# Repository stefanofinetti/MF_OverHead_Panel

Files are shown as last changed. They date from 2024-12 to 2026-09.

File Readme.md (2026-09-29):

# Overhead Panel

A compact Airbus A319/320/321 overhead panel for MobiFlight: 3D-printed
panels and Korry-style push buttons, the boards that carry every switch,
light and display, and the firmware for its three OLED displays.

The panel covers **ADIRS**, **AIR COND**, **ANTI ICE**, **APU**, **ELEC**,
**EXT LT**, **FUEL**, **GPWS** and **SIGNS**.

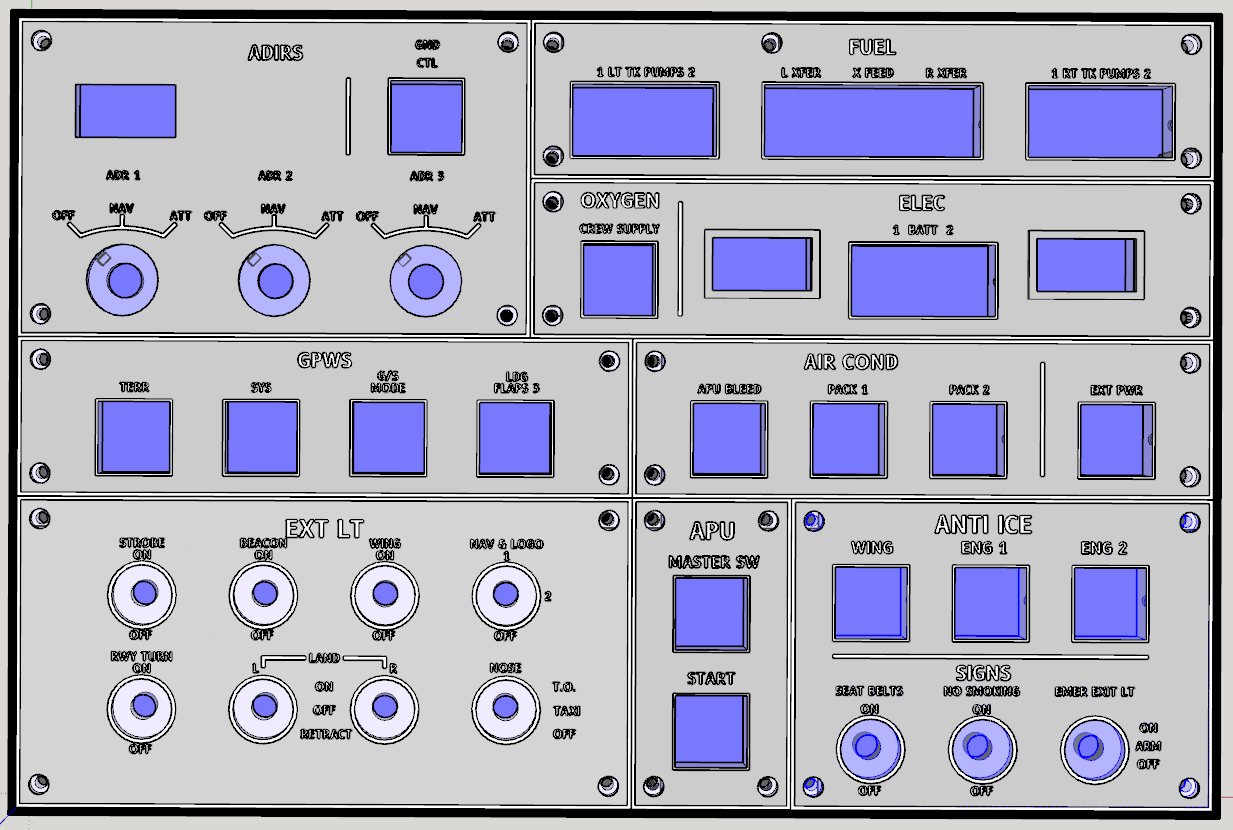
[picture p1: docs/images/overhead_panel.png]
The overhead panel as printed, from the 3D model


## v2 in short

v1 is one four-layer board, 313 × 206 mm, behind the whole panel. It works,
but it costs well over €100 once shipping and customs are added, and a
single mistake means reordering all of it.

v2 follows the printed panels instead: **eight small section boards, one
under each panel, and a 137 × 89 mm mainboard on the floor of the case**,
joined by ribbon cables. All nine are two-layer, 1.6 mm boards.

* **The printed parts do not change.** Panels, frames, Korry buttons and
  cases are the same. Only the floor of the lower-left case part is
  reprinted, with four bosses for the mainboard.
* **The section boards are cut out of the v1 layout.** Every switch, LED
  and hole stays at its v1 position, so each panel screws down exactly as
  before.
* **The pin map does not change.** Every switch is on the same ATmega pin
  and every annunciator on the same bit of the same shift-register chain,
  so the module config and the MobiFlight project stay valid. A few
  additions are listed under [Moving from v1](#moving-from-v1).

**Status (September 2026):** all nine boards are drawn and routed. ERC,
DRC and schematic parity are clean, and every ribbon and backlight pin was
checked against the board at the other end. **Nothing has been ordered or
built yet.** The firmware v2 needs is in `SF_OVHD` 1.2.0. The reprinted
case floor is still to do. v1 is the board that has been built and tested. It is
kept in `Kicad Files/` as the reference the v2 boards were cut from, **not
to be built**: build v2.

## What is in the repository

| Folder | What it holds |
|---|---|
| `Mainboard/` | The v2 mainboard: KiCad project, schematic (a root sheet and six sub-sheets) and routed PCB. See [its readme](Mainboard/README.md) |
| `Section_ADIRS/` … `Section_SIGNS/` | The eight v2 section boards, one KiCad project each, with a readme apiece |
| `Libraries/` | Parts shared by every v2 board: `OVHD.pretty` (Korry, toggle, ADR rotary, annunciator LED), `OVHD.kicad_sym`, and `3dmodels/` |
| `docs/board-split.md` | The v2 design document: decisions, power, annunciator currents, the ribbon pinouts, and why each choice was made |
| `SF_OVHD/` | The MobiFlight firmware and the installable Community package, with the module config for the panel. See [its readme](SF_OVHD/README.md) |
| `STL Files/` | Everything to print: one STL per filament colour for each panel, a ready `.3mf` for multi-colour printers, the Korry buttons and cases, the four case parts, the frames and the support |
| `STL Files/FaceDown_Printing/` | The APU panel redesigned to print face down. The other panels will follow |
| `STL Files/Levers/` | The exterior light levers and the paddle knobs |
| `3D Files/` | The SketchUp sources for the panel, the Korry buttons and the support |
| `Kicad Files/` | **v1**, for reference only: the single big board, as sent to JLCPCB on 3 March 2025. Do not build it |

`OverheadPanel.zip` is an older snapshot of `Kicad Files/` from January
2025, kept for reference.

## The boards

```
                        ┌─ ribbon ──► 8 section boards (switches, annunciators, backlight LEDs)
 9 V jack ─► mainboard ─┤
 USB-B    ─►            └─ 2 wires ─► 8 section boards (backlight, 9 V)
```

The mainboard carries every active part. The section boards carry only
their switches, LEDs and resistors, and the OLED sockets.

| Board | PCB (mm) | Switches | Annunciators | Backlight LEDs | Ribbon → mainboard | Backlight → mainboard |
|---|---|---|---|---|---|---|
| [ADIRS](Section_ADIRS/README.md) | 132.5 × 81.5 | 3 ADR rotaries, GND CTL | 1 | 18 | 20 pins → J701 | J601 |
| [FUEL](Section_FUEL/README.md) | 177.5 × 40 | 7 Korry | 14 | 14 | 26 pins → J702 | J602 |
| [ELEC](Section_ELEC/README.md) | 177.5 × 39.5 | 3 Korry | 5 | 10 | 20 pins → J703 | J603 |
| [GPWS](Section_GPWS/README.md) | 159.5 × 39 | 4 Korry | 6 | 9 | 14 pins → J704 | J604 |
| [AIR COND](Section_AIRCOND/README.md) | 150.5 × 39 | 4 Korry | 8 | 13 | 16 pins → J705 | J605 |
| [EXT LT](Section_EXTLT/README.md) | 159.5 × 79.5 | 8 toggles | — | 31 | 14 pins → J706 | J606 |
| [APU](Section_APU/README.md) | 39 × 79.5 | 2 Korry | 4 | 5 | 10 pins → J707 | J607 |
| [SIGNS](Section_SIGNS/README.md) | 108.5 × 79.5 | 3 Korry, 3 toggles | 6 | 22 | 16 pins → J708 | J608 |
| **Total** | | **49 inputs** | **44** | **122** | | |

The three OLEDs (BATT 1, BATT 2 on ELEC, ADIRS on ADIRS) plug into sockets
on their section boards, as on v1, and reach the mainboard through the
ribbon.

### The mainboard

137 × 89 mm, two layers, GND poured on both. The chips and connectors are on
top, and the small 1206 parts of the dense groups are underneath their chip.

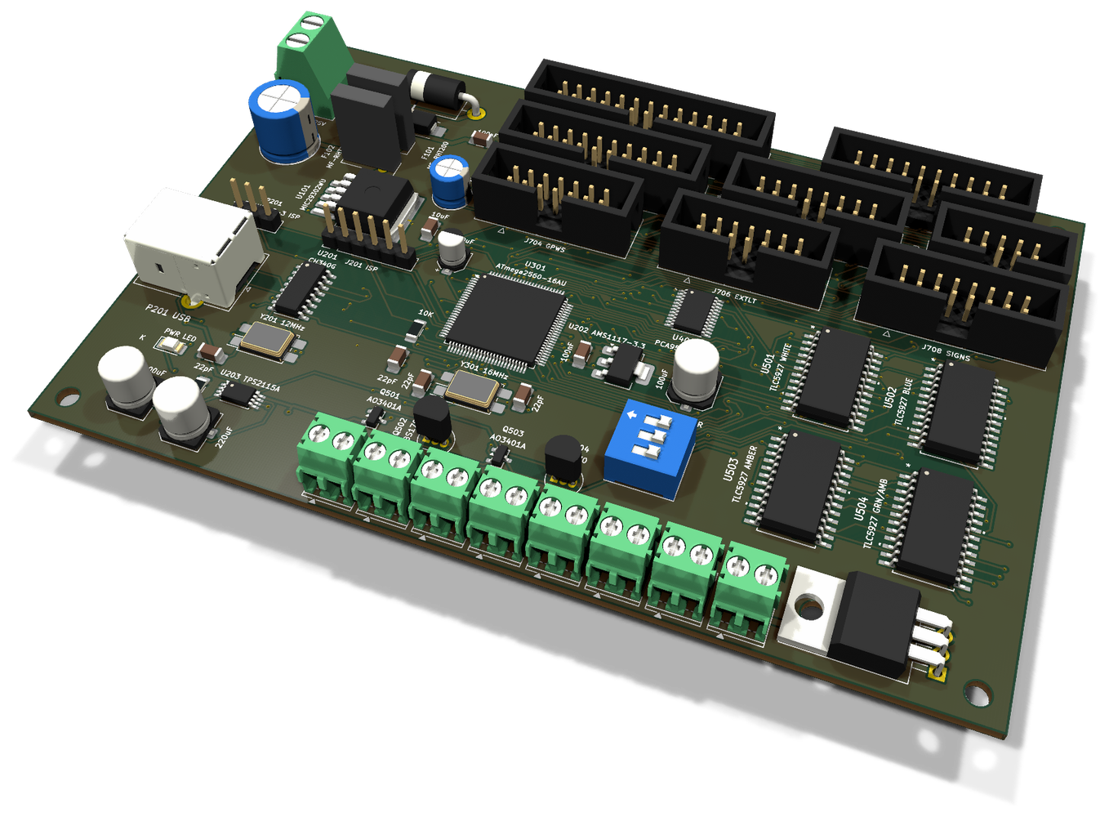
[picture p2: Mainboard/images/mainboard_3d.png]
The v2 mainboard, rendered by KiCad


* **Microcontroller:** ATmega2560 with a CH340G for USB. MobiFlight sees it
  as a Mega.
* **Power:** 9 V in through reverse protection, a TVS and a 470 µF bulk
  capacitor, then two resettable fuses, one for the backlight and one for
  the MIC29302 5 V regulator. A TPS2115A feeds the logic from that 5 V, or
  from USB when the 9 V is off. An AMS1117 makes 3.3 V for the PCA9548A
  and the OLEDs.
* **Annunciators:** four TI TLC5927 constant-current sinks, one per legend
  colour, in the two v1 chains (`ANN_LOWER`, `ANN_UPPER`). Each has a fixed
  1 kΩ on `R-EXT`, about 19 mA per LED. The trimmers of v1 are gone.
* **Three switches driven by the firmware:**
  * **D44:** backlight dimmer, an IRLIZ44N on the common return of the
    eight backlight branches;
  * **D45:** annunciator dimmer, on the LED anode rail;
  * **D46:** power to the four TLC5927, so they start clean however the
    9 V was plugged in.

  D44 and D45 undriven means dark.
* **Displays:** a PCA9548A I2C multiplexer at 0x71, channels 0–2 for
  BATT 1, BATT 2 and ADIRS.

### The section boards

* Every v1 part stays at its v1 coordinates. The new parts go on the
  **back**: the shrouded IDC header, the JST PH backlight connector and the
  few new resistors. Nothing new stands proud of the front.
* No ICs. The annunciator LEDs have no resistors, because the TLC5927 is a
  current sink.
* Backlight strings of two LEDs on 150 Ω, at 17 mA. Where the split leaves
  one LED alone (GPWS, AIR COND, EXT LT, APU), it gets 330 Ω for the same
  current.
* Each board sits in the middle of its A4 sheet. Its grid origin is set to
  where v1's (0, 0) lies, so KiCad shows v1 coordinates. The offset is in
  the title block.

## Building one

1. **Print** the panels, buttons, cases and frames from `STL Files/`.
2. **Reprint the floor of the lower-left case part** with four bosses and M3
   heat-set inserts for the mainboard. The mainboard's M3 holes are 4 mm in
   from its corners. The floor is free over 141 × 93.5 mm between the
   pillars. The reprinted floor is not drawn yet.
3. **Order the boards.** Run the Fabrication Toolkit plugin in each of the
   nine projects to make the Gerbers, BOM and positions. No v2 production
   files have been generated yet.
4. **Assemble.** Everything is sized for hand soldering: 1206 passives,
   7 × 5 mm crystals, generous spacing. Values, polarity, pin 1 and `K`
   marks are on the silkscreen of the side each part is on, so no
   schematic is needed at the bench. The per-board readmes list what to
   watch for.
5. **Cable it:**
   * one straight IDC ribbon per board, pin 1 to pin 1, from J1 on the
     section board to its J70x;
   * one pair of 22–24 AWG wires per board, from J2 (JST PH, `+` and `−` on
     the silkscreen) to its J60x screw terminal, pin 1 `+`;
   * the 9 V from a panel-mount 5.5 × 2.1 jack to J101 (pin 1 `+`);
   * USB through a panel-mount USB-B extension to P201.
6. **Burn the bootloader.** A new ATmega2560 is blank. J201 is an in-line
   ISP header: 1 VCC, 2 RESET, 3 MISO, 4 MOSI, 5 SCK, 6 GND. With JP201 on
   2–3, the programmer powers the MCU alone. Burn the Arduino Mega
   bootloader once, then put JP201 back on 1–2. From then on, the board is
   flashed over USB like a Mega.
7. **Install the firmware and the module config**, as described in
   [the firmware readme](SF_OVHD/README.md), then bind the switches and
   lights in your MobiFlight project.

A 9 V / 3 A adapter is enough. The backlight takes about 1.1 A, and a light
test with all 44 annunciators lit adds about 1 A.

## Moving from v1

The pin map is the same, so the v1 module config and project keep working,
with these changes:

* **Flash `SF_OVHD` 1.2.0 or later.** Its custom device powers the TLC5927
  up through D46 once the board has started. With older or stock MobiFlight
  firmware the annunciators stay dark on v2.
* **Load the module config from the 1.2.0 package.** It adds two PWM outputs,
  `BL_PWM` on D44 (backlight) and `ANN_PWM` on D45 (annunciators). D46 is not
  in it, because the custom device owns it.
* **Two new rows in the MobiFlight project** to drive them, typically INTEG
  LT for D44 and ANN LT BRT/DIM for D45. At 0, or with the Connector
  closed, the backlight and the annunciators are dark.
* **NO SMOKING:** v1 read it on the toggle's other contact, and the
  MobiFlight row was inverted to make up for it. v2 reads it like every
  other toggle, so **remove the inversion** on that row.

## Known issues

* **The ADIRS panel labels its rotaries in the wrong order.** The printed
  panel reads ADR 1, ADR 2, ADR 3 from left to right. On the A320 the order
  is IR 1, IR 3, IR 2, and that is how the board is wired, on v1 and v2
  alike: the middle rotary is IR 3 and the right one is IR 2. The `.mfmc`
  follows the board. Only the printed labels are wrong, so read the middle
  knob as 3 and the right one as 2 until the panel is reprinted.

## Software

* [KiCad](https://www.kicad.org/) 10, for the v2 boards. The files are
  saved by KiCad 10 and do not open in older versions
* [Freerouting](https://github.com/freerouting/freerouting), only to
  reroute a board
* [SketchUp](https://www.sketchup.com), to change the printed parts
* [VS Code](https://code.visualstudio.com/) with
  [PlatformIO](https://platformio.org/), to build the firmware
* [MobiFlight](https://www.mobiflight.com/)

```bash
git clone https://github.com/stefanofinetti/MF_OverHead_Panel.git
```

## License

This code and all the items are released under the GPLv3.0 license. Feel free
to use them as you wish, as long as you redistribute the source code.
A mention would be nice, though, if you use this work: I invested a good
many hours in it, just for the amazing MobiFlight community.

## Acknowledgements

This project couldn't have seen the light without the excellent work, and
kind support, of [GaGagu](https://github.com/gagagu) and
[ElRal](https://github.com/elral). Their work is amazing, so please have a
look at their repositories.

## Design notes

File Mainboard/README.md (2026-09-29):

# OVHD Mainboard (v2)

The v2 mainboard: the microcontroller, power, annunciator drivers and
display multiplexer for the whole overhead. It sits on the floor of the
lower-left case part and reaches the eight section boards through ribbons
and backlight wires. The reasoning behind every choice is in
[`docs/board-split.md`](../docs/board-split.md).

* **PCB:** 137 × 89 mm, 2 layers, 1.6 mm, GND poured on both sides.
* **Fixing:** four M3 holes, 4 mm in from the corners, for bosses with
  heat-set inserts in the reprinted case floor.
* **Parts:** 123. 65 of them are on the bottom.
* **Status:** routed with Freerouting. ERC, DRC (every warning on) and
  schematic parity are clean. Not yet ordered.

Mainboard, 3D view

**Top**, with the chips and connectors:

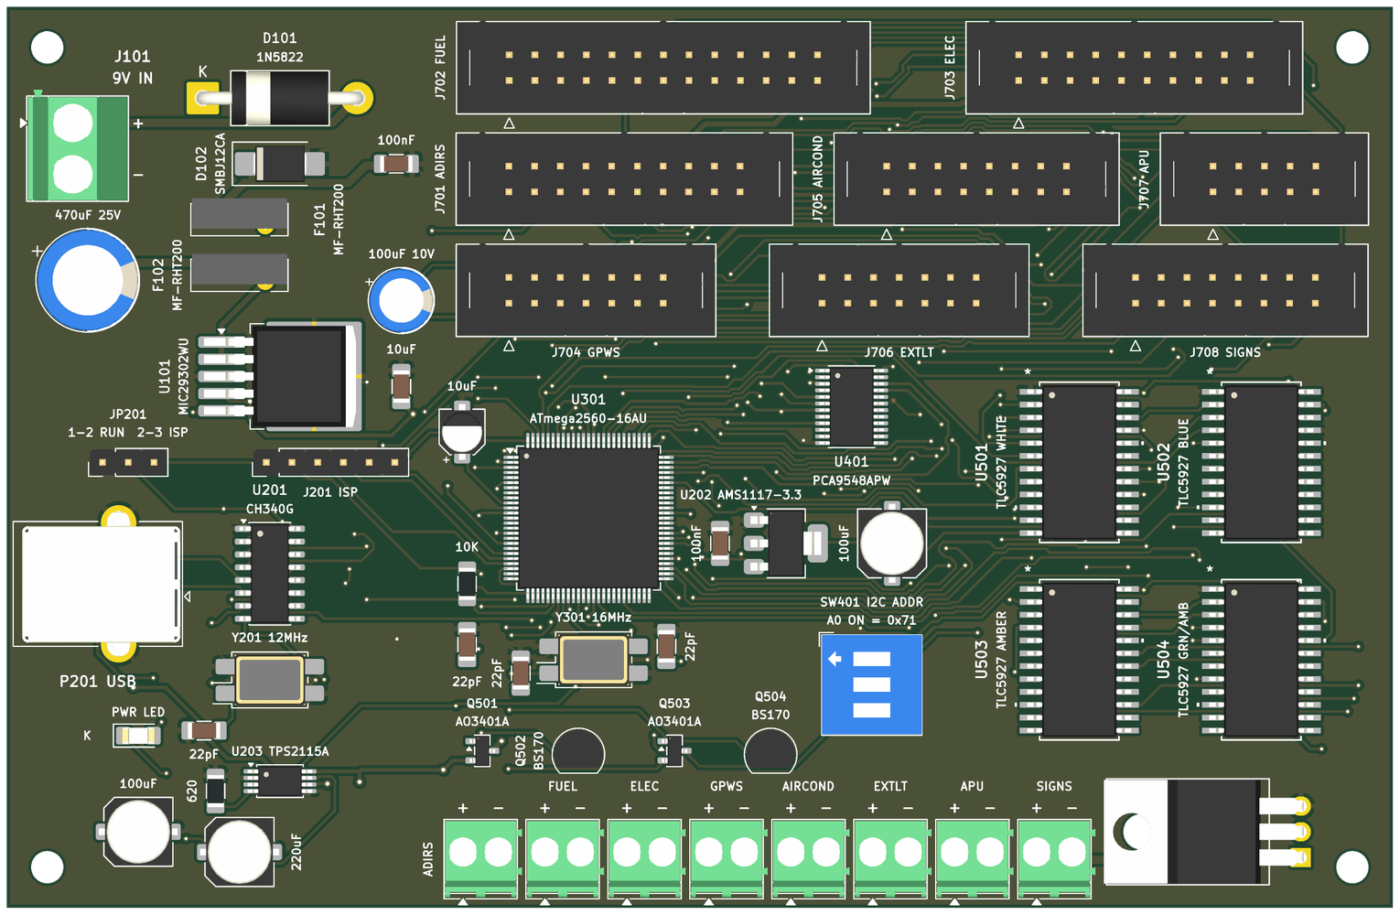
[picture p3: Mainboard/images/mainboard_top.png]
Mainboard, top


**Bottom**, with the small 1206 parts under their chips:

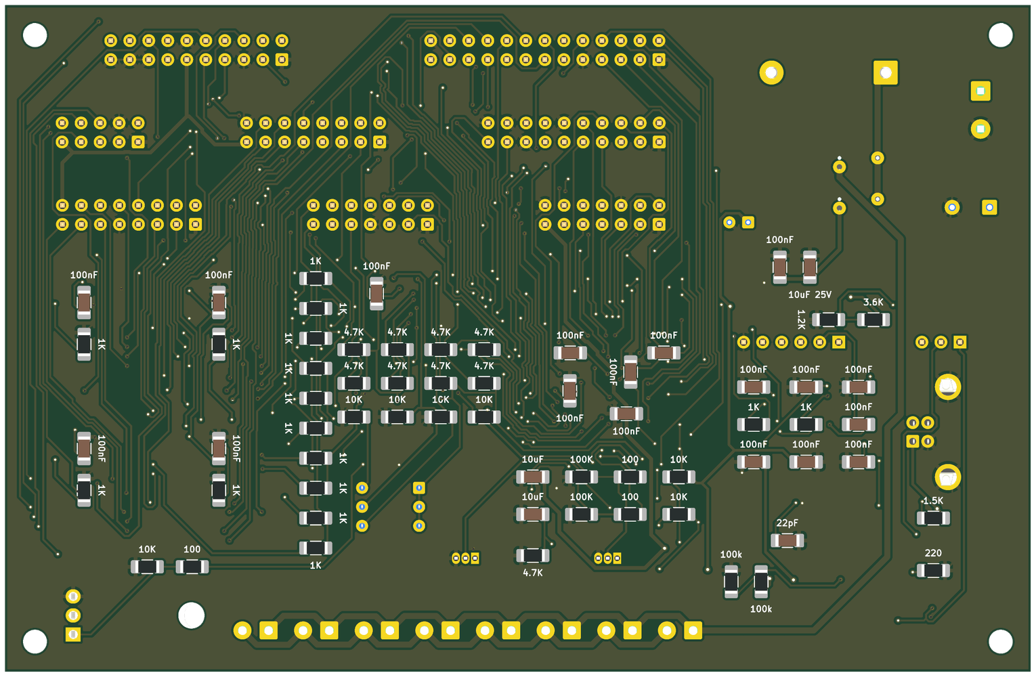
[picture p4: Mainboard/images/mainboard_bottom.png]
Mainboard, bottom


Rendered by KiCad from the board file. The bottom is seen from below, so it
is mirrored against the top.

## Schematic

| Sheet | What is on it |
|---|---|
| `power.kicad_sch` | 9 V in, reverse diode, TVS, bulk capacitor, the two fuses, MIC29302 (5 V) |
| `usb_supply.kicad_sch` | USB-B, CH340G, TPS2115A supply selector, AMS1117 (3.3 V), ISP header, JP201 |
| `mcu.kicad_sch` | ATmega2560, 16 MHz crystal, reset, decoupling |
| `i2c.kicad_sch` | PCA9548A, address switch, pull-ups |
| `annunciators.kicad_sch` | The four TLC5927, the anode dimmer (D45) and the TLC5927 supply switch (D46) |
| `connectors.kicad_sch` | The eight ribbon headers, the eight backlight terminals, the backlight dimmer (D44) |

Local libraries: `TLC5927.kicad_sym` / `TLC5927.pretty` and
`TPS2115A.kicad_sym`. Every part has a description field that says why it
is there and, where it replaces a v1 part, which one.

## Connectors and settings

| Ref | What | Notes |
|---|---|---|
| J101 | 9 V in, 5.08 mm screw terminal | From the panel-mount 5.5 × 2.1 jack. Pin 1 `+` |
| P201 | USB-B | To the panel-mount USB-B extension |
| J201 | ISP header, 1 × 6 | 1 VCC, 2 RESET, 3 MISO, 4 MOSI, 5 SCK, 6 GND |
| JP201 | Power selector | 1–2: MCU from the board's 5 V (normal use). 2–3: MCU from J201's VCC only, to burn the bootloader |
| SW401 | PCA9548A address | All off = 0x70. **Set A0 on: the board runs at 0x71**, which `SF_OVHD` expects |
| J701–J708 | Ribbons to ADIRS, FUEL, ELEC, GPWS, AIR COND, EXT LT, APU, SIGNS | Shrouded, keyed. Straight ribbon, pin 1 to pin 1. Each is labelled on the silkscreen with its board |
| J601–J608 | Backlight to the same eight boards, in the same order | 3.5 mm screw terminals. Pin 1 `+9V_BL`, pin 2 the switched return |

The pinout of every ribbon is in the design document, under *Ribbon
pinouts*.

## Annunciator drivers

| Ref | Colour | Chain and bits | v1 ref |
|---|---|---|---|
| U501 | white | `ANN_LOWER` 0–15 | U6 |
| U502 | blue | `ANN_LOWER` 16–31 | U7 |
| U503 | amber | `ANN_UPPER` 0–15 | U8 |
| U504 | green and amber | `ANN_UPPER` 16–31 | U5 |

`ANN_LOWER` has its latch on D23, clock on D24 and data on D22. `ANN_UPPER`
has its latch on D27, clock on D26 and data on D25, as on v1.

* **`R-EXT` is a fixed 1 kΩ (R501–R504):** I = 1.25 V / R × 15 ≈ 19 mA
  per LED. If you ever change it, stay between ~160 Ω and ~1.9 kΩ, the
  chip's range at power-up.
* **Nothing else on `R-EXT`,** above all no capacitor. On the v1 board a
  100 nF there made the chips drop their outputs as soon as two or three
  were on together. See the design document.
* **`OE` is tied hard to GND.** On the TLC5927 it is also the mode pin, so
  it must never get PWM.
* **1 kΩ in series on CLK, LE and SDI (R511–R520),** at the chips' end.

## Pins the firmware drives

| Pin | Drives | Undriven or low |
|---|---|---|
| D44 | Q601 (IRLIZ44N), the common return of the backlight | backlight off |
| D45 | Q501/Q502, the annunciator anode rail `+5V_LED` | annunciators dark |
| D46 | Q503/Q504, the TLC5927 supply | TLC5927 unpowered |

D44 and D45 are plain MobiFlight PWM outputs, `BL_PWM` and `ANN_PWM` in the
`.mfmc`. D46 belongs to the `SF_OVHD` custom device, from firmware 1.2.0. It
powers the chips up after the board has started, and again on message 5. See
[the firmware readme](../SF_OVHD/README.md#annunciator-power-up-d46).

## Assembly notes

* **Bottom side:** the 1206 parts of the dense groups, each under its chip:
  * the MCU and CH340G decoupling and crystal parts;
  * the I2C pull-ups;
  * the TLC5927 `R-EXT` resistors, VDD capacitors and series resistors;
  * the resistors of the three MOSFET switches;
  * the MIC29302 feedback divider and capacitors.

  Solder the bottom side first, then the top.
* **Q601** lies flat on its isolated tab. At ~1.1 A it needs no heatsink.
* **The polarity marks are on the silkscreen:** the electrolytics, the `K` at D101
  and at the power LED D201, and `+` and `−` at J101 and at every
  backlight terminal. D102 (SMBJ12CA) is bidirectional: it fits either way round.
* **Before flashing any firmware,** burn the bootloader through
  J201 with JP201 on 2–3, then move JP201 back to 1–2.

## Design rules

| Net class | Track | Clearance | Nets |
|---|---|---|---|
| HiCurrent | 0.8 mm | 0.3 mm | `VIN_RAW`, `+9V`, `+9V_BL`, `BL_RET` |
| Power | 0.5 mm | 0.25 mm | `+9V_REG`, `+5V_LED` |
| PowerNarrow | 0.35 mm | 0.2 mm | `5V_EXT`, `VBUS`, the widest that enters the TPS2115A's 0.65 mm pins |
| Default | 0.25 mm | 0.2 mm | everything else |

The minimum track is 0.15 mm, for a few escapes between TQFP and SOIC pins,
within JLCPCB's 0.127 mm.

## Mechanical

* The board is drawn in v1 coordinates, at x 32–169, y 134.5–223.5, under
  EXT LT and the lower edge of GPWS. That way it can be checked against the
  section boards above it.
* EXT LT's J1 and J2 hang over the TLC5927 block, where nothing is taller
  than a SOIC. No ribbon header sits under another board's connector.
* With today's case there are 27 mm from the floor to the underside of the
  section boards. The reprinted floor is meant to raise that to 30–35 mm.

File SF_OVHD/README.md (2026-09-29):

# SF OVHD — firmware

MobiFlight firmware for the overhead panel mainboard. It is standard
MobiFlight for the ATmega2560, plus one custom device, `SF_OVHD`. The custom
device does two things:

* it drives the three OLED displays: the BATT 1 and BATT 2 voltmeters and
  the ADIRS display;
* on the v2 mainboard, it powers up the four TLC5927 annunciator drivers,
  through D46, once the board has started. See
  [Annunciator power-up](#annunciator-power-up-d46).

The 49 switches and the annunciator lights do not go through the custom
device. They are plain MobiFlight buttons and output shifters, configured in
the Connector like on any other board. The two dimmers are plain MobiFlight
PWM outputs.

## Installing

1. Build the Community package `SF_OVHD_<version>.zip` as described
   below.
2. Extract it into the `Community` folder of your MobiFlight installation,
   so you end up with `Community\SF_OVHD\`. Restart the Connector.
3. Flash the board from the Connector. It shows up as **SF OVHD Mega**.
4. Load the module config `SF OVHD Mainboard.mfmc`, which comes with the
   package. It has every switch, both annunciator chains (`ANN_UPPER` and
   `ANN_LOWER`), the two dimmer outputs and the custom device at 0x71, on
   the pins the board uses.
5. In your MobiFlight project, bind the switches and annunciators to your
   aircraft, drive the two dimmers, and send the display values with the
   messages below.

## Dimmers

Two PWM outputs in the `.mfmc`, driven like any MobiFlight output with PWM
on, 0–255:

| Output | Pin | Dims | At 0, undriven or in power saving |
|---|---|---|---|
| `BL_PWM` | D44 | the backlight of the eight section boards (IRLIZ44N on their common return) | backlight off |
| `ANN_PWM` | D45 | the annunciators (AO3401A on their anode rail, `+5V_LED`) | annunciators dark |

Typically `BL_PWM` follows INTEG LT and `ANN_PWM` the ANN LT BRT/DIM
switch. **With neither bound, the backlight and the annunciators stay dark.**
They are on the v2 mainboard only; on v1, D44 and D45 are not connected.

## Messages

In the Connector, an output of type *Custom Device* on `SF OVHD` can send:

| ID | Label | Value |
|---|---|---|
| 0 | Battery 1 Voltage | shown as sent, e.g. `28.63` |
| 1 | Battery 2 Voltage | shown as sent |
| 2 | Adirs message | shown as text, e.g. `On Batt` |
| 3 | Light test | `1` shows the test picture on all three displays, `0` goes back to the values |
| 4 | Brightness | `0`–`100`, the contrast of all three displays |
| 5 | Reset annunciators | any value: the four TLC5927 lose their supply for 0.3 s, then both chains are written again. See [Annunciator power-up](#annunciator-power-up-d46) |

The Connector also sends two messages of its own. Both switch all three
displays off, since a picture left standing for hours burns into an OLED:

| ID | When |
|---|---|
| −1 | the Connector closes |
| −2 | the Connector enters power saving, after the 600 s set in the `.mfmc` |

The next value that arrives lights its display again.

A few details worth knowing:

* **An empty value blanks its display.** Use that for a display that
  should be dark, for instance while its bus is unpowered.
* **The voltages are right-aligned on the digit cells.** DSEG14 gives every
  digit a 32-pixel cell and the point none, so `28.80` fills the 128 pixels
  and `9.80` starts one cell in, with each digit in its usual column. Send
  them already formatted: the firmware prints what it gets.
* **Brightness** is meant for the ANN LT BRT/DIM switch, which dims these
  displays in the aircraft, or for a dimmer knob. Until the first value
  arrives, the displays keep their driver's default. An empty value is
  ignored. It sets the OLED contrast register: even at 0 the displays are
  dimmer but still plainly lit. After a new module config is uploaded, the
  displays start again at the default until the Connector sends the value
  once more.

## Annunciator power-up (D46)

The TLC5927 has no reset pin. On a hot-plugged 9 V supply it can start in a
bad state and keep it until its supply goes away. On the v2 mainboard the
chips' supply, `+5V_TLC`, goes through a switch on **D46** (`TLC_PWR_EN`):
high = powered. Undriven, the switch stays off, so the chips get no supply
until the firmware gives it.

When the custom device starts, which happens every time the board boots or a
module config is uploaded, it:

1. pulls CLK, LE and SDI of both chains (D22–D27) low. A CMOS input held
   high feeds an unpowered chip through its protection diode, and the core's
   output shifter leaves LE high after every update;
2. drives D46 low, so the chips are unpowered;
3. after 300 ms drives D46 high;
4. after another 20 ms writes both chains again, with what the Connector
   last set, or all dark in power saving.

Message 5 runs the same sequence on demand. It does not block the loop: the
steps run from the custom device's `update()`, every 10 ms
(`MF_CUSTOMDEVICE_HAS_UPDATE`, `MF_CUSTOMDEVICE_POLL_MS=10`). Annunciator
commands that arrive meanwhile are kept, and written once the chips are back.
The pins are fixed in `SF_OVHD/TLCSupply.cpp` and must match the `.mfmc`.

* **300 ms take the chips all the way to 0 V.** R527, 4.7 kΩ, bleeds the
  10.4 µF on `+5V_TLC`: a time constant of 49 ms, so after 300 ms about
  10 mV are left. The TLC5927 datasheet gives no reset threshold, so
  nothing shorter is relied on.
* **D46 is not in the `.mfmc`, and the package's `board.json` does not
  offer it,** so the Connector cannot give it to another device.
* **The Connector cannot bring the annunciators up with stock MobiFlight
  firmware** on v2. Nothing would drive D46.
* **On v1 the sequence is harmless:** D46 is not connected there, and the
  chains only see their lines held low for 0.3 s at startup.

## Displays and address

The three displays hang off a PCA9548A, one per channel:

| Channel | Display |
|---|---|
| 0 | BATT 1 |
| 1 | BATT 2 |
| 2 | ADIRS |

The channel numbers live in `SF_OVHD/SF_OVHD.h`.

The custom device's only setting is the address of the PCA9548A, set by the
DIP switch on the board: all off is 0x70. The address also picks the display
driver, which is easy to miss:

* **even** address (0x70, 0x72 …) → **SH1106**
* **odd** address (0x71, 0x73 …) → **SSD1306**

The board is configured at 0x71, i.e. SSD1306, and the shipped `.mfmc` is set
to match. With SH1106 displays, move the DIP switch to an even address and
change the custom device to match.

## Building

The project is PlatformIO, usually run from VS Code. The extension does not
put `pio` on the PATH. Either open a terminal from the PlatformIO toolbar, or
call it by its full path, `%USERPROFILE%\.platformio\penv\Scripts\pio.exe`.

```
pio run -e SF_OVHD_mega
```

That produces version `0.0.1`. For a real one, set `VERSION`. The build
stamps it into both the firmware filename and `board.json`, and the two have
to agree or MobiFlight will not find the firmware. It has to be an
environment variable, so the syntax differs per shell:

```
rem cmd.exe
rmdir /s /q _build _dist
set "VERSION=1.2.0" && pio run -e SF_OVHD_mega
```

```
# PowerShell
Remove-Item -Recurse -Force _build, _dist -ErrorAction SilentlyContinue
$env:VERSION = "1.2.0"; pio run -e SF_OVHD_mega
```

```
# bash
rm -rf _build _dist
VERSION=1.2.0 pio run -e SF_OVHD_mega
```

The result is the installable ZIP in `_dist/`.

Two traps:

* **Delete `_build` and `_dist` first.** `copy_fw_files.py` only stamps the
  version into `board.json` when `_build/` does not exist yet, so a leftover
  folder ships the previous version's json.
* **The ZIP is only rebuilt when the firmware recompiles.** After changing
  nothing but a file under `Community/`, run
  `pio run -e SF_OVHD_mega -t clean` first.

On the first build, `get_CoreFiles.py` clones the MobiFlight core into
`src/`, which is not in the repository.

## How it is put together

### What it follows

The reference is **MobiFlight's own scaffolding**: the project layout,
`platformio.ini`, the build scripts and `MFCustomDevice.*` follow
[MobiFlight/CommunityTemplate](https://github.com/MobiFlight/CommunityTemplate),
and `custom_core_firmware_version` is kept at the core release the template
points to, currently **3.1.4**. Where this project departs from the template:

| | |
|---|---|
| Device type | `SF_OVHD`. `SF_OVHD_MAINBOARD`, the January 2025 name, is accepted too, so a board configured back then keeps its displays |
| `SERIAL_RX_BUFFER_SIZE` | 256, not the template's 96, see below |
| Device families | buttons, output shifters and the custom device only |
| Targets | Mega only, the board has a soldered ATmega2560 |

### Serial receive buffer

Redrawing a display pushes a 1 KB frame over I2C at 400 kHz, about 25 ms
during which the loop reads nothing. At 115200 baud close to 300 bytes can
arrive in that window, so the template's 96-byte buffer would drop
characters. Do not lower it.

### Memory

The ATmega2560 has 8 KB of RAM, and MobiFlight reserves most of it up
front: 1600 bytes for the device arena (`MF_MAX_DEVICEMEM`) and 1000 for
the input names (`MEMLEN_NAMES_BUFFER`). Those two are sized for the
Connector config, not for this code, and are the wrong place to economise.

What this project does instead:

* **`build_unflags` turns off the device families the panel does not
  have**: segment displays, character LCD, steppers, servos, analog inputs,
  input shifters and both multiplexers. Output shifters stay on, because the
  annunciators are TLC5927 chains. Buttons, encoders and outputs are core
  and always present. To get a family back, delete its line in
  `SF_OVHD/sf_ovhd_platformio.ini`.
* **No `String` anywhere.** The values from the Connector live in fixed
  buffers, so a redraw allocates nothing and the heap cannot fragment. The
  only allocation in the whole firmware is Adafruit's 1 KB frame buffer,
  taken once at startup.

The result uses about 50% of the RAM and 16% of the flash.

### Files

| File | |
|---|---|
| `SF_OVHD/SF_OVHD.cpp`, `.h` | the three displays: drawing, messages, channels |
| `SF_OVHD/TLCSupply.cpp`, `.h` | the TLC5927 power-up on D46 |
| `SF_OVHD/OLEDInterface.h` | one interface over the SSD1306 and SH1106 drivers |
| `SF_OVHD/MFCustomDevice.cpp`, `.h` | the glue to the MobiFlight core, as in the template |
| `SF_OVHD/Fonts/` | GFX fonts. Two are used, DSEG14 Modern 20 pt and, from Adafruit GFX, FreeSans 18 pt |
| `SF_OVHD/Community/` | what goes into the package: board, device, module config, reset image |

## Credits

`OLEDInterface.h` and the fonts come from Gagagu's
[A320 EFIS/FCU display](https://github.com/gagagu/Mobiflight-A320-Efis-Fcu-Display-with-ESP32)
by way of [elral/MF_FCU_EFIS_OLEDs](https://github.com/elral/MF_FCU_EFIS_OLEDs),
the same base as the SF FCU firmware. The DSEG fonts are
[keshikan/DSEG](https://github.com/keshikan/DSEG). It could not have been
done without them.

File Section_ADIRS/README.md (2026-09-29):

# ADIRS section board (v2)

The v2 board under the ADIRS panel. It carries the panel's switches, annunciator LEDs and backlight, at their v1 positions, and reaches the mainboard through one ribbon and one pair of backlight wires. There are no ICs on it. The design rules shared by the eight section boards are in [`docs/board-split.md`](../docs/board-split.md).

* **PCB:** 132.5 × 81.5 mm, 2 layers, 1.6 mm. Every v1 hole is kept.
* **Status:** routed with Freerouting. ERC, DRC and schematic parity are clean. Not yet ordered.

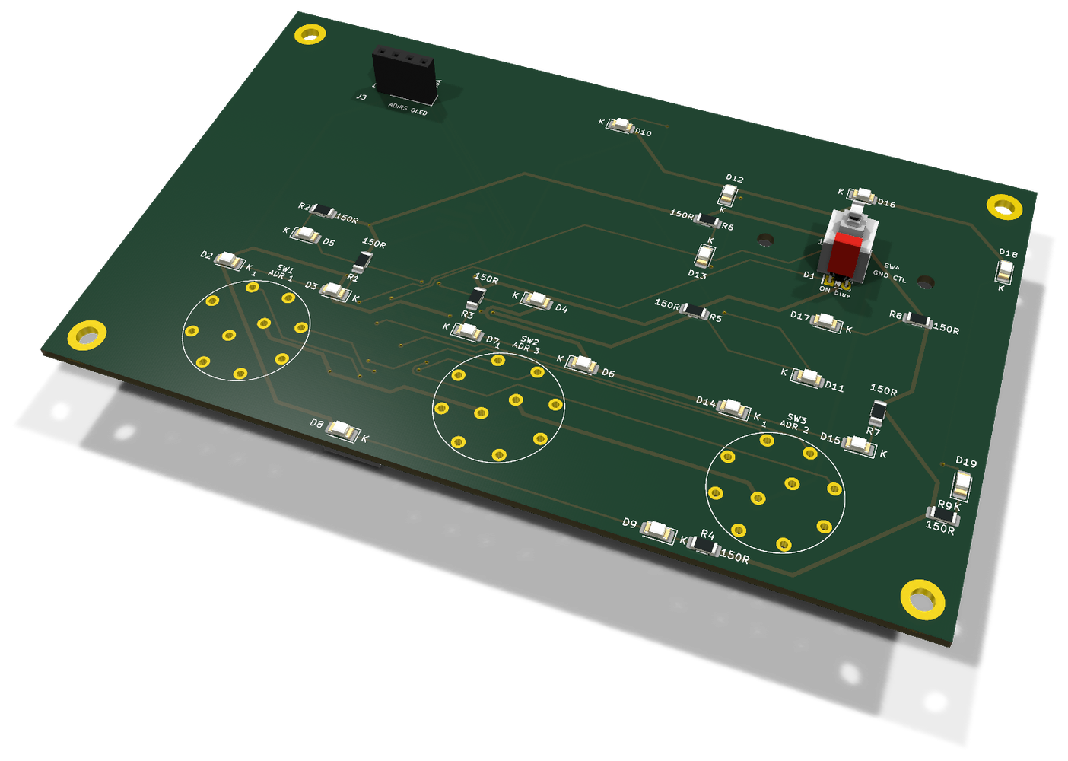
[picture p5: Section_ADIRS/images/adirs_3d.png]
ADIRS board, 3D view


**Top**, the panel side:

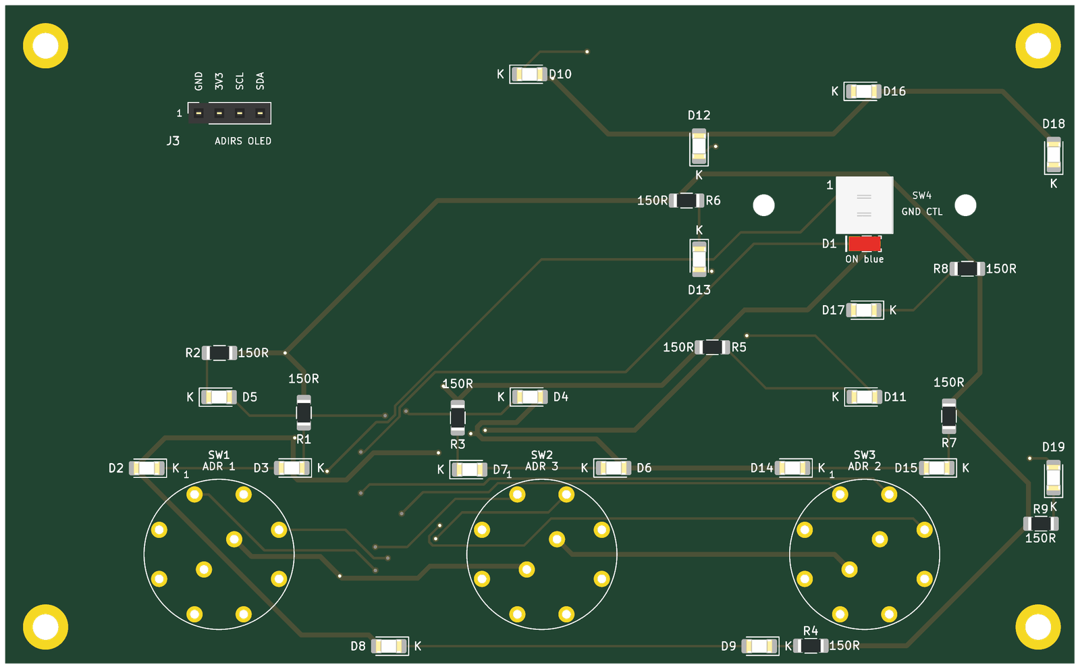
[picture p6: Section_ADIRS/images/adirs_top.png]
ADIRS, top


**Bottom**, with the connectors:

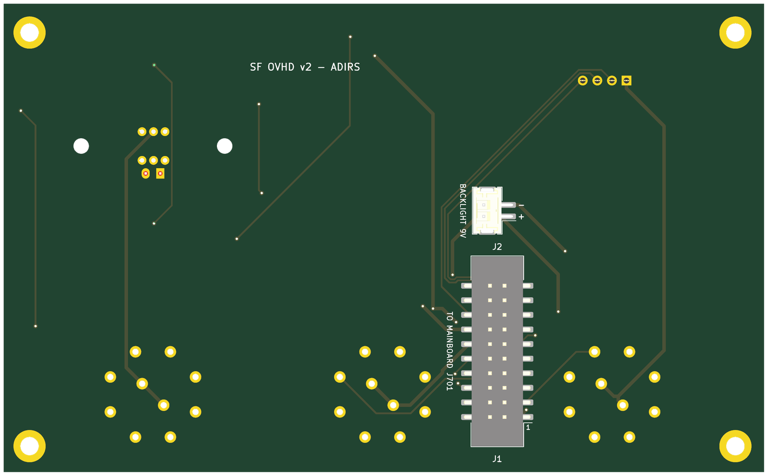
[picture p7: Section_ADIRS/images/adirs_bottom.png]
ADIRS, bottom


Rendered by KiCad from the board file. The bottom is seen from below, so it is mirrored against the top. The ADR rotaries have no 3D model yet and show as pads only.

## Connectors

Both are new on v2 and sit on the **back**, so nothing new stands proud of the front.

| Ref | What | Goes to |
|---|---|---|
| J1 | Shrouded IDC header, 20 pins, SMD | J701 on the mainboard, straight ribbon, pin 1 to pin 1 |
| J2 | JST PH, 2 pins, SMD. Pin 1 `+9V_BL` (`+`), pin 2 the switched return (`−`) | screw terminal J601 on the mainboard |

J1 and J2 are on the back between ADR 1 and ADR 3.

The signal on every ribbon pin is in the design document: [ADIRS — 20 pins](../docs/board-split.md#adirs--20-pins).

## Switches

| Ref | Switch | Type | v1 ref |
|---|---|---|---|
| SW1 | ADIRS ADR 1 | ADR rotary | SW25 |
| SW2 | ADIRS ADR 3 | ADR rotary | SW26 |
| SW3 | ADIRS ADR 2 | ADR rotary | SW27 |
| SW4 | ADIRS GND CTL | Korry | SW24 |

## Annunciators

Anodes on `+5V_LED` from the ribbon, cathodes back down the ribbon to their TLC5927 output. No resistors: the TLC5927 sets the current.

| Ref | Colour | Legend | Chain bit | Driver | v1 ref |
|---|---|---|---|---|---|
| D1 | blue | `GND_CTL_ON` | `ANN_LOWER` 16 | U502 (v1 U7) | D109 |

## Backlight

18 LEDs, 1206 (D2–D19), on 9 V, in 9 strings of two with 150 Ω (R1–R9). Each string runs at about 17 mA. `K` marks every cathode on the silkscreen.

## Assembly notes

* **SW2, in the middle, is IR 3, and SW3, on the right, is IR 2**, as on the A320 (IR 1, IR 3, IR 2 from left to right) and in the `.mfmc`. The v1 footprints were labelled the other way round; the copper decides.
* Rotary positions: 1 OFF, 2 NAV, 3 ATT; common on pin 9, to GND.
* J3 is the ADIRS OLED socket, where it was on v1: 1 GND, 2 +3V3, 3 SCL, 4 SDA, on PCA9548A channel 2.
* GND CTL is on this board because that is where it sits under the printed panel.
* There is no 3D model of the ADR rotary yet, so the render shows only its pads.
* Every part has its value, polarity or pin 1 on the silkscreen of its own side. Each part's description in the schematic names its v1 reference.

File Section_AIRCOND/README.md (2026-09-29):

# AIR COND section board (v2)

The v2 board under the AIR COND panel. It carries the panel's switches, annunciator LEDs and backlight, at their v1 positions, and reaches the mainboard through one ribbon and one pair of backlight wires. There are no ICs on it. The design rules shared by the eight section boards are in [`docs/board-split.md`](../docs/board-split.md).

* **PCB:** 150.5 × 39 mm, 2 layers, 1.6 mm. Every v1 hole is kept.
* **Status:** routed with Freerouting. ERC, DRC and schematic parity are clean. Not yet ordered.

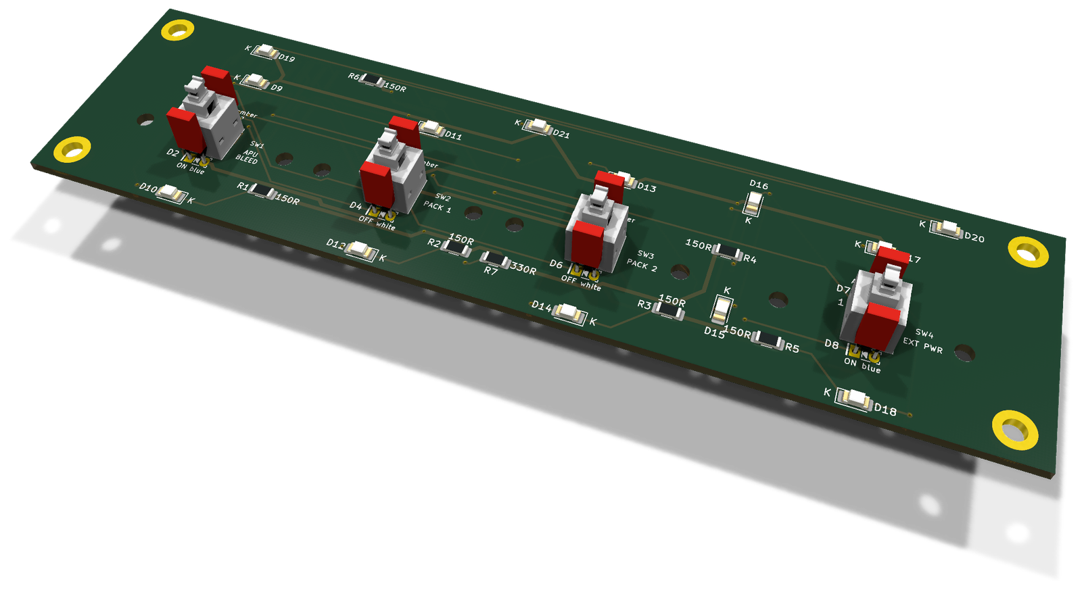
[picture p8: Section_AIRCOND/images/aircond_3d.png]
AIR COND board, 3D view


**Top**, the panel side:

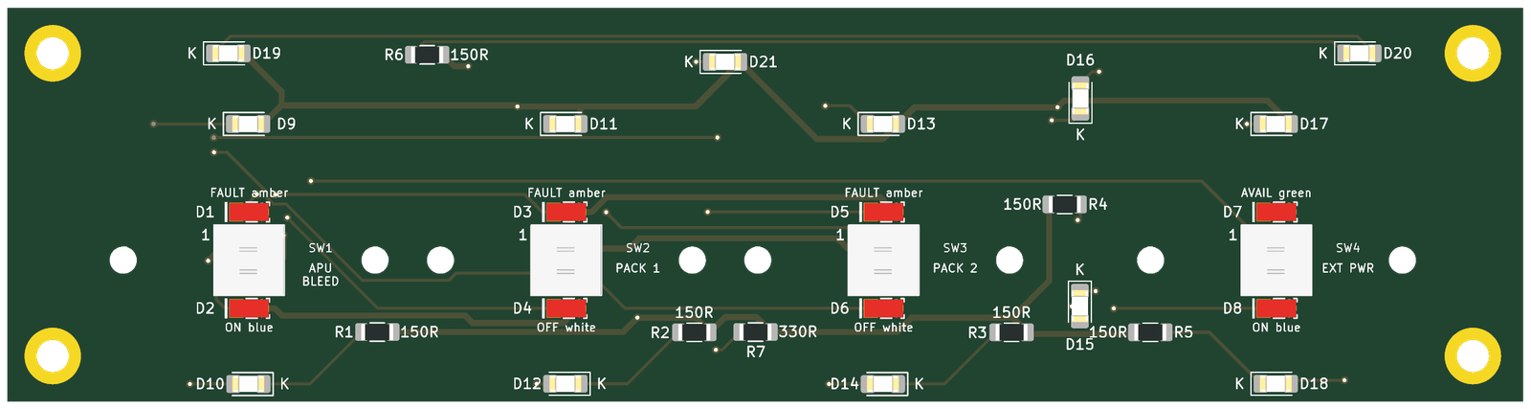
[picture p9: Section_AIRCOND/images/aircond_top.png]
AIR COND, top


**Bottom**, with the connectors:

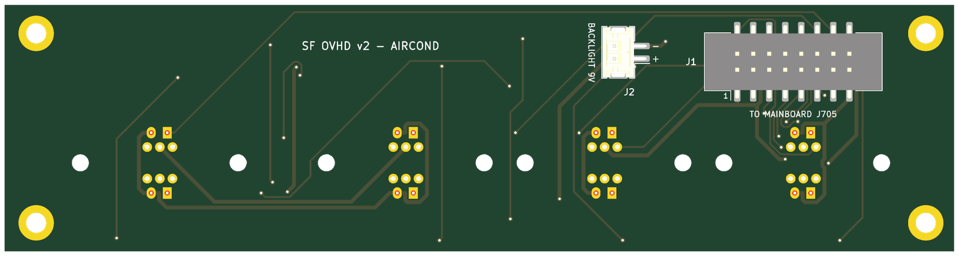
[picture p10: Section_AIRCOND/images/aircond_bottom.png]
AIR COND, bottom


Rendered by KiCad from the board file. The bottom is seen from below, so it is mirrored against the top.

## Connectors

Both are new on v2 and sit on the **back**, so nothing new stands proud of the front.

| Ref | What | Goes to |
|---|---|---|
| J1 | Shrouded IDC header, 16 pins, SMD | J705 on the mainboard, straight ribbon, pin 1 to pin 1 |
| J2 | JST PH, 2 pins, SMD. Pin 1 `+9V_BL` (`+`), pin 2 the switched return (`−`) | screw terminal J605 on the mainboard |

J1 and J2 are along the top edge on the left, the side nearest the mainboard.

The signal on every ribbon pin is in the design document: [AIR COND — 16 pins](../docs/board-split.md#air-cond--16-pins).

## Switches

| Ref | Switch | Type | v1 ref |
|---|---|---|---|
| SW1 | AIRCOND APU BLEED | Korry | SW10 |
| SW2 | AIRCOND PACK 1 | Korry | SW11 |
| SW3 | AIRCOND PACK 2 | Korry | SW12 |
| SW4 | AIRCOND EXT PWR | Korry | SW13 |

## Annunciators

Anodes on `+5V_LED` from the ribbon, cathodes back down the ribbon to their TLC5927 output. No resistors: the TLC5927 sets the current.

| Ref | Colour | Legend | Chain bit | Driver | v1 ref |
|---|---|---|---|---|---|
| D1 | amber | `APU_BLEED_FAULT` | `ANN_UPPER` 29 | U504 (v1 U5) | D87 |
| D2 | blue | `APU_BLEED_ON` | `ANN_LOWER` 25 | U502 (v1 U7) | D129 |
| D3 | amber | `PACK1_FAULT` | `ANN_UPPER` 30 | U504 (v1 U5) | D89 |
| D4 | white | `PACK1_OFF` | `ANN_LOWER` 8 | U501 (v1 U6) | D90 |
| D5 | amber | `PACK2_FAULT` | `ANN_UPPER` 31 | U504 (v1 U5) | D91 |
| D6 | white | `PACK2_OFF` | `ANN_LOWER` 12 | U501 (v1 U6) | D92 |
| D7 | green | `EXT_PWR_AVAIL` | `ANN_UPPER` 19 | U504 (v1 U5) | D99 |
| D8 | blue | `EXT_PWR_ON` | `ANN_LOWER` 21 | U502 (v1 U7) | D126 |

## Backlight

13 LEDs, 1206 (D9–D21), on 9 V: 6 strings of two with 150 Ω, and one single LED with R7, 330 Ω. Each string runs at about 17 mA. `K` marks every cathode on the silkscreen.

## Assembly notes

* D21 is a single-LED string: on v1 it was paired with D141, now on SIGNS. Its resistor R7 (v1 R76) stays where it was, but is **330 Ω, not 150 Ω**.
* EXT PWR is on this board because that is where it sits under the printed panel.
* v1 R57, which sat on this side of the seam, belongs to an ELEC string and has moved there.
* Every part has its value, polarity or pin 1 on the silkscreen of its own side. Each part's description in the schematic names its v1 reference.

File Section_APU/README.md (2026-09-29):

# APU section board (v2)

The v2 board under the APU panel. It carries the panel's switches, annunciator LEDs and backlight, at their v1 positions, and reaches the mainboard through one ribbon and one pair of backlight wires. There are no ICs on it. The design rules shared by the eight section boards are in [`docs/board-split.md`](../docs/board-split.md).

* **PCB:** 39 × 79.5 mm, 2 layers, 1.6 mm. Every v1 hole is kept.
* **Status:** routed with Freerouting. ERC, DRC and schematic parity are clean. Not yet ordered.

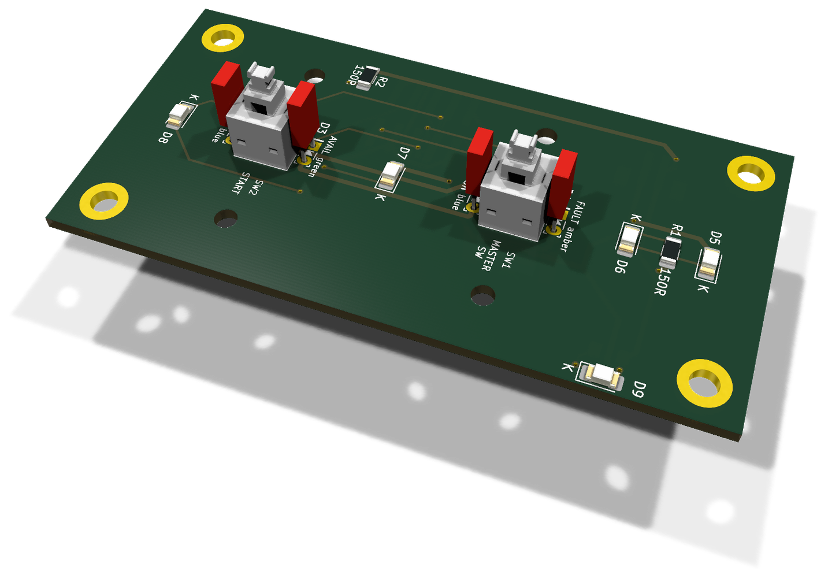
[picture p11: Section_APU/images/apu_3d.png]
APU board, 3D view


| Top: the panel side | Bottom: the connectors |
|---|---|
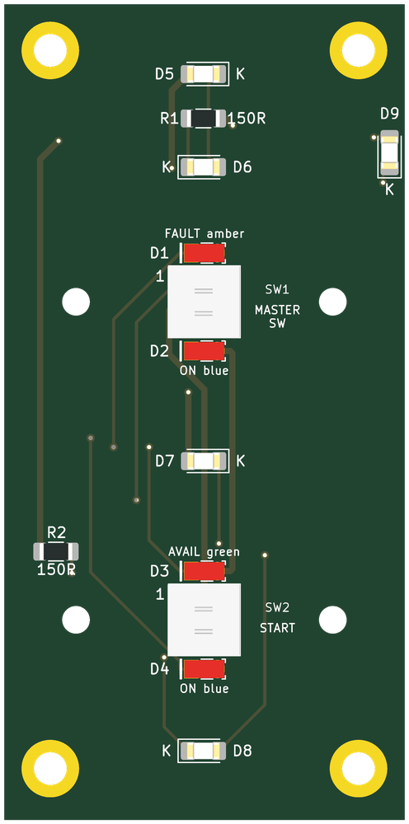
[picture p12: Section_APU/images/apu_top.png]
APU, top
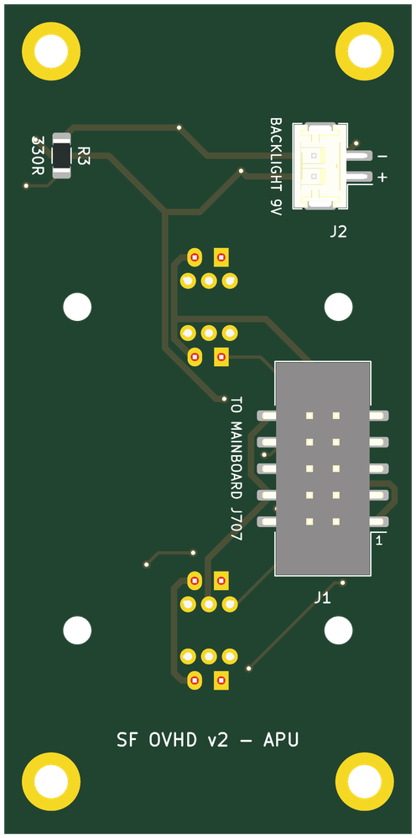
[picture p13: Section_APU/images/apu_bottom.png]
APU, bottom
|  |  |

Rendered by KiCad from the board file. The bottom is seen from below, so it is mirrored against the top.

## Connectors

Both are new on v2 and sit on the **back**, so nothing new stands proud of the front.

| Ref | What | Goes to |
|---|---|---|
| J1 | Shrouded IDC header, 10 pins, SMD | J707 on the mainboard, straight ribbon, pin 1 to pin 1 |
| J2 | JST PH, 2 pins, SMD. Pin 1 `+9V_BL` (`+`), pin 2 the switched return (`−`) | screw terminal J607 on the mainboard |

J1 and J2 are on the left edge, towards the mainboard.

The signal on every ribbon pin is in the design document: [APU — 10 pins](../docs/board-split.md#apu--10-pins).

## Switches

| Ref | Switch | Type | v1 ref |
|---|---|---|---|
| SW1 | APU MASTER SW | Korry | SW1 |
| SW2 | APU START | Korry | SW2 |

## Annunciators

Anodes on `+5V_LED` from the ribbon, cathodes back down the ribbon to their TLC5927 output. No resistors: the TLC5927 sets the current.

| Ref | Colour | Legend | Chain bit | Driver | v1 ref |
|---|---|---|---|---|---|
| D1 | amber | `APU_MASTER_FAULT` | `ANN_UPPER` 23 | U504 (v1 U5) | D178 |
| D2 | blue | `APU_MASTER_ON` | `ANN_LOWER` 17 | U502 (v1 U7) | D130 |
| D3 | green | `APU_AVAIL` | `ANN_UPPER` 24 | U504 (v1 U5) | D128 |
| D4 | blue | `APU_START_ON` | `ANN_LOWER` 24 | U502 (v1 U7) | D4 |

## Backlight

5 LEDs, 1206 (D5–D9), on 9 V: 2 strings of two with 150 Ω, and one single LED with R3, 330 Ω. Each string runs at about 17 mA. `K` marks every cathode on the silkscreen.

## Assembly notes

* D9 is a single-LED string: on v1 it was paired with D149, now on SIGNS. R3, 330 Ω on the back, gives it the same 17 mA as a pair on 150 Ω.
* Every part has its value, polarity or pin 1 on the silkscreen of its own side. Each part's description in the schematic names its v1 reference.

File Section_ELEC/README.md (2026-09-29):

# ELEC section board (v2)

The v2 board under the ELEC panel. It carries the panel's switches, annunciator LEDs and backlight, at their v1 positions, and reaches the mainboard through one ribbon and one pair of backlight wires. There are no ICs on it. The design rules shared by the eight section boards are in [`docs/board-split.md`](../docs/board-split.md).

* **PCB:** 177.5 × 39.5 mm, 2 layers, 1.6 mm. Every v1 hole is kept.
* **Status:** routed with Freerouting. ERC, DRC and schematic parity are clean. Not yet ordered.

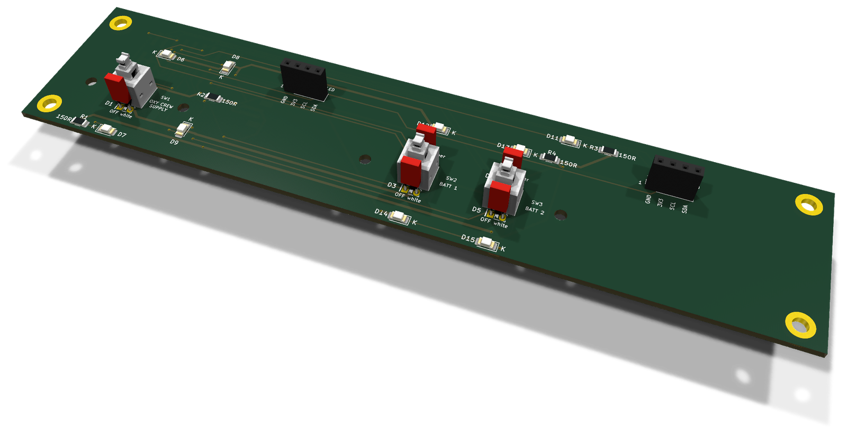
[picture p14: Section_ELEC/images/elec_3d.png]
ELEC board, 3D view


**Top**, the panel side:

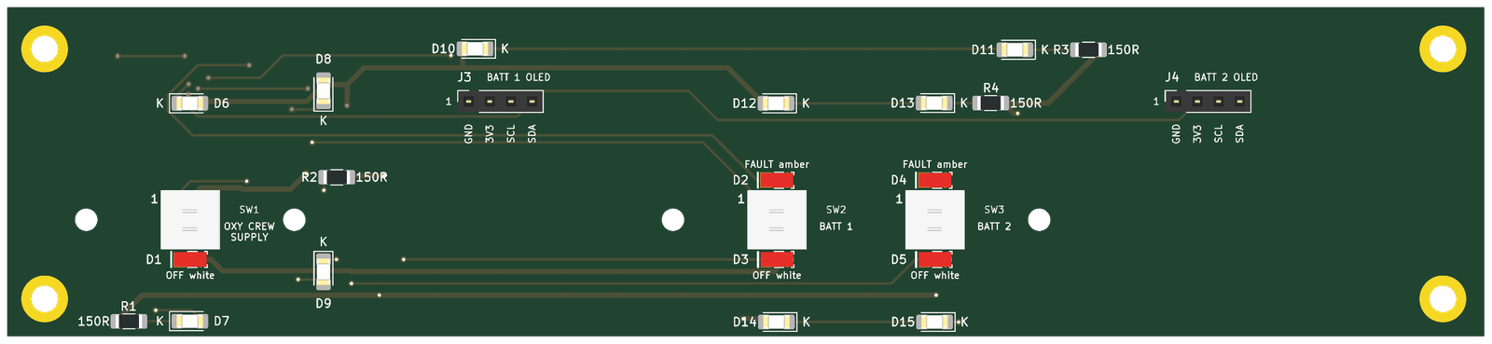
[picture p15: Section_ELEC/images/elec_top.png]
ELEC, top


**Bottom**, with the connectors:

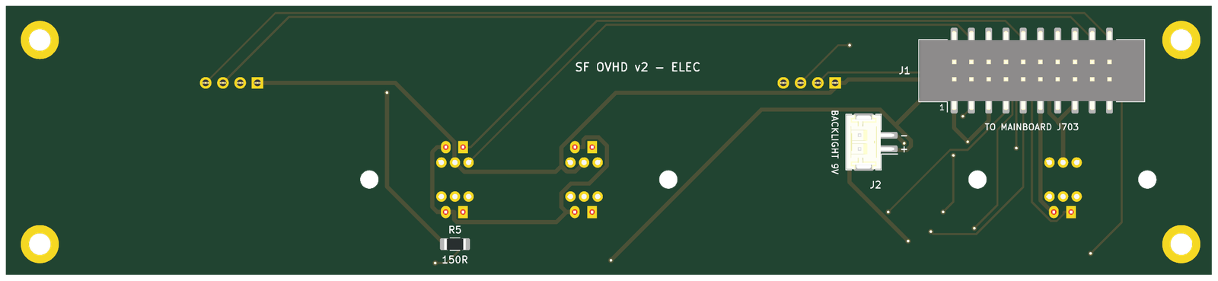
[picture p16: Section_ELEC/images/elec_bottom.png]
ELEC, bottom


Rendered by KiCad from the board file. The bottom is seen from below, so it is mirrored against the top.

## Connectors

Both are new on v2 and sit on the **back**, so nothing new stands proud of the front.

| Ref | What | Goes to |
|---|---|---|
| J1 | Shrouded IDC header, 20 pins, SMD | J703 on the mainboard, straight ribbon, pin 1 to pin 1 |
| J2 | JST PH, 2 pins, SMD. Pin 1 `+9V_BL` (`+`), pin 2 the switched return (`−`) | screw terminal J603 on the mainboard |

J1 and J2 are on the back, top edge, left end.

The signal on every ribbon pin is in the design document: [ELEC — 20 pins](../docs/board-split.md#elec--20-pins).

## Switches

| Ref | Switch | Type | v1 ref |
|---|---|---|---|
| SW1 | ELEC OXY CREW SUPPLY | Korry | SW14 |
| SW2 | ELEC BATT 1 | Korry | SW15 |
| SW3 | ELEC BATT 2 | Korry | SW16 |

## Annunciators

Anodes on `+5V_LED` from the ribbon, cathodes back down the ribbon to their TLC5927 output. No resistors: the TLC5927 sets the current.

| Ref | Colour | Legend | Chain bit | Driver | v1 ref |
|---|---|---|---|---|---|
| D1 | white | `OXY_CREW_SUPPLY_OFF` | `ANN_LOWER` 4 | U501 (v1 U6) | D103 |
| D2 | amber | `ELEC_BATT_1_FAULT` | `ANN_UPPER` 14 | U503 (v1 U8) | D1 |
| D3 | white | `ELEC_BATT_1_OFF` | `ANN_LOWER` 15 | U501 (v1 U6) | D106 |
| D4 | amber | `ELEC_BATT_2_FAULT` | `ANN_UPPER` 13 | U503 (v1 U8) | D3 |
| D5 | white | `ELEC_BATT_2_OFF` | `ANN_LOWER` 14 | U501 (v1 U6) | D107 |

## Backlight

10 LEDs, 1206 (D6–D15), on 9 V, in 5 strings of two with 150 Ω (R1–R5). Each string runs at about 17 mA. `K` marks every cathode on the silkscreen.

## Assembly notes

* J3 is the BATT 1 OLED socket (PCA9548A channel 0) and J4 the BATT 2 one (channel 1), where they were on v1: 1 GND, 2 +3V3, 3 SCL, 4 SDA.
* R5 is new, 150 Ω on the back. It replaces v1 R57, which sat across the seam on the AIR COND side.
* Every part has its value, polarity or pin 1 on the silkscreen of its own side. Each part's description in the schematic names its v1 reference.

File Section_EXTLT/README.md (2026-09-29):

# EXT LT section board (v2)

The v2 board under the EXT LT panel. It carries the panel's switches, annunciator LEDs and backlight, at their v1 positions, and reaches the mainboard through one ribbon and one pair of backlight wires. There are no ICs on it. The design rules shared by the eight section boards are in [`docs/board-split.md`](../docs/board-split.md).

* **PCB:** 159.5 × 79.5 mm, 2 layers, 1.6 mm. Every v1 hole is kept.
* **Status:** routed with Freerouting. ERC, DRC and schematic parity are clean. Not yet ordered.

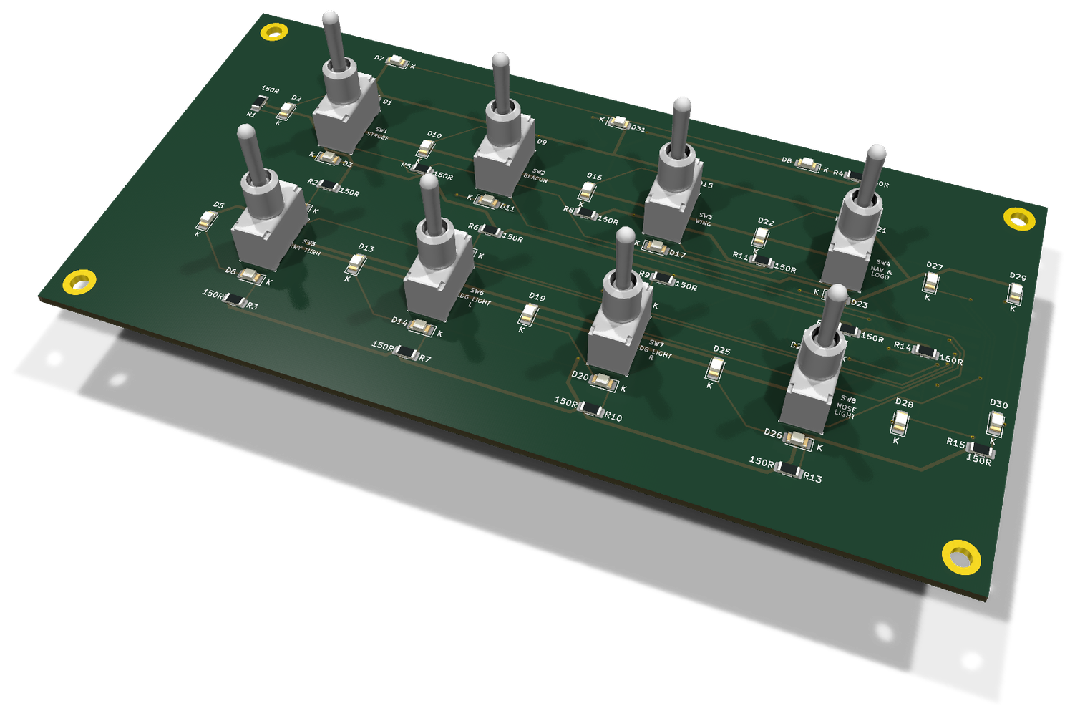
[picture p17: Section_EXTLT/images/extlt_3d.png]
EXT LT board, 3D view


**Top**, the panel side:

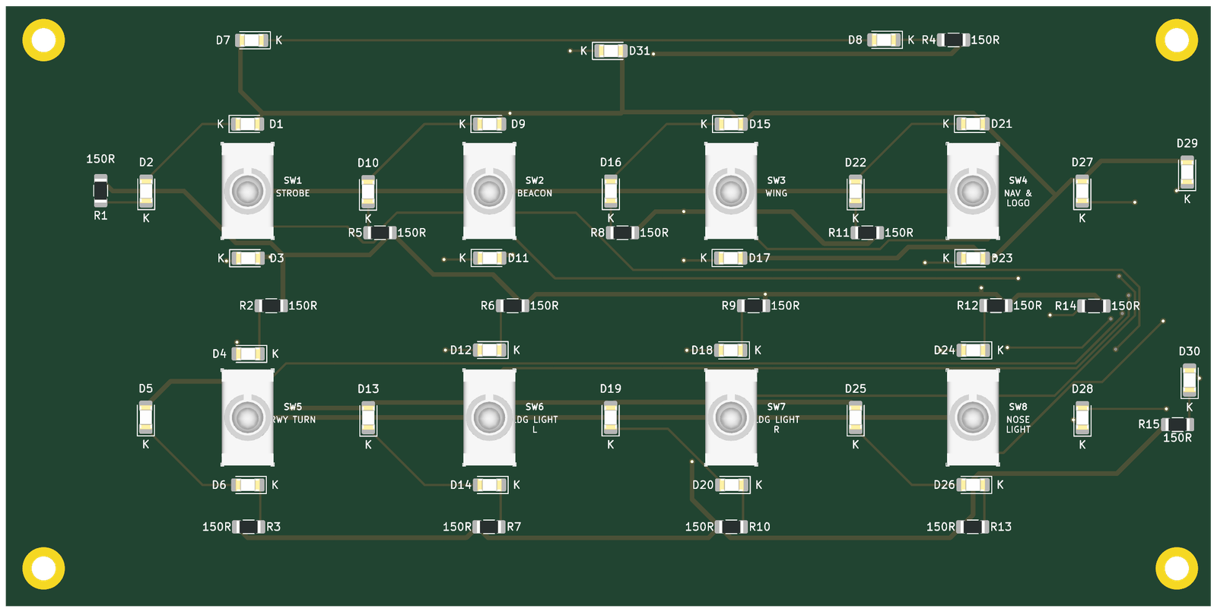
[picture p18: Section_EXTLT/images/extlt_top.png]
EXT LT, top


**Bottom**, with the connectors:

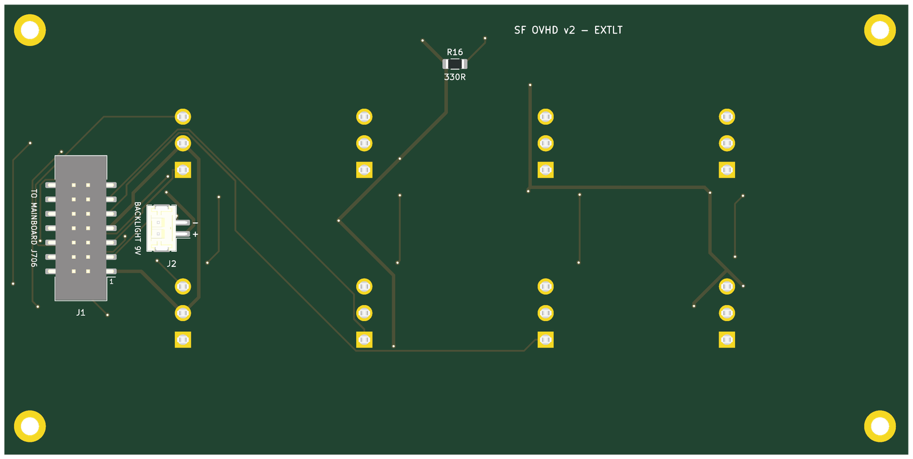
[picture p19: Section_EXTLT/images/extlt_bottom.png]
EXT LT, bottom


Rendered by KiCad from the board file. The bottom is seen from below, so it is mirrored against the top.

## Connectors

Both are new on v2 and sit on the **back**, so nothing new stands proud of the front.

| Ref | What | Goes to |
|---|---|---|
| J1 | Shrouded IDC header, 14 pins, SMD | J706 on the mainboard, straight ribbon, pin 1 to pin 1 |
| J2 | JST PH, 2 pins, SMD. Pin 1 `+9V_BL` (`+`), pin 2 the switched return (`−`) | screw terminal J606 on the mainboard |

J1 and J2 are at the right, over the mainboard, above its TLC5927 block.

The signal on every ribbon pin is in the design document: [EXT LT — 14 pins](../docs/board-split.md#ext-lt--14-pins).

## Switches

| Ref | Switch | Type | v1 ref |
|---|---|---|---|
| SW1 | EXTLT STROBE | toggle | S7 |
| SW2 | EXTLT BEACON | toggle | S6 |
| SW3 | EXTLT WING | toggle | S5 |
| SW4 | EXTLT NAV & LOGO | toggle | S4 |
| SW5 | EXTLT RWY TURN | toggle | S8 |
| SW6 | EXTLT LDG LIGHT L | toggle | S1 |
| SW7 | EXTLT LDG LIGHT R | toggle | S2 |
| SW8 | EXTLT NOSE LIGHT | toggle | S3 |

## Backlight

31 LEDs, 1206 (D1–D31), on 9 V: 15 strings of two with 150 Ω, and one single LED with R16, 330 Ω. Each string runs at about 17 mA. `K` marks every cathode on the silkscreen.

## Assembly notes

* No annunciators, so the ribbon carries no `+5V_LED`.
* Toggles: ON-OFF-ON for LDG LIGHT L, LDG LIGHT R, NOSE LIGHT and NAV & LOGO, read on both contacts (1 and 3); ON-OFF for STROBE, BEACON, WING and RWY TURN, read on contact 1. Lever up closes contact 1, the lower pin. They are generic three-terminal PCB-pin lever toggles from AliExpress, fitted by hand. The footprint is the v1 one, whose name still carries the E-Switch number 100SP1T1B4M2QE: that is not the part fitted, and the schematic gives the toggles no part number.
* D31 is a single-LED string: on v1 it was paired with D139, now on GPWS. R16, 330 Ω on the back, gives it the same 17 mA as a pair on 150 Ω.
* Every part has its value, polarity or pin 1 on the silkscreen of its own side. Each part's description in the schematic names its v1 reference.

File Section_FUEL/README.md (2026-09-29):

# FUEL section board (v2)

The v2 board under the FUEL panel. It carries the panel's switches, annunciator LEDs and backlight, at their v1 positions, and reaches the mainboard through one ribbon and one pair of backlight wires. There are no ICs on it. The design rules shared by the eight section boards are in [`docs/board-split.md`](../docs/board-split.md).

* **PCB:** 177.5 × 40 mm, 2 layers, 1.6 mm. Every v1 hole is kept.
* **Status:** routed with Freerouting. ERC, DRC and schematic parity are clean. Not yet ordered.

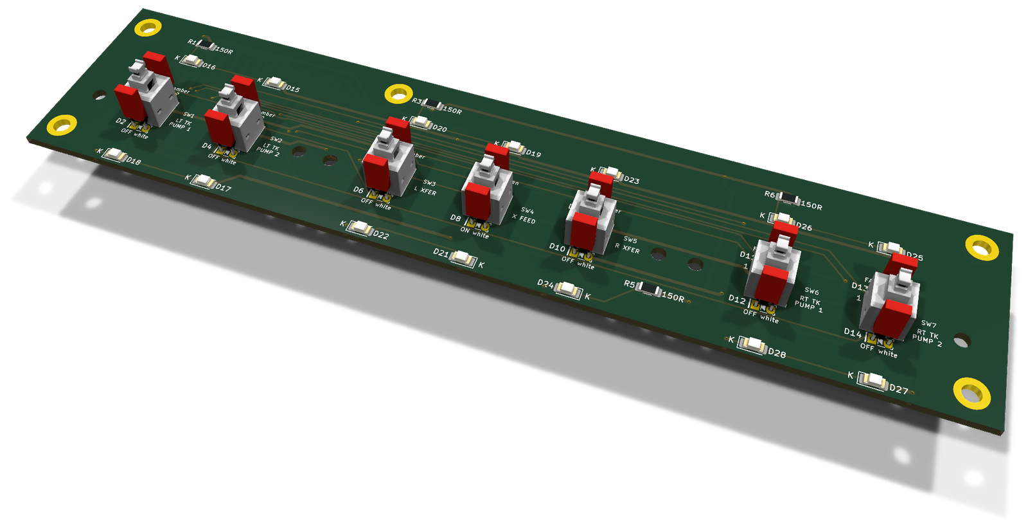
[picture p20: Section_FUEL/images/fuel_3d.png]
FUEL board, 3D view


**Top**, the panel side:

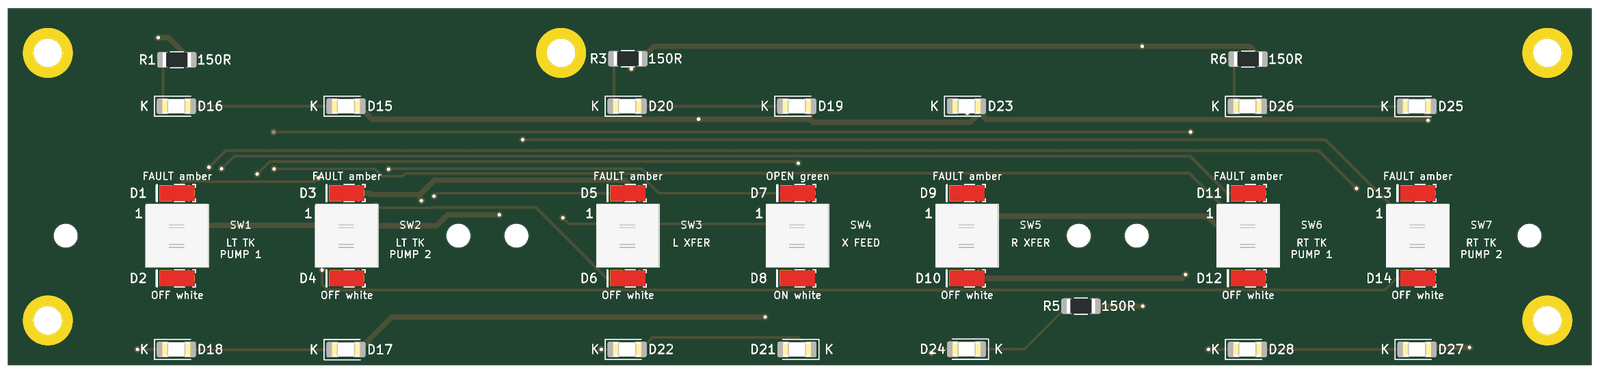
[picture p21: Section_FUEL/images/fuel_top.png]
FUEL, top


**Bottom**, with the connectors:

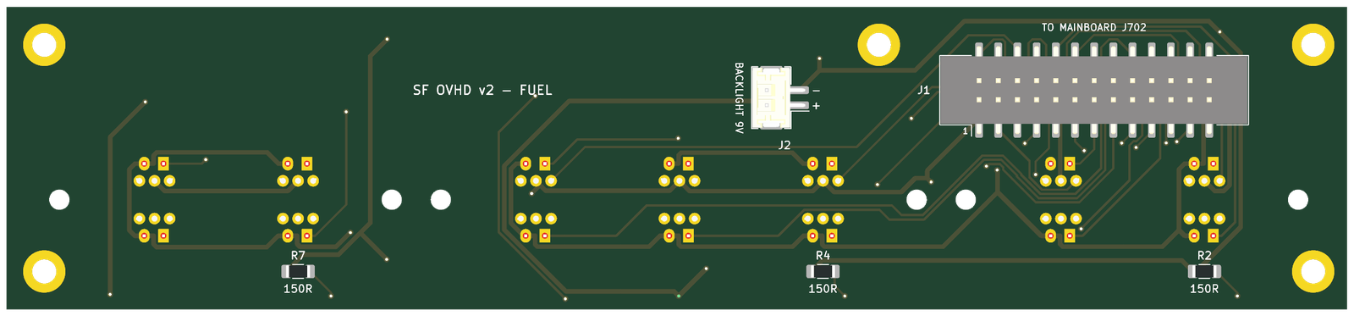
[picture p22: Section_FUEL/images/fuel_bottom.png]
FUEL, bottom


Rendered by KiCad from the board file. The bottom is seen from below, so it is mirrored against the top.

## Connectors

Both are new on v2 and sit on the **back**, so nothing new stands proud of the front.

| Ref | What | Goes to |
|---|---|---|
| J1 | Shrouded IDC header, 26 pins, SMD | J702 on the mainboard, straight ribbon, pin 1 to pin 1 |
| J2 | JST PH, 2 pins, SMD. Pin 1 `+9V_BL` (`+`), pin 2 the switched return (`−`) | screw terminal J602 on the mainboard |

J1 and J2 are on the back along the top edge, left of the middle M3 hole.

The signal on every ribbon pin is in the design document: [FUEL — 26 pins](../docs/board-split.md#fuel--26-pins).

## Switches

| Ref | Switch | Type | v1 ref |
|---|---|---|---|
| SW1 | FUEL LT TK PUMP 1 | Korry | SW17 |
| SW2 | FUEL LT TK PUMP 2 | Korry | SW18 |
| SW3 | FUEL L XFER | Korry | SW19 |
| SW4 | FUEL X FEED | Korry | SW20 |
| SW5 | FUEL R XFER | Korry | SW21 |
| SW6 | FUEL RT TK PUMP 1 | Korry | SW22 |
| SW7 | FUEL RT TK PUMP 2 | Korry | SW23 |

## Annunciators

Anodes on `+5V_LED` from the ribbon, cathodes back down the ribbon to their TLC5927 output. No resistors: the TLC5927 sets the current.

| Ref | Colour | Legend | Chain bit | Driver | v1 ref |
|---|---|---|---|---|---|
| D1 | amber | `LT_TK_PUMP_1_FAULT` | `ANN_UPPER` 12 | U503 (v1 U8) | D50 |
| D2 | white | `LT_TK_PUMP_1_OFF` | `ANN_LOWER` 5 | U501 (v1 U6) | D120 |
| D3 | amber | `LT_TK_PUMP_2_FAULT` | `ANN_UPPER` 11 | U503 (v1 U8) | D51 |
| D4 | white | `LT_TK_PUMP_2_OFF` | `ANN_LOWER` 6 | U501 (v1 U6) | D121 |
| D5 | amber | `L_XFER_FAULT` | `ANN_UPPER` 10 | U503 (v1 U8) | D52 |
| D6 | white | `L_XFER_OFF` | `ANN_LOWER` 7 | U501 (v1 U6) | D122 |
| D7 | green | `XFEED_OPEN` | `ANN_UPPER` 18 | U504 (v1 U5) | D2 |
| D8 | white | `XFEED_ON` | `ANN_LOWER` 13 | U501 (v1 U6) | D123 |
| D9 | amber | `R_XFER_FAULT` | `ANN_UPPER` 9 | U503 (v1 U8) | D75 |
| D10 | white | `R_XFER_OFF` | `ANN_LOWER` 11 | U501 (v1 U6) | D124 |
| D11 | amber | `RT_TK_PUMP_1_FAULT` | `ANN_UPPER` 8 | U503 (v1 U8) | D77 |
| D12 | white | `RT_TK_PUMP_1_OFF` | `ANN_LOWER` 10 | U501 (v1 U6) | D125 |
| D13 | amber | `RT_TK_PUMP_2_FAULT` | `ANN_UPPER` 16 | U504 (v1 U5) | D108 |
| D14 | white | `RT_TK_PUMP_2_OFF` | `ANN_LOWER` 9 | U501 (v1 U6) | D127 |

## Backlight

14 LEDs, 1206 (D15–D28), on 9 V, in 7 strings of two with 150 Ω (R1–R7). Each string runs at about 17 mA. `K` marks every cathode on the silkscreen.

## Assembly notes

* R2, R4 and R7 are new, 150 Ω on the back, beside their LEDs. On v1 the resistors of those three strings (R66, R64, R61) sat across the seam, on the ELEC side.
* The ribbon has two `+5V_LED` pins: 14 annunciators at ~19 mA are about 270 mA in a light test.
* SW3 and SW5 are labelled `L XFER` and `R XFER` on the board. They are CTR TK PUMP 1 and 2 in the `.mfmc` and in the MobiFlight project.
* The seam with ELEC is inset 1 mm instead of 1.5, because D102 and D104 of v1 sit 2 mm from it.
* Every part has its value, polarity or pin 1 on the silkscreen of its own side. Each part's description in the schematic names its v1 reference.

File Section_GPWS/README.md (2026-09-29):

# GPWS section board (v2)

The v2 board under the GPWS panel. It carries the panel's switches, annunciator LEDs and backlight, at their v1 positions, and reaches the mainboard through one ribbon and one pair of backlight wires. There are no ICs on it. The design rules shared by the eight section boards are in [`docs/board-split.md`](../docs/board-split.md).

* **PCB:** 159.5 × 39 mm, 2 layers, 1.6 mm. Every v1 hole is kept.
* **Status:** routed with Freerouting. ERC, DRC and schematic parity are clean. Not yet ordered.

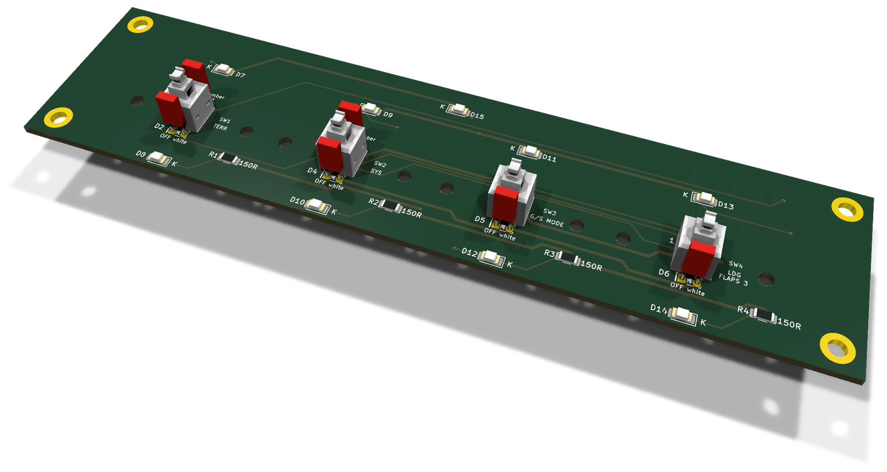
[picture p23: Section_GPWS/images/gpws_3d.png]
GPWS board, 3D view


**Top**, the panel side:

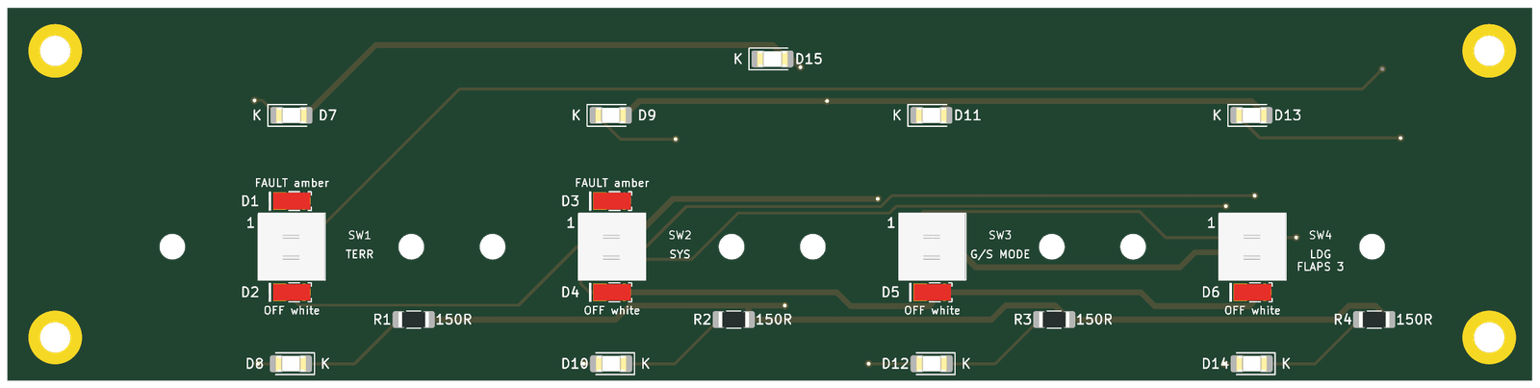
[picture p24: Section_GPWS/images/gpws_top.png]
GPWS, top


**Bottom**, with the connectors:

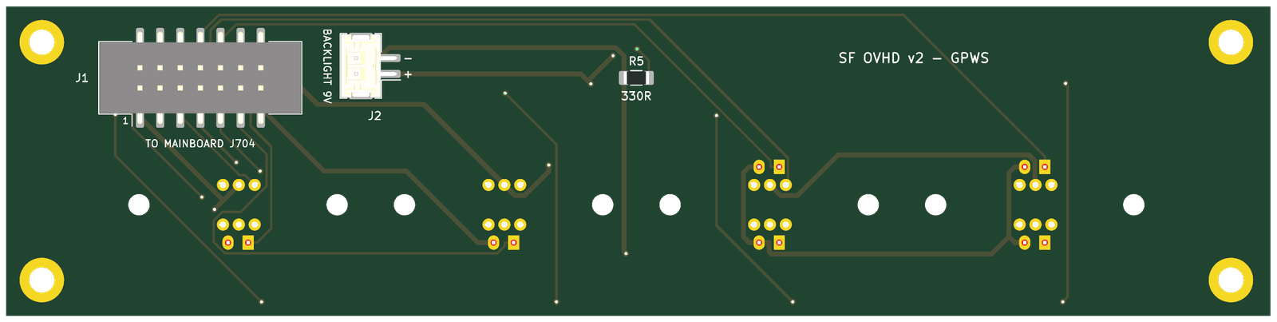
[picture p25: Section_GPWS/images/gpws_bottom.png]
GPWS, bottom


Rendered by KiCad from the board file. The bottom is seen from below, so it is mirrored against the top.

## Connectors

Both are new on v2 and sit on the **back**, so nothing new stands proud of the front.

| Ref | What | Goes to |
|---|---|---|
| J1 | Shrouded IDC header, 14 pins, SMD | J704 on the mainboard, straight ribbon, pin 1 to pin 1 |
| J2 | JST PH, 2 pins, SMD. Pin 1 `+9V_BL` (`+`), pin 2 the switched return (`−`) | screw terminal J604 on the mainboard |

J1 and J2 are along the top edge on the right. The bottom band, nearer the mainboard, is taken by the Korry pins, the annunciator LEDs and the frame holes, and a 2x7 shroud does not fit there.

The signal on every ribbon pin is in the design document: [GPWS — 14 pins](../docs/board-split.md#gpws--14-pins).

## Switches

| Ref | Switch | Type | v1 ref |
|---|---|---|---|
| SW1 | GPWS TERR | Korry | SW6 |
| SW2 | GPWS SYS | Korry | SW7 |
| SW3 | GPWS G/S MODE | Korry | SW8 |
| SW4 | GPWS LDG FLAPS 3 | Korry | SW9 |

## Annunciators

Anodes on `+5V_LED` from the ribbon, cathodes back down the ribbon to their TLC5927 output. No resistors: the TLC5927 sets the current.

| Ref | Colour | Legend | Chain bit | Driver | v1 ref |
|---|---|---|---|---|---|
| D1 | amber | `GPWS_TERR_FAULT` | `ANN_UPPER` 4 | U503 (v1 U8) | D188 |
| D2 | white | `GPWS_TERR_OFF` | `ANN_LOWER` 0 | U501 (v1 U6) | D76 |
| D3 | amber | `GPWS_SYS_FAULT` | `ANN_UPPER` 5 | U503 (v1 U8) | D190 |
| D4 | white | `GPWS_SYS_OFF` | `ANN_LOWER` 1 | U501 (v1 U6) | D78 |
| D5 | white | `GS_OFF` | `ANN_LOWER` 2 | U501 (v1 U6) | D79 |
| D6 | white | `FLAPS3_OFF` | `ANN_LOWER` 3 | U501 (v1 U6) | D80 |

## Backlight

9 LEDs, 1206 (D7–D15), on 9 V: 4 strings of two with 150 Ω, and one single LED with R5, 330 Ω. Each string runs at about 17 mA. `K` marks every cathode on the silkscreen.

## Assembly notes

* D15 is a single-LED string: on v1 it was paired with D140, now on EXT LT. R5, 330 Ω on the back, gives it the same 17 mA as a pair on 150 Ω.
* Every part has its value, polarity or pin 1 on the silkscreen of its own side. Each part's description in the schematic names its v1 reference.

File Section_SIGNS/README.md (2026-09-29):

# SIGNS section board (v2)

The v2 board under the SIGNS and ANTI ICE (`OVHD_PANEL_SIGNS`) panel. It carries the panel's switches, annunciator LEDs and backlight, at their v1 positions, and reaches the mainboard through one ribbon and one pair of backlight wires. There are no ICs on it. The design rules shared by the eight section boards are in [`docs/board-split.md`](../docs/board-split.md).

* **PCB:** 108.5 × 79.5 mm, 2 layers, 1.6 mm. Every v1 hole is kept.
* **Status:** routed with Freerouting. ERC, DRC and schematic parity are clean. Not yet ordered.

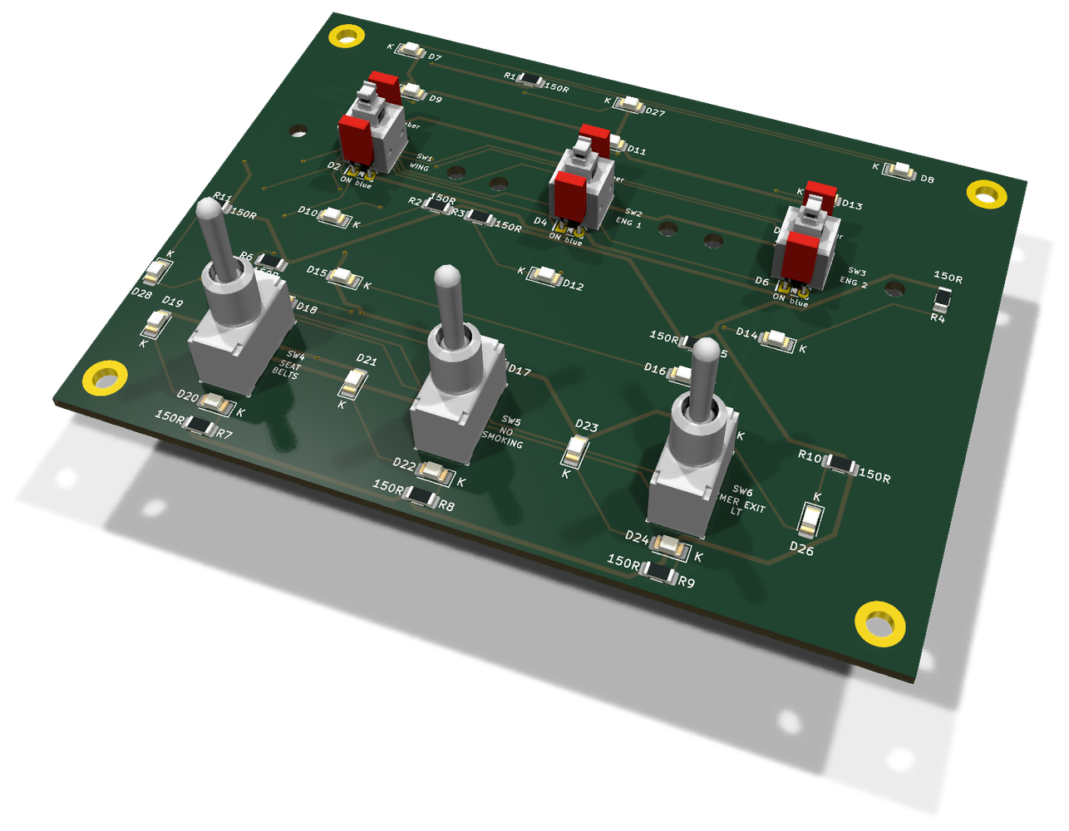
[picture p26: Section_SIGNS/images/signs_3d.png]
SIGNS board, 3D view


**Top**, the panel side:

SIGNS, top

**Bottom**, with the connectors:

SIGNS, bottom

Rendered by KiCad from the board file. The bottom is seen from below, so it is mirrored against the top.

## Connectors

Both are new on v2 and sit on the **back**, so nothing new stands proud of the front.

| Ref | What | Goes to |
|---|---|---|
| J1 | Shrouded IDC header, 16 pins, SMD | J708 on the mainboard, straight ribbon, pin 1 to pin 1 |
| J2 | JST PH, 2 pins, SMD. Pin 1 `+9V_BL` (`+`), pin 2 the switched return (`−`) | screw terminal J608 on the mainboard |

J1 and J2 are on the back along the left edge, towards the mainboard.

The signal on every ribbon pin is in the design document: [SIGNS — 16 pins](../docs/board-split.md#signs--16-pins).

## Switches

| Ref | Switch | Type | v1 ref |
|---|---|---|---|
| SW1 | SIGNS WING | Korry | SW3 |
| SW2 | SIGNS ENG 1 | Korry | SW4 |
| SW3 | SIGNS ENG 2 | Korry | SW5 |
| SW4 | SIGNS SEAT BELTS | toggle | S9 |
| SW5 | SIGNS NO SMOKING | toggle | S10 |
| SW6 | SIGNS EMER EXIT LT | toggle | S11 |

## Annunciators

Anodes on `+5V_LED` from the ribbon, cathodes back down the ribbon to their TLC5927 output. No resistors: the TLC5927 sets the current.

| Ref | Colour | Legend | Chain bit | Driver | v1 ref |
|---|---|---|---|---|---|
| D1 | amber | `ANTI_ICE_WING_FAULT` | `ANN_UPPER` 21 | U504 (v1 U5) | D184 |
| D2 | blue | `ANTI_ICE_WING_ON` | `ANN_LOWER` 18 | U502 (v1 U7) | D131 |
| D3 | amber | `ANTI_ICE_ENG1_FAULT` | `ANN_UPPER` 20 | U504 (v1 U5) | D183 |
| D4 | blue | `ANTI_ICE_ENG1_ON` | `ANN_LOWER` 19 | U502 (v1 U7) | D132 |
| D5 | amber | `ANTI_ICE_ENG2_FAULT` | `ANN_UPPER` 22 | U504 (v1 U5) | D185 |
| D6 | blue | `ANTI_ICE_ENG2_ON` | `ANN_LOWER` 20 | U502 (v1 U7) | D133 |

## Backlight

22 LEDs, 1206 (D7–D28), on 9 V, in 11 strings of two with 150 Ω (R1–R11). Each string runs at about 17 mA. `K` marks every cathode on the silkscreen.

## Assembly notes

* **NO SMOKING (SW5) is read on contact 1 on v2.** On v1 it was read on contact 3 and the MobiFlight row was inverted to make up for it: **remove that inversion** when moving to v2.
* Toggles: ON-OFF for SEAT BELTS and NO SMOKING, read on contact 1; ON-OFF-ON for EMER EXIT LT, read on both contacts. Lever up closes contact 1, the lower pin. They are generic three-terminal PCB-pin lever toggles from AliExpress, fitted by hand. The footprint is the v1 one, whose name still carries the E-Switch number 100SP1T1B4M2QE: that is not the part fitted, and the schematic gives the toggles no part number.
* String 11 is a new pair: D27 and D28 (v1 D141 and D149) on R11 (v1 R79). On v1 each was paired with an LED on another board.
* Every part has its value, polarity or pin 1 on the silkscreen of its own side. Each part's description in the schematic names its v1 reference.

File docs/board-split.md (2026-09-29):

# Splitting the mainboard — architecture

Status: **drawn and routed** (September 2026). The mainboard and the eight
section boards are in their own KiCad projects, each with ERC, DRC and
schematic parity clean. Nothing has been ordered yet. The firmware side is
in `SF_OVHD` 1.2.0. `Kicad Files/` is v1, unchanged.

## Why

The overhead runs on one four-layer board, 313 × 206 mm. It works, but it
costs well over €100 at JLCPCB once shipping and customs are added, and any
mistake means reordering the whole thing.

The panel is already divided into eight printed sections, each screwed down
on its own. The board does not need to be one piece: it can follow the
panels.

## The decisions

| Topic | Decision |
|---|---|
| Split | One mainboard plus **eight section boards, one per printed panel** |
| Printed parts | **Unchanged.** Panels, frames and Korry cases are not reprinted; only the case changes, to take the mainboard |
| Section boards | Cut out of the current layout: outline, **every hole**, every switch and LED at the same coordinates |
| Thickness | 1.6 mm, JLCPCB's standard, as today. The board is the spacer between panel and case |
| Layers | 2 on every board |
| Data | One shrouded, keyed IDC header per section board, ribbon straight through, pin 1 to pin 1. SMD header on the section boards |
| Backlight | A 2-pin JST PH (SMD) per section board, AWG wire to a 2-pole screw terminal on the mainboard, dimmed there |
| Connectors | On the **back** of the section boards only. Nothing new may stand proud of the front |
| Mainboard | On the floor of the lower-left case part, towards the centre of the case |
| USB | A ready-made panel-mount USB-B extension at the case wall; USB-B stays on the mainboard |
| Power in | Panel-mount 5.5 × 2.1 jack at the case wall, two AWG wires to a screw terminal |
| Pin map | **Every switch on the same ATmega pin, every annunciator on the same bit of the same chain.** Firmware, `.mfmc` and MobiFlight project stay valid |

## Mechanics

Today each printed panel is screwed through the big board into brass inserts
in the case. After the split, each panel clamps its own section board with
the same screws in the same inserts.

* **Holes:** every hole of today's board is kept on the section board it
  falls in, at the same position, whether or not its purpose is known.
* **Seams:** the v1 board has them drawn on `User.Drawings`: x = 154 and
  x = 181 / 223 mm, y = 60, 102 and 144 mm. Each section board's inner
  edges are those lines moved 1.5 mm inwards.
* **Outline:** each section board keeps today's outer edge where it has
  one, since the current board already fits the case there. The new inner
  edges are cut along the seams between panels, on the current layout.
  Today's board is continuous there, so nothing passes through the PCB
  plane at a seam. The cut only has to stay clear of parts, tracks and
  holes.
* **Case:** it is open inside, built for one board, and its parts are joined
  at floor level, so ribbons and wires pass under the section boards with
  nothing in the way. The only change is brass inserts on the floor of the
  lower-left part, for the mainboard.
* **Connector placement:** on each section board, the IDC header and the
  terminal go on the edge nearest the mainboard.

### Printed panels and section boards

Panel sizes are from the STL files. Contents are from the current board.

| Board | Panel | Switches | Annunciators | Backlight LEDs | Displays |
|---|---|---|---|---|---|
| ADIRS | 133 × 82 | 3 × ADR rotary, GND CTL | 1 | 18 | ADIRS OLED |
| FUEL | 178 × 40 | 7 Korry | 14 | 14 | — |
| ELEC | 178 × 40 | BATT 1, BATT 2, CREW SUPPLY | 5 | 10 | BATT 1 and BATT 2 OLED |
| GPWS | 160 × 40 | 4 Korry | 6 | 9 | — |
| AIR COND | 151 × 40 | APU BLEED, PACK 1, PACK 2, EXT PWR | 8 | 13 | — |
| EXT LT | 160 × 80 | 8 toggles | — | 31 | — |
| APU | 40 × 80 | MASTER, START | 4 | 5 | — |
| SIGNS | 109 × 80 | 3 ANTI ICE Korry, 3 toggles | 6 | 22 | — |
| **Total** | | **49 inputs** | **44** | **122** | 3 |

EXT PWR stays on AIR COND and GND CTL stays on ADIRS, because that is where
they are under the printed panels. ANTI ICE and SIGNS are one printed panel,
`OVHD_PANEL_SIGNS`. `ANTI-ICE-FRAME` is only the frame over it.

### Estimated ribbon lengths

With the mainboard in the lower-left part and each header on the nearest
edge, including the ~25 mm drop to the floor and some slack:

| Board | Ribbon |
|---|---|
| EXT LT | ~10 cm |
| GPWS, APU, AIR COND | ~10 cm |
| SIGNS, ADIRS, ELEC | ~12 cm |
| FUEL | ~15 cm |

None of these signals is fast: button levels, DC sinks switched only when an
annunciator changes, and I2C at 400 kHz. A ribbon adds roughly 50 pF/m per
conductor against the 400 pF I2C allows, so anything up to 40 cm is fine.

## The mainboard

**137 × 89 mm**, 2 layers, on the floor of the lower-left case part, between
the four pillars that carry the section boards. Measured on
`OVHD_PANEL_LOWER_LEFT_CASE_BLACK.stl`, the floor there is free over
141 × 93.5 mm. That leaves 2 mm all round and no change to the pillars. Four
M3 holes, 4 mm from the corners, for bosses with heat-set inserts in the
reprinted floor. With today's case there are 27 mm from the floor to the
underside of the section boards; the reprint will raise that to 30–35 mm.

### What moves onto it

Everything on today's board that belongs to no panel:

* ATmega2560 (today under GPWS)
* CH340G with its 12 MHz crystal, the 16 MHz crystal, USB-B
* J4, the ISP header, and **JP1, unchanged**. Its middle pin is the MCU
  rail. 1–2 joins it to the board's +5V; 2–3 joins it to J4's VCC, so an
  ISP programmer powers the MCU alone while the bootloader is burned.
* MIC29302, AMS1117
* PCA9548A with the three-way address DIP switch (today under ADIRS)
* The four TLC5927 (today spread over several panels; the v1 schematic calls them DM13A)

### Power

```
 panel jack 9 V ──► screw terminal ──► reverse protection ──┬──► fuse ──► backlight +9V ──► 8 section terminals
                                                             │                 (return via Q1, see Dimming)
                                                             └──► fuse ──► MIC29302 ──► +5V_EXT ──┬──► +5V_LED (annunciator anodes)
                                                                                                 │
 USB VBUS (via extension) ─────────────────────────────────────────────────────► TPS2115A ◄───────┘
                                                                                     │
                                                                               +5V (logic) ──► JP1 ──► MCU rail
                                                                                     │
                                                                                     └──► AMS1117 ──► +3V3 (PCA9548A, OLEDs)
```

* **TPS2115A** picks the external 5 V whenever the 9 V is present and falls
  back to USB VBUS otherwise, with no path back into the USB port. The
  circuit is copied from the FCU mainboard (`U8`: D0 to ground, D1 from a
  100k/100k divider on the external rail, `ILIM` set to about 0.8 A). It
  replaces D162, today's series diode on VBUS.
* **The annunciator anodes do not go through the TPS2115A.** In a light
  test all 44 LEDs are lit, about 0.85 A at 19 mA each. Added to the logic,
  that is past the 0.8 A limit and a USB port's 500 mA. The
  anodes therefore take their own rail, `+5V_LED`, straight from the
  MIC29302. On USB alone the annunciators stay dark, like the backlight,
  and the logic keeps working.
* **Two fuses, one per branch**, as on the FCU PSU: the backlight branch
  (~1.1 A at 17 mA per string) and the regulator branch (~1 A in a light test). A
  fault on one does not take down the other.
* The MIC29302 dissipates well under 1 W in normal use, with a handful of
  annunciators lit. In a light test it is ~3 W, about 3.2 V across it at
  ~1 A. The light test lasts seconds, but the copper under the tab must be
  sized for it, or the anode rail given its own regulator.

### Hot-plug lock-up

Found on the current board, September 2026, first with 680 Ω on every
`R-EXT` and the original, faulty U8 fitted. **Re-checked with 1 kΩ and a new
U8: the result is the same.** Pushing the barrel into a live adapter still
leaves the annunciators dead. With the barrel already in and the adapter
plugged into the mains, everything works, including after the case was
closed and the panel fully reassembled. It is a power-up problem, not a
faulty chip.

| How the 9 V arrives | Annunciators |
|---|---|
| Barrel already in the board, adapter then plugged into the mains | work, every time |
| Barrel pushed into an adapter that is already live | dead, about 19 times in 20 |
| Bench supply | work |

Two different 9 V / 3 A adapters behave the same way. The OLEDs, the
switches and the backlight work in every case. Only the TLC5927 outputs stay
off, while data still passes through the chips.

Pushing the barrel into a live supply brings the 9 V in all at once, with
the jack's contacts bouncing and the input capacitors being charged in one
step. The ATmega has a reset and the firmware re-initialises the OLEDs.
The TLC5927 has no reset pin, so a bad start is kept until its supply goes
away. Why it did not show with the old 56 Ω `R-EXT` is not known. No
oscilloscope capture has been taken.

**On the current board:** leave the barrel plugged in and switch the
adapter at the mains.

**On the new mainboard:**

* **A robust 9 V input:** a bulk electrolytic across the input to damp
  the hot-plug ringing, and a TVS for the spikes. The panel jack, the wires
  and the screw terminal make the input path longer than today's, so the
  problem would get worse, not go away.
* **A firmware-controlled power-up of the TLC5927 — required.** The four
  chips' VDD goes through a P-MOSFET high-side switch, the same topology as
  the anode switch: gate pulled up to +5V (off by default) and pulled down
  by an N-MOSFET (BS170) from **D46**.
  * The chips stay unpowered until the firmware turns them on. The ATmega
    starts, the supply has settled, and only then do the TLC5927s get
    power. They start clean whatever the 9 V did on the way in.
  * `SF_OVHD` does it in `attach()`: drive D46 low, wait a few tens of
    milliseconds, drive it high. The same sequence can be exposed as a
    message, so the Connector can reset the chain without a power cycle.
  * **Watch for back-powering.** While the chips are unpowered, CLK, LE
    and SDI must not sit high. A CMOS input driven high with VDD at 0 V
    feeds the chip through its protection diodes, half-powers it and
    defeats the reset. MobiFlight's output shifter leaves LE high after
    every update, so the firmware pulls CLK, LE and SDI low before it cuts
    VDD. A 1 kΩ series resistor on each of the three lines, at the chips'
    end, limits the injected current if that ever fails. It also damps the
    long clock and latch traces.
  * This firmware is the only one that can bring the annunciators up. A
    board flashed with stock MobiFlight firmware would leave them dark,
    which is acceptable for this panel.

### I2C

* **Upstream pull-ups on +5V.** Today R7 and R8 pull SDA and SCL to 3.3 V,
  below the 3.5 V an ATmega at 5 V needs to read a high. It works, but out of
  spec. The PCA9548A is meant for exactly this translation: upstream
  pull-ups to 5 V, downstream to 3.3 V, the chip itself on 3.3 V. Check the
  values against the datasheet's application section when drawing.
* Downstream pull-ups, 4.7k to +3V3 per channel, stay on the mainboard.
* Channels 0, 1 and 2 as today (BATT 1, BATT 2, ADIRS). Channels 3–7 stay
  free.

### Annunciators: fixed current, dimmable

**The four drivers are TI TLC5927, not DM13A.** They were bought from
Digi-Key, and the TLC5927 has the DM13A's pinout, so the KiCad symbol and
the schematic say DM13A. Everything below comes from the TLC5927 datasheet
(SLVS677C) and from measurements on the board.

* **Output current**, with the configuration the chip powers up in:
  I_OUT = 1.25 V / R_ext × 15. That is about 26 mA at 720 Ω and 52 mA at
  360 Ω. The output range is 10–120 mA, and 120 mA is the absolute maximum.
* **The trimmers go. Each TLC5927 gets a fixed 1 kΩ 1206 on `R-EXT`**, all
  four the same, for ~19 mA per LED (1.25 V / 1 kΩ × 15). The Korry LEDs
  are plain rectangular LEDs, and the rule is to keep them at or below
  25 mA. 1 kΩ is the value fitted on the current board, and all four chips
  pass repeated full MobiFlight test cycles with it. 680 Ω (~28 mA) looked
  as good but sits above that limit.
* **Never below ~160 Ω, never above ~1.9 kΩ.** At power-up the chip runs
  with CM = 1, which is specified for 10–120 mA. That puts `R-EXT` between
  ~160 Ω (120 mA, the absolute maximum) and ~1.9 kΩ (10 mA). The 2–4.7 kΩ
  values tried along the way were below the chip's range, and that is why
  they were dim.
* **Measured against the formula.** The LED current was read as the step in
  the 9 V supply current when one LED is switched on:

  | `R-EXT` at pin 23 | TLC5927 formula | Measured | Light |
  |---|---|---|---|
  | 56–156 Ω (the original resistor and trimmer) | 120–335 mA asked, **held at 120 mA** | ~70–85 mA | far too bright |
  | 300 Ω | 63 mA | 39 mA | too bright |
  | 680 Ω | 28 mA | 17–18 mA | right, on every colour |
  | **1 kΩ** | **19 mA** | — | **fitted, all four chips** |
  | 2.1 kΩ | 9 mA | ~7 mA | dim |
  | 3.6 kΩ | 5 mA | a few mA | very dim |
  | 4.7 kΩ | 4.0 mA | ~4 mA | dim |

  Where the currents are low, measurement and formula agree. Where they are
  higher, the measurement reads low. The likely reason is that USB feeds
  part of the +5V through D162, so the bench supply does not see all of
  it. That has not been checked at these currents.
* **Why the trimmer never worked:** over its whole travel, 56–156 Ω asks
  for more than 120 mA. The chip sits at its own limit, so turning the
  trimmer changes nothing, and the LEDs ran far above their rating.
* **No capacitor on `R-EXT`, and no pads for one.** The v1 board has
  100 nF from each `R-EXT` pin to GND (C17, C19, C21, C23). The datasheet's
  application circuit (Figure 17) has only the resistor there. With 1 kΩ
  on `R-EXT`, the capacitor made the chip fail as soon as a second or third
  output of the same chip turned on:
  * the outputs dropped from ~15 mA to under 1 mA, too little for the bench
    supply to show, and stayed there until a power cycle;
  * VDD (5.0 V), `R-EXT` (1.2 V) and `OE` (0 V) read the same before and
    after, and the chip was cold;
  * it happened with firmware 1.1.0 (core 3.1.4) and with 1.0.5 (core
    2.5.1), with the Connector's binary and its old string commands alike.

  Found on 29 September 2026. With C17 removed, U6 kept all 16 outputs on at
  full brightness. In the same test U7, which still had C21, dimmed. With
  the old 56 Ω the capacitor did no harm. The v2 mainboard has no capacitor
  and no pads for one on `R-EXT`.
* **`OE` stays tied to GND, hard.** On the TLC5927, `OE` is also the mode
  pin. A one-clock-wide pulse on it, sampled by `CLK`, switches the chip
  into Special mode. There `LE` writes the configuration latch instead of
  the outputs. So **no PWM on `OE`**: MobiFlight's PWM is not synchronised
  with the shift-register clock, and could produce exactly that pulse. The
  dimming inverter on `~EN` that this plan used to have is dropped.
* **Dimming on the anode rail instead.** A P-MOSFET high-side switch on
  `+5V_LED`, its gate pulled up to `+5V_LED` (off by default) and pulled
  down by an N-MOSFET (BS170) from **D45**, a PWM pin free today.
  * D45 high → both MOSFETs on → anodes powered → annunciators lit.
  * D45 low or not driven → anodes off → annunciators dark. So 255 means
    bright in the Connector, and at power-up, reset or with the Connector
    closed they stay dark.
  * Brightness = the `R-EXT` current × the PWM duty. The chips never see
    their `OE` move.
  * The P-MOSFET must carry the light test: 44 × 19 mA ≈ 0.85 A.
* **A failed driver: U8.** With 1 kΩ on all four chips, U6, U7 and U5
  worked, and U8, the first chip of `ANN_UPPER`, did not:
  * every LED on it lit once and then the chip stopped updating its
    outputs until a power cycle, while still passing data on to U5;
  * OUT8–OUT11, the FUEL fault LEDs, never lit at all, even as the first
    command after power-up.

  Everything around it measured normal: GND 0 Ω, VDD 5.0 V steady, `R-EXT`
  1.23 V, `OE` 0 V. Every output sat at 3.5 V at rest, the same on the FUEL
  LEDs as on the working GPWS and BATT ones, so the LEDs were sound.
  **Replacing U8 with a new TLC5927 fixed it**: two full test cycles, every
  LED on every pass. The most likely cause is the original 56–156 Ω
  `R-EXT`, which held its outputs at the 120 mA maximum, plus the >100 mA
  tests on it. That cannot be proven, but nothing else set U8 apart.
* **Short detection is ruled out.** The TLC5927 flags an LED as shorted
  when its output sits above 2.4–3.1 V with the channel on. At the
  currents used here, amber and green LEDs leave about 3 V on their
  outputs, inside that window, and that looked like a cause for a while.
  But U5 drives several amber LEDs in the same conditions and never locked,
  and a new U8 fixed the problem without any change to the voltages. Nothing
  in the new design needs to keep the outputs below the window.

### Backlight dimming

* Low-side N-MOSFET (**IRLIZ44N**, as on the FCU dimmer: logic level, isolated
  TO-220 tab), gate from **D44** through 100 Ω, 10k pull-down. All eight
  section returns join at its drain.
* D44 low or not driven → backlight off. PWM from a MobiFlight output on
  D44, 0–255, meant to follow the INTEG LT knob.
* D46 switches the TLC5927 supply (see *Hot-plug lock-up*).

### Connectors on the mainboard

* 8 shrouded IDC headers: 10, 14, 14, 16, 16, 20, 20 and 26 pins, 136 in all
* 9 screw terminals, 2-pole: one 5.08 mm for the 9 V in, eight 3.5 mm
  (Phoenix PT 1,5/2-3,5) for the backlight (pin 1 `+9V_BL`, pin 2 `BL_RET`,
  the switched return)
* USB-B for the extension
* Optional, if space allows: an unfitted SIP pull-up network next to each
  header, to fit only if a long ribbon ever shows bouncing inputs

### Layout

In v1 coordinates the board sits at x 32–169, y 134.5–223.5, under EXT LT
and the lower edge of GPWS. The layout is drawn in that frame, so each part
of it can be checked against the section boards above.

* **Left edge, towards the case wall:** the 9 V terminal, the power input
  and the MIC29302 at the top; USB-B, CH340G, TPS2115A, ISP header and JP1
  below.
* **Top, on the GPWS side:** the eight ribbon headers in three rows, pin 1
  on the left, each labelled with the board it goes to.
* **Middle:** the ATmega2560 with its crystal, the PCA9548A with the 3.3 V
  regulator and the address switch, and the four TLC5927 in a 2 × 2 block.
* **Front edge:** the eight backlight terminals, labelled, with + and −,
  wire entry towards the edge; the IRLIZ44N lying flat beside them.
* **Bottom side:** the small 1206 parts of the dense groups, each under its
  chip: MCU decoupling, TLC5927 R-EXT and VDD capacitors, CLK/LE/SDI series
  resistors, I2C pull-ups, CH340G parts, supply-switch resistors. Everything
  else is on top.
* **Overhead clearance:** EXT LT's J1 and J2 hang over the mainboard. They
  sit above the TLC5927 block, where nothing is taller than a SOIC, and not
  above any ribbon header, where the two plugs would meet.
* **Silkscreen:** every part has its value or part number on the side it is
  on, the TLC5927 are marked with their LED colour, and the terminals and
  headers with their board. The texts are placed by script, clear of pads,
  of each other and of the edge.
* **Copper:** GND poured on both layers. Track widths:
  * 0.8 mm for `VIN_RAW`, `+9V`, `+9V_BL`, `BL_RET`;
  * 0.5 mm for `+9V_REG` and `+5V_LED`;
  * 0.35 mm for `5V_EXT` and `VBUS`, the widest that enters the TPS2115A's
    0.65 mm pins (about 1 A);
  * 0.25 mm with 0.2 mm clearance for the rest. Some escapes between TQFP and
    SOIC pins are 0.19 mm; the minimum is set to 0.15 mm, within JLCPCB's
    0.127 mm.

**Status:** `Mainboard/OVHD_Mainboard.kicad_pcb`.
* 123 parts, 65 of them on the bottom.
* Routed with Freerouting: 3803 track segments, 367 vias.
* DRC with every warning on: 0, nothing unconnected, no schematic-parity
  issues.
* Every pin of the eight ribbon headers and the eight backlight terminals
  was checked against J1 and J2 of its section board: all 152 carry the
  same net on the same pin number.

### Schematic status

The mainboard schematic is drawn: `Mainboard/OVHD_Mainboard`, seven sheets
(Power, USB and supply, MCU, I2C, Annunciators, Connectors), 123 parts,
labels on pins rather than wires. ERC: no errors, no warnings. The exported
netlist was checked against this document: every `.mfmc` button runs from
its v1 ATmega pin to exactly one ribbon pin, every annunciator from its
TLC5927 output to exactly one ribbon pin, and all 136 IDC pins match the
pinout tables below.

Parts chosen while drawing, open to review:

| Where | Part |
|---|---|
| 9 V input | 1N5822 reverse diode (as the FCU PSU), SMBJ12CA TVS, 470 µF 25 V electrolytic |
| Fuses | MF-RHT200 on both branches (backlight, regulator) |
| 5 V | MIC29302WU, 3.6k / 1.2k as v1 |
| Supply selector, USB, ISP, JP1, 3.3 V | the FCU mainboard's circuit, pin for pin |
| Anode and TLC5927 supply switches | AO3401A (SOT-23) driven by BS170 (TO-92), 10k / 100R / 100k; R527 4.7k bleeding `+5V_TLC` |
| Backlight dimmer | IRLIZ44N, 100R gate, 10k pull-down |
| Annunciator drivers | TLC5927IDWR, DW24-M footprint, R-EXT 1k, 1k series on CLK/LE/SDI |
| Ribbons | shrouded IDC headers 2x5 to 2x13; backlight on 3.5 mm 2-pole terminals (Phoenix PT 1,5/2-3,5) |

## Section boards

Each one carries its switches, its annunciator LEDs and its backlight LEDs
with their resistors. It has no ICs, and the annunciator LEDs have no
resistors, because the TLC5927 is a current sink. Anodes go to `+5V_LED` from
the ribbon, cathodes back down the ribbon to their TLC5927 output.

### Layout rules and status

* **Parts:** everything from v1 stays at its v1 coordinates, and the build
  script checks every pad against the v1 board. New parts (the IDC header,
  the JST PH and any new resistor) go on the back.
* **Sheet:** each board is moved by a whole number of millimetres onto the
  middle of its A4 sheet, and its grid origin is set to where v1's (0, 0)
  now lies. With coordinates relative to the grid origin, KiCad shows the v1
  positions. The offset is in the title block (APU: v2 = v1 + (−54, −80) mm).
* **Connectors:** SMD, on the back, on the edge nearest the mainboard:
  `IDC-Header_2xNN_P2.54mm_Vertical_SMD` and
  `JST_PH_B2B-PH-SM4-TB_1x02-1MP_P2.00mm_Vertical` (pin 1 `+9V_BL`, pin 2
  `BL_RET`). Keep them at least ~4 mm from a mounting hole, where the case
  insert bears on the back.
* **Silkscreen:** everything needed to solder the board without the
  schematic goes on the silkscreen of the side the part is on:
  * `K` at every backlight LED cathode, and the annunciator colour and
    function (`FAULT amber`, `ON blue`, `AVAIL green`);
  * resistor values;
  * pin 1 of the Korry and the IDC;
  * `+` and `-` at the JST;
  * the mainboard connector each cable goes to.
* **Libraries:** `Libraries/OVHD.pretty` and `Libraries/OVHD.kicad_sym`
  hold the custom parts every board shares. The footprints are extracted
  from the v1 board, because three of their four source libraries are no
  longer installed: Korry G-Switch PS-7054DVB-6PN, the rectangular
  annunciator LED, the ADR rotary and the toggle. The symbols (Korry,
  toggle) come from the v1 schematic, with every pin made passive.
* **Rules:** 2 layers, 1.6 mm. Tracks are 0.3 mm, or 0.6 mm for `GND`,
  `+5V_LED`, `+9V_BL` and `BL_RET`. Clearance is 0.25 mm and vias
  0.8/0.4 mm. Routed with Freerouting 2.4.1 (Java 25 or later), then
  checked with KiCad DRC.

| Board | Status |
|---|---|
| APU | `Section_APU/`, the trial board. Schematic 24 parts, ERC 0. PCB 39 × 79.5 mm, routed, DRC 0, 0 unconnected, 0 schematic-parity issues. J1 (2x5) and J2 on the left edge, towards the mainboard. D148 is a single-LED string with R3 330 Ω on the back |
| GPWS | `Section_GPWS/`. Schematic 38 parts, ERC 0. PCB 159.5 × 39 mm, routed, DRC 0, 0 unconnected, 0 schematic-parity issues. 4 Korry, 6 annunciators, 4 strings of two and D139 on its own with R5 330 Ω (its v1 partner D140 and resistor R75 go to EXT LT). J1 (2x7) and J2 along the top edge on the right: the bottom band, nearer the mainboard, is taken by the Korry pins, the annunciator LEDs and the frame holes, and a 2x7 shroud does not fit there |
| AIR COND | `Section_AIRCOND/`. Schematic 46 parts, ERC 0. PCB 150.5 × 39 mm, routed, DRC 0, 0 unconnected, 0 schematic-parity issues. 4 Korry, 8 annunciators, 6 strings of two and D142 on its own: its v1 resistor R76 is on this board, so it stays where it is and becomes 330 Ω (its v1 partner D141 goes to SIGNS). R57 belongs to D73's string and moves to ELEC. J1 (2x8) and J2 along the top edge on the left, the side nearest the mainboard |
| EXT LT | `Section_EXTLT/`. Schematic 61 parts, ERC 0. PCB 159.5 × 79.5 mm, routed, DRC 0, 0 unconnected, 0 schematic-parity issues. 8 toggles (LDG LIGHT L/R, NOSE LIGHT and NAV & LOGO on both contacts 1 and 3), 15 strings of two and D140 on its own with R16 330 Ω on the back (its v1 partners D139 and R75 were on GPWS). No annunciators, so no `+5V_LED` on this ribbon. J1 (2x7) and J2 at the right, over the mainboard |
| ADIRS | `Section_ADIRS/`. Schematic 41 parts, ERC 0. PCB 132.5 × 81.5 mm, routed, DRC 0, 0 unconnected, 0 schematic-parity issues. 3 ADR rotaries (positions 1 OFF, 2 NAV, 3 ATT, common on pin 9), GND CTL Korry and its annunciator, 9 strings of two, and J3, the ADIRS OLED socket, where it was. **The middle rotary is IR 3 and the right one IR 2**, as on the A320 and in the `.mfmc`: the copper says so, although the v1 footprints were labelled the other way round. J1 (2x10) and J2 on the back between ADR 1 and ADR 3 |
| FUEL | `Section_FUEL/`. Schematic 55 parts, ERC 0. PCB 177.5 × 40 mm, routed, DRC 0, 0 unconnected, 0 schematic-parity issues. 7 Korry, 14 annunciators, 7 strings of two. Three of them had their resistor across the seam, on the ELEC side (R66, R64, R61): each gets a new 150 Ω on the back beside its LEDs (R2, R4, R7). The seam with ELEC is inset 1 mm instead of 1.5, because D102 and D104 sit 2 mm from it. J1 (2x13) and J2 on the back along the top edge, left of the middle M3 hole |
| ELEC | `Section_ELEC/`. Schematic 35 parts, ERC 0. PCB 177.5 × 39.5 mm, routed, DRC 0, 0 unconnected, 0 schematic-parity issues. 3 Korry, 5 annunciators, 5 strings of two; D72/D73 had R57 across the seam on AIR COND and gets a new 150 Ω (R5) on the back. The BATT 1 and BATT 2 OLED sockets stay where they were (J3 on PCA9548A channel 0, J4 on channel 1, checked on the copper). J1 (2x10) and J2 on the back, top edge, left end |
| SIGNS | `Section_SIGNS/`. Schematic 57 parts, ERC 0. PCB 108.5 × 79.5 mm, routed, DRC 0, 0 unconnected, 0 schematic-parity issues. 3 ANTI ICE Korry, SEAT BELTS and NO SMOKING read on contact 1 (NO SMOKING was on contact 3 on v1: drop its inversion in MobiFlight), EMER EXIT LT on contacts 1 and 3, 6 annunciators, 10 strings of two, and D141 + D149 as a new pair on R79 (their v1 partners D142 and D148 are on AIR COND and APU). J1 (2x8) and J2 on the back along the left edge, towards the mainboard |

### Backlight strings

Today there are 61 strings, each of 2 LEDs and one 150 Ω resistor on 9 V.
A pair on 150 Ω runs at **17 mA** (Stefano's figure for the current
board). 63 strings on v2 make **~1.1 A** of backlight. (The 0.76–0.81 A
measured on the bench for the whole board is not reliable enough to size
anything on.) With ~1 A on the regulator branch in a light test, the worst
case is ~2.1 A, within the 3 A of the 9 V adapter. The MF-RHT200 on the
backlight branch holds 2 A.

The split changes three things:

* **Three strings span two panels** and have to be rewired:
  D139 (GPWS) + D140 (EXT LT), D141 (SIGNS) + D142 (AIR COND),
  D148 (APU) + D149 (SIGNS). D141 and D149 then pair up on SIGNS.
* That leaves **GPWS, AIR COND, EXT LT and APU with an odd LED count**. Each
  gets one single-LED string on 9 V. For the same current as a pair, and so
  the same brightness, R = V / (2·I) + 75 Ω, which follows from
  V = 2·V_F + 150 Ω·I for the pair. With the rail at ~8.6 V after the reverse
  diode and 17 mA per string, that is ~328 Ω: **330 Ω**. (An earlier draft
  used 470 Ω, from an estimated 11 mA per string, which was wrong.)
* **Four strings have both LEDs on one panel but their resistor across the
  seam**: R57, R61, R64 and R66. The resistor moves next to its LEDs.

| Board | Strings | Backlight current ≈ |
|---|---|---|
| ADIRS | 9 | 155 mA |
| FUEL | 7 | 120 mA |
| ELEC | 5 | 85 mA |
| GPWS | 4 + 1 single | 85 mA |
| AIR COND | 6 + 1 single | 120 mA |
| EXT LT | 15 + 1 single | 270 mA |
| APU | 2 + 1 single | 50 mA |
| SIGNS | 11 | 185 mA |
| **Total** | **63** | **~1.1 A** |

22–24 AWG is ample for the largest.

### Ribbon pinouts

Conventions:

* Pin numbers are IDC numbers. Consecutive numbers are neighbouring
  conductors in the ribbon.
* Pin 1 is always GND. Inputs sit together, then a GND, then the
  annunciators, then `+5V_LED`. Where there are displays, SDA and SCL are
  never neighbours: a GND lies between them.
* Inputs are listed in physical order, left to right, and switch commons
  return on GND. `Dnn` is the Arduino Mega pin, as in the `.mfmc`.
* `L`*n* is bit *n* of the `ANN_LOWER` chain (latch D23, clock D24, data
  D22): U6 carries bits 0–15 (white) and U7 bits 16–31 (blue). `U`*n* is bit
  *n* of `ANN_UPPER` (latch D27, clock D26, data D25): U8 carries bits 0–15
  (amber) and U5 bits 16–31 (green and amber).

All 49 inputs and all 44 annunciators were checked by **following the copper**
of the as-built board: the project as sent to JLCPCB on 3 March 2025,
restored in `Kicad Files/`. Net names were not trusted, because schematic and
copper disagree in places. Every button in the `.mfmc` reaches exactly one
switch contact, and every annunciator bit reaches exactly one LED.

#### ADIRS — 20 pins

| Pin | Signal | | Pin | Signal |
|---|---|---|---|---|
| 1 | GND | | 2 | ADIR 1 OFF — D49 |
| 3 | ADIR 1 NAV — D14 | | 4 | ADIR 1 ATT — D15 |
| 5 | ADIR 3 OFF — D48 | | 6 | ADIR 3 NAV — D63 |
| 7 | ADIR 3 ATT — D62 | | 8 | ADIR 2 OFF — D47 |
| 9 | ADIR 2 NAV — D65 | | 10 | ADIR 2 ATT — D64 |
| 11 | GND CTL — D69 | | 12 | GND |
| 13 | GND CTL ON — L16 | | 14 | +5V_LED |
| 15 | GND | | 16 | +3V3 (OLED) |
| 17 | SCL2 | | 18 | GND |
| 19 | SDA2 | | 20 | GND |

The middle rotary (PCB label `ADR_2`) is ADIR 3 and the right one (`ADR_3`)
is ADIR 2. That is not a mistake: the A320 panel reads IR 1, IR 3, IR 2 from
left to right, and the `.mfmc` names follow the aircraft.

#### FUEL — 26 pins

| Pin | Signal | | Pin | Signal |
|---|---|---|---|---|
| 1 | GND | | 2 | LT TK PUMP 1 — D17 |
| 3 | LT TK PUMP 2 — D16 | | 4 | CTR TK PUMP 1 — D8 |
| 5 | X FEED — D4 | | 6 | CTR TK PUMP 2 — D9 |
| 7 | RT TK PUMP 1 — D6 | | 8 | RT TK PUMP 2 — D7 |
| 9 | GND | | 10 | LT 1 OFF — L5 |
| 11 | LT 1 FAULT — U12 | | 12 | LT 2 OFF — L6 |
| 13 | LT 2 FAULT — U11 | | 14 | CTR 1 OFF — L7 |
| 15 | CTR 1 FAULT — U10 | | 16 | X FEED ON — L13 |
| 17 | X FEED OPEN — U18 | | 18 | CTR 2 OFF — L11 |
| 19 | CTR 2 FAULT — U9 | | 20 | RT 1 OFF — L10 |
| 21 | RT 1 FAULT — U8 | | 22 | RT 2 OFF — L9 |
| 23 | RT 2 FAULT — U16 | | 24 | +5V_LED |
| 25 | +5V_LED | | 26 | GND |

Two anode pins: 14 LEDs at ~19 mA are about 270 mA in a light test. The PCB labels the
centre-tank pumps `L_XFER` and `R_XFER`, and the `.mfmc` and the project
call them CTR TK PUMP 1 and 2. They are the same switches.

#### ELEC — 20 pins

| Pin | Signal | | Pin | Signal |
|---|---|---|---|---|
| 1 | GND | | 2 | CREW SUPPLY — D66 |
| 3 | BATT 1 — D67 | | 4 | BATT 2 — D68 |
| 5 | GND | | 6 | CREW SUPPLY OFF — L4 |
| 7 | BATT 1 OFF — L15 | | 8 | BATT 1 FAULT — U14 |
| 9 | BATT 2 OFF — L14 | | 10 | BATT 2 FAULT — U13 |
| 11 | +5V_LED | | 12 | GND |
| 13 | +3V3 (OLEDs) | | 14 | SCL0 (BATT 1) |
| 15 | GND | | 16 | SDA0 (BATT 1) |
| 17 | GND | | 18 | SCL1 (BATT 2) |
| 19 | GND | | 20 | SDA1 (BATT 2) |

#### GPWS — 14 pins

| Pin | Signal | | Pin | Signal |
|---|---|---|---|---|
| 1 | GND | | 2 | TERR — D57 |
| 3 | SYS — D58 | | 4 | G/S MODE — D59 |
| 5 | LDG FLAP 3 — D60 | | 6 | GND |
| 7 | TERR OFF — L0 | | 8 | TERR FAULT — U4 |
| 9 | SYS OFF — L1 | | 10 | SYS FAULT — U5 |
| 11 | G/S MODE OFF — L2 | | 12 | LDG FLAP 3 OFF — L3 |
| 13 | +5V_LED | | 14 | GND |

#### AIR COND — 16 pins

| Pin | Signal | | Pin | Signal |
|---|---|---|---|---|
| 1 | GND | | 2 | APU BLEED — D61 |
| 3 | PACK 1 — D41 | | 4 | PACK 2 — D40 |
| 5 | EXT PWR — D39 | | 6 | GND |
| 7 | APU BLEED ON — L25 | | 8 | APU BLEED FAULT — U29 |
| 9 | PACK 1 OFF — L8 | | 10 | PACK 1 FAULT — U30 |
| 11 | PACK 2 OFF — L12 | | 12 | PACK 2 FAULT — U31 |
| 13 | EXT PWR ON — L21 | | 14 | EXT PWR AVAIL — U19 |
| 15 | +5V_LED | | 16 | GND |

#### EXT LT — 14 pins

| Pin | Signal | | Pin | Signal |
|---|---|---|---|---|
| 1 | GND | | 2 | STROBE — D31 |
| 3 | BEACON — D32 | | 4 | WING — D33 |
| 5 | NAV & LOGO 1 — D34 | | 6 | NAV & LOGO OFF — D35 |
| 7 | GND | | 8 | RWY TURN OFF — D30 |
| 9 | LDG L ON — D10 | | 10 | LDG L RETRACT — D11 |
| 11 | LDG R ON — D12 | | 12 | LDG R RETRACT — D13 |
| 13 | NOSE T.O. — D37 | | 14 | NOSE OFF — D36 |

Top row first, then bottom row. No annunciators and no `+5V_LED`.

#### APU — 10 pins

| Pin | Signal | | Pin | Signal |
|---|---|---|---|---|
| 1 | GND | | 2 | MASTER SW — D28 |
| 3 | START — D29 | | 4 | GND |
| 5 | MASTER SW ON — L17 | | 6 | MASTER SW FAULT — U23 |
| 7 | START ON — L24 | | 8 | START AVAIL — U24 |
| 9 | +5V_LED | | 10 | GND |

#### SIGNS — 16 pins

| Pin | Signal | | Pin | Signal |
|---|---|---|---|---|
| 1 | GND | | 2 | ANTI ICE WING — D54 |
| 3 | ANTI ICE ENG 1 — D55 | | 4 | ANTI ICE ENG 2 — D56 |
| 5 | SEAT BELTS — D19 (contact 1) | | 6 | NO SMOKING — D5 (contact 1) |
| 7 | EMER EXIT LT ON — D2 | | 8 | EMER EXIT LT OFF — D3 |
| 9 | GND | | 10 | WING ON — L18 |
| 11 | WING FAULT — U21 | | 12 | ENG 1 ON — L19 |
| 13 | ENG 1 FAULT — U20 | | 14 | ENG 2 ON — L20 |
| 15 | ENG 2 FAULT — U22 | | 16 | +5V_LED |

SEAT BELTS and NO SMOKING are on-off toggles, so they need one contact
each. The v1 copper wires both contacts of each: SEAT BELTS contact 1 to D19
and contact 3 to D18, NO SMOKING contact 1 to D38 and contact 3 to D5. The
v1 schematic calls the unused ones `…_OFF`, but they are not buttons. v2
keeps only contact 1 of each. EMER EXIT LT, NAV & LOGO, NOSE and
both LDG lights really have three positions, and keep both contacts.

**Lever up closes contact 1, the lower pin, on every toggle.** Every
single-contact toggle is read on contact 1. On v1 NO SMOKING alone was read
on contact 3 (D5), and the MobiFlight row was inverted to make up for it.
On v2 D5 moves to contact 1. **When moving to v2, remove the inversion on
the NO SMOKING row.** The three-position toggles keep both contacts on the
same pins as v1, contact 1 up and contact 3 down.

**Toggle parts in the BOM.** The v1 schematic gives all eleven toggles the
E-Switch MPN 100SP1T1B4M2QE, which is not what is fitted. The v2 schematic
gives them no part number; only the footprint name, kept from v1, still
carries the E-Switch one. They are generic three-terminal PCB-pin lever
toggles, from AliExpress and fitted by hand, not orderable from JLCPCB:

* ON-OFF-ON (5): LDG L, LDG R, NOSE, NAV & LOGO, EMER EXIT LT
* ON-OFF (6): WING, BEACON, STROBE, RWY TURN, SEAT BELTS, NO SMOKING

The v1 footprint stays, since they fit it.

### Free resources

* Shift register bits: `ANN_LOWER` 22, 23, 26–31; `ANN_UPPER` 0–3, 6, 7, 15,
  17, 25–28. 20 outputs in all.
* PCA9548A channels 3–7.
* ATmega pins: whatever the `.mfmc` does not use. D44, D45 and D46 are
  taken by the two dimmers and the TLC5927 supply switch.

## Firmware and MobiFlight

* **The pin map does not change,** and the two dimmers are plain
  MobiFlight outputs, which are core.
* **`SF_OVHD` gains one job: powering the TLC5927 up.** Done in 1.2.0
  (`SF_OVHD/TLCSupply.cpp`). When the custom device starts, it pulls the two
  chains' CLK, LE and SDI (D22–D27) low and drives D46 low. 300 ms later it
  drives D46 high, and 20 ms after that it writes both chains again. Message 5
  repeats the sequence on demand. The steps run from the custom device's
  `update()`, so the loop is never blocked. D46 is not in the `.mfmc`, and
  the package's `board.json` no longer offers it: the custom device owns it.
  * R527, 4.7 kΩ from `+5V_TLC` to GND, bleeds the rail's 10.4 µF with a
    time constant of 49 ms. After 300 ms about 10 mV are left.
    The datasheet gives no reset threshold, so the chips go all the way to
    0 V. It costs about 1 mA while they are on. Worth checking on the first
    board: `+5V_TLC` during a reset, with a scope if one is at hand.
* **The `.mfmc` gains two outputs,** `BL_PWM` on D44 (backlight) and
  `ANN_PWM` on D45 (annunciators), both PWM. Done in 1.2.0.
* **The MobiFlight project gains two output rows** for them, typically
  INTEG LT for D44 and ANN LT BRT/DIM for D45. The OLEDs already have
  message 4. None of the existing 96 rows changes.

## Before drawing

1. ~~R-EXT value~~ — 1 kΩ on all four TLC5927, ~19 mA, within the 25 mA
   limit set for the Korry LEDs.
2. ~~Hot-plug re-check with the new U8~~ — still dead on a hot plug, so
   the TLC5927 power-up switch is in the design.
3. ~~Backlight LED V_F~~ — not needed: the single-LED strings get 330 Ω,
   worked out from the pair at 17 mA.
4. ~~Inner panel outlines~~ — not needed. The outer edges are today's PCB
   outline, which already fits the case. The inner cuts follow the panel
   seams on the current layout, where nothing crosses the PCB plane, and
   stay clear of parts, tracks and holes.
5. ~~Mainboard outline~~ — proposed in KiCad. The case is then adapted to it
   in the 3D model.
6. ~~TLC5927 reset~~ — decided: VDD switch from D46, driven by `SF_OVHD`.
   If an oscilloscope is at hand, a capture of +5V during a hot plug would
   still be worth having.

## Lessons carried into the next version

* **Draw the part that is fitted.** The schematic says DM13A, but the
  board carries TLC5927. They are pin-compatible, with different current
  formulas and a different `OE`. The new schematic uses the TLC5927 symbol,
  with the manufacturer part number in the BOM.
* **Size `R-EXT` from the TLC5927 formula**, 1.25 V / R × 15, and stay inside
  160 Ω–1.9 kΩ. The original 56 Ω + 0–100 Ω trimmer sat past the chip's
  limit over its whole travel.
* **`OE` stays hard-wired to GND.** It is the mode pin, so it gets no PWM,
  no pull-up and no test point that could be touched by accident.
* **Nothing but the resistor on `R-EXT`.** A capacitor there, on the v1
  board, made the chips drop their outputs to under 1 mA as soon as two or
  three were on together. Follow the datasheet's application circuit, and
  test several outputs on together, not only the sequential test.
* **The annunciator drivers need a clean power-up.** On a hot-plugged
  supply they can come up with frozen outputs. The new board powers them
  from the firmware, after the rest of the board is up.
* **Spares are at hand:** about twenty TLC5927 from the same Digi-Key order.

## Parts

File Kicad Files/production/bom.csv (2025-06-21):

Designator | Footprint | Quantity | Value | LCSC Part #
C1, C10, C12, C14, C15, C17, C19, C2, C21, C23, C24, C25, C3, C4, C7 | 1206 | 15 | 100nF
C11, C13, C6, C8, C9 | 1206 | 5 | 22pF
C16, C18, C20, C22, C32, C33 | 1206 | 6 | 10uF
C26 | 1206 | 1 | 470nF
C34, C35 | C_Elec_6.3x7.7 | 2 | 100uF
C5 | C_Elec_4x5.4 | 1 | 10uF
D1, D120, D121, D122, D123, D124, D125, D127, D129, D130, D131, D183, D185, D3, D4, D76, D79, D91 | LED_Rectangular_W3.9mm_H1.8mm_FlatTop | 18 | STS
D10, D100, D101, D102, D104, D105, D11, D110, D111, D112, D113, D114, D115, D116, D117, D118, D119, D12, D13, D134, D135, D136, D137, D138, D139, D14, D140, D141, D142, D143, D144, D145, D146, D147, D148, D149, D15, D150, D151, D152, D153, D154, D155, D156, D157, D158, D159, D16, D160, D161, D17, D18, D19, D20, D21, D22, D23, D24, D25, D26, D27, D28, D29, D30, D31, D32, D33, D34, D35, D36, D37, D38, D39, D40, D41, D42, D43, D44, D45, D46, D47, D48, D49, D5, D53, D54, D55, D56, D57, D58, D59, D6, D60, D61, D62, D63, D64, D65, D66, D67, D68, D69, D7, D70, D71, D72, D73, D74, D8, D81, D82, D83, D84, D85, D86, D88, D9, D93, D94, D95, D96, D97, D98 | 1206 | 123 | LED
D103, D106, D107, D108, D109, D126, D128, D132, D133, D178, D184, D188, D190, D2, D50, D51, D52, D75, D77, D78, D80, D87, D89, D90, D92, D99 | LED_Rectangular_W3.9mm_H1.8mm_FlatTop | 26 | ANN
D162 | D_SMA_DO-214-AC | 1 | USB_Protection
D163 | D_SMA_DO-214-AC | 1 | BarrelJack_Prot
D164 | D_SMA_DO-214-AC | 1 | BarrelJackProt_FromLed
I2C_1 | SOP65P640X120-24N | 1 | PCA9548APW
J1 | PinSocket_1x04_P2.54mm_Vertical | 1 | BATT_1_OLED
J2 | PinSocket_1x04_P2.54mm_Vertical | 1 | BATT_2_OLED
J3 | PinSocket_1x04_P2.54mm_Vertical | 1 | ADIRS_OLED
J4 | PinHeader_1x06_P2.54mm_Vertical | 1 | BootLoader
J5 | Barrel_Jack_5.5mmODx2.1mmID_PJ-102A | 1 | PJ-102A | PJ-102A
JP1 | PinHeader_1x03_P2.54mm_Vertical | 1 | Power Selector
P1 | USB_B_OST_USB-B1HSxx_Horizontal | 1 | USB_C_Plug_USB2.0
R1, R53, R54, R55, R6 | 1206 | 5 | 10K
R10, R11, R12, R13, R14, R15, R16, R17, R18, R19, R20, R21, R22, R23, R24, R25, R26, R27, R28, R29, R30, R31, R32, R33, R34, R35, R36, R37, R38, R39, R40, R57, R58, R59, R60, R61, R62, R63, R64, R65, R66, R67, R68, R69, R70, R71, R72, R73, R74, R75, R76, R77, R78, R79, R80, R81, R82, R83, R84, R85, R9 | 1206 | 61 | 150
R2 | 1206 | 1 | 1.5K
R3, R4 | 1206 | 2 | 1K
R41, R42, R43, R44, R45, R46, R7, R8 | 1206 | 8 | 4.7K
R47 | 1206 | 1 | 3.6K
R48 | 1206 | 1 | 1.2K
R49, R50, R51, R52 | 1206 | 4 | 56
R5 | 1206 | 1 | 220
RV1 | potentiometer_3362P | 1 | POT_WHITE
RV2 | potentiometer_3362P | 1 | POT_GREEN
RV3 | potentiometer_3362P | 1 | POT_BLUE
RV4 | potentiometer_3362P | 1 | POT_ORANGE
S1 | Toggle_Switch_100SP1T1B4M2QE | 1 | LDG_LIGHT_L | 100SP1T1B4M2QE
S10 | Toggle_Switch_100SP1T1B4M2QE | 1 | NOSMOKING | 100SP1T1B4M2QE
S11 | Toggle_Switch_100SP1T1B4M2QE | 1 | EMERGENCY_LT | 100SP1T1B4M2QE
S2 | Toggle_Switch_100SP1T1B4M2QE | 1 | LDG_LIGHT_R | 100SP1T1B4M2QE
S3 | Toggle_Switch_100SP1T1B4M2QE | 1 | NOSE_LIGHT | 100SP1T1B4M2QE
S4 | Toggle_Switch_100SP1T1B4M2QE | 1 | NAV&LOGO | 100SP1T1B4M2QE
S5 | Toggle_Switch_100SP1T1B4M2QE | 1 | WING | 100SP1T1B4M2QE
S6 | Toggle_Switch_100SP1T1B4M2QE | 1 | BEACON | 100SP1T1B4M2QE
S7 | Toggle_Switch_100SP1T1B4M2QE | 1 | STROBE | 100SP1T1B4M2QE
S8 | Toggle_Switch_100SP1T1B4M2QE | 1 | RWY TURN | 100SP1T1B4M2QE
S9 | Toggle_Switch_100SP1T1B4M2QE | 1 | SEATBELTS | 100SP1T1B4M2QE
SW1 | G-Switch PS-7054DVB-6PN | 1 | APU_MASTER_SW
SW10 | G-Switch PS-7054DVB-6PN | 1 | APU BLEED
SW11 | G-Switch PS-7054DVB-6PN | 1 | PACK1
SW12 | G-Switch PS-7054DVB-6PN | 1 | PACK2
SW13 | G-Switch PS-7054DVB-6PN | 1 | EXT_PWR
SW14 | G-Switch PS-7054DVB-6PN | 1 | OXY_CREW_SUPPLY
SW15 | G-Switch PS-7054DVB-6PN | 1 | ELEC_BATT_1
SW16 | G-Switch PS-7054DVB-6PN | 1 | ELEC_BATT_2
SW17 | G-Switch PS-7054DVB-6PN | 1 | LT_TK_PUMP_1
SW18 | G-Switch PS-7054DVB-6PN | 1 | LT_TK_PUMP_2
SW19 | G-Switch PS-7054DVB-6PN | 1 | L_XFER
SW2 | G-Switch PS-7054DVB-6PN | 1 | APU_START_SW
SW20 | G-Switch PS-7054DVB-6PN | 1 | X_FEED
SW21 | G-Switch PS-7054DVB-6PN | 1 | R_XFER
SW22 | G-Switch PS-7054DVB-6PN | 1 | RT_TK_PUMP_1
SW23 | G-Switch PS-7054DVB-6PN | 1 | RT_TK_PUMP_2
SW24 | G-Switch PS-7054DVB-6PN | 1 | GND_CTL
SW25 | Rotary_SW_8x1 | 1 | ADR_1
SW26 | Rotary_SW_8x1 | 1 | ADR_2
SW27 | Rotary_SW_8x1 | 1 | ADR_3
SW28 | SW_DIP_SPSTx03_Slide_9.78x9.8mm_W7.62mm_P2.54mm | 1 | SW_DIP_x03
SW3 | G-Switch PS-7054DVB-6PN | 1 | ANTI_ICE_WING_SW
SW4 | G-Switch PS-7054DVB-6PN | 1 | ANTI_ICE_ENG1_SW
SW5 | G-Switch PS-7054DVB-6PN | 1 | ANTI_ICE_ENG2_SW
SW6 | G-Switch PS-7054DVB-6PN | 1 | TERR
SW7 | G-Switch PS-7054DVB-6PN | 1 | SYS
SW8 | G-Switch PS-7054DVB-6PN | 1 | G/S MODE
SW9 | G-Switch PS-7054DVB-6PN | 1 | LDG FLAPS 3
U1 | TQFP100-0.5-14X14MM | 1 | ATMega2560
U2 | SOT-223-3_TabPin2 | 1 | AMS1117-3.3
U3 | SOIC-16_3.9x9.9mm_P1.27mm | 1 | CH340G
U4 | TO-263-5_TabPin3 | 1 | MIC29302WU
U5 | SOP-24_7.5x15.4mm_P1.27mm | 1 | DM13A-GREEN-0-100
U6 | SOP-24_7.5x15.4mm_P1.27mm | 1 | DM13A-WHITE-0-100
U7 | SOP-24_7.5x15.4mm_P1.27mm | 1 | DM13A-BLUE-0-100
U8 | SOP-24_7.5x15.4mm_P1.27mm | 1 | DM13A-ORANGE-0-100
XT12MHZ1 | Crystal_SMD_EuroQuartz_MQ-4Pin_7.0x5.0mm_HandSoldering | 1 | 12MHz
XT16MHZ1 | Crystal_SMD_EuroQuartz_MQ-4Pin_7.0x5.0mm_HandSoldering | 1 | 16MHz

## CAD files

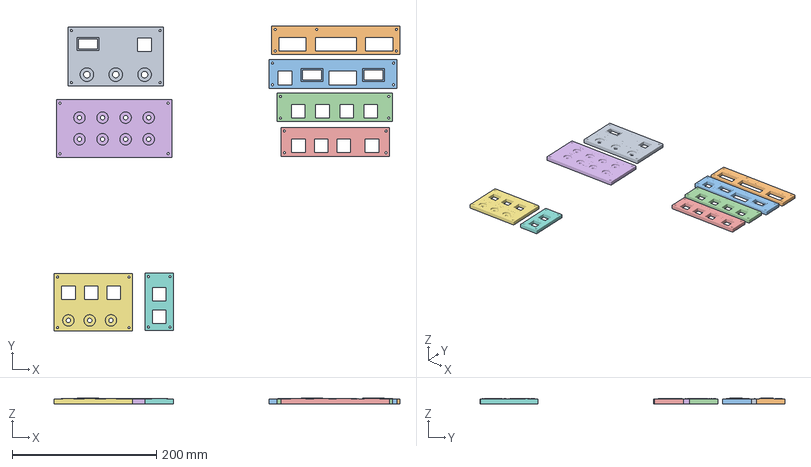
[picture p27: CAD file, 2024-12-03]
STL Files/OVHD_PANEL_COMPLETE.3mf
479.7 x 423.5 x 8.82 mm
OVHD_PANEL_ADIRS_BLACK
OVHD_PANEL_FUEL_BLACK
OVHD_PANEL_ELEC_BLACK
OVHD_PANEL_GPWS_BLACK
OVHD_PANEL_AIRCOND_BLACK
OVHD_PANEL_EXTLT_BLACK
OVHD_PANEL_SIGNS_BLACK
OVHD_PANEL_APU_BLACK

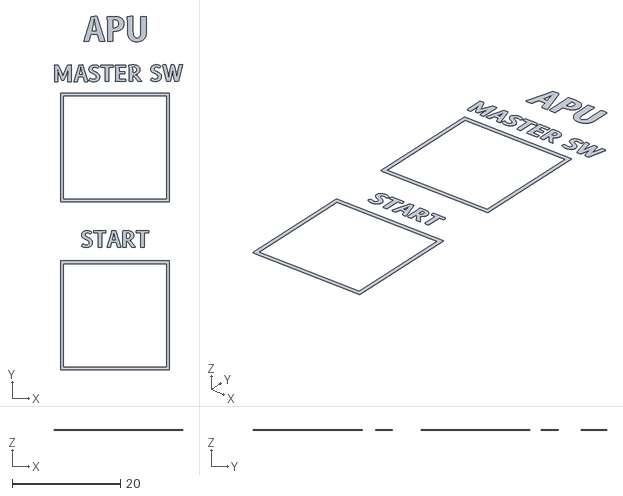
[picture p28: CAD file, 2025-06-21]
STL Files/FaceDown_Printing/OVHD_PANEL_APU_WHITE.stl
23.8 x 65.4 x 0.14

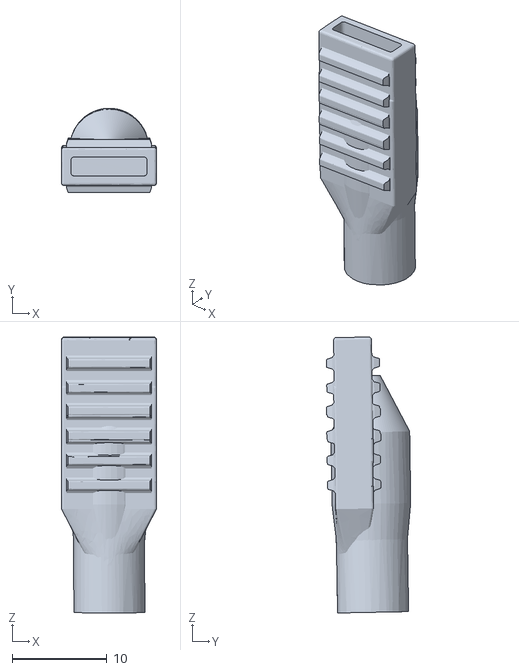
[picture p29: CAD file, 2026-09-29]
STL Files/Levers/obj_9_paddle_knobs.stl
10.0 x 8.89 x 29.1

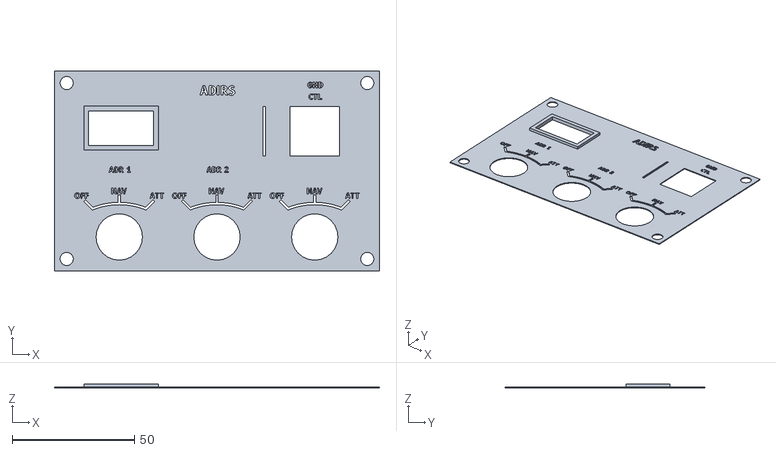
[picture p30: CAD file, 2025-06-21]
STL Files/OVHD_PANEL_ADIRS_GRAY.stl
133.0 x 82.0 x 1.82

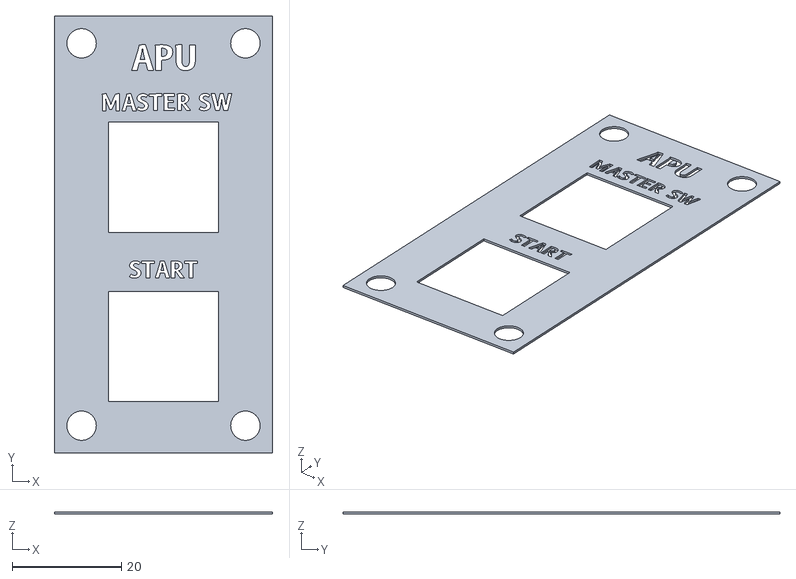
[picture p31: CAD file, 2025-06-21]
STL Files/FaceDown_Printing/OVHD_PANEL_APU_BLACK.stl
40.0 x 80.0 x 0.42

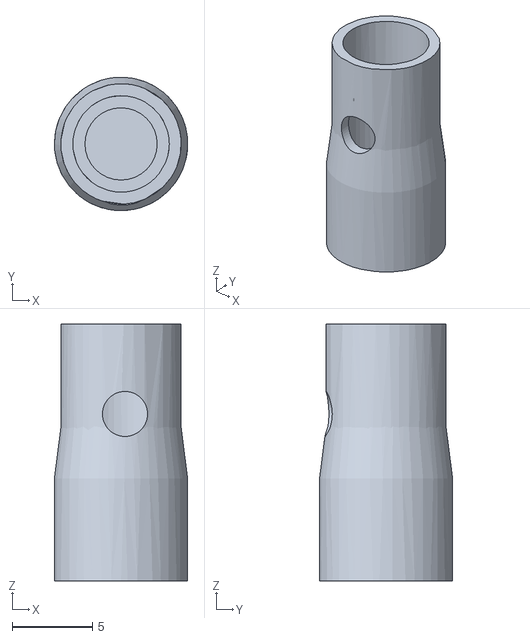
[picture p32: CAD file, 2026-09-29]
STL Files/Levers/obj_5_landing_lts_stem.stl
8.30 x 8.30 x 16.0

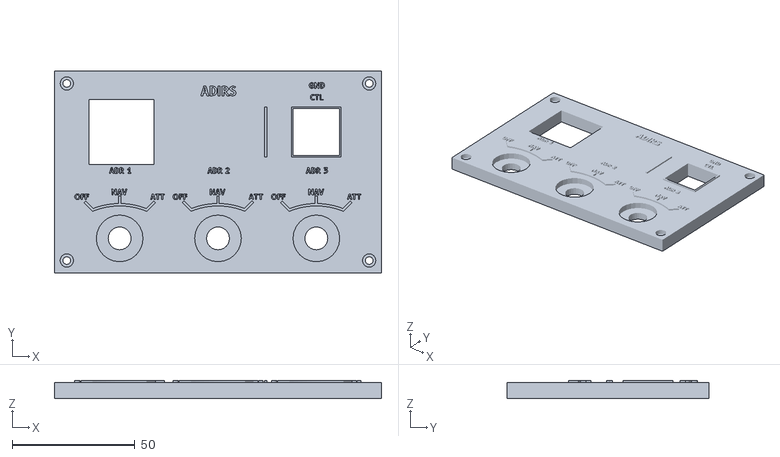
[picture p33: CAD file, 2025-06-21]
STL Files/OVHD_PANEL_ADIRS_TRASP.stl
133.0 x 82.0 x 7.42

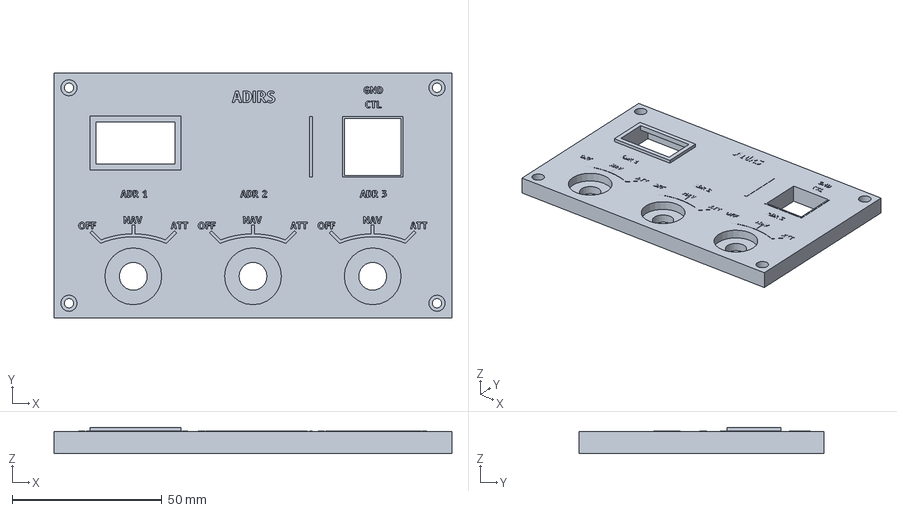
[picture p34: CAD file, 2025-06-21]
STL Files/OVHD_PANEL_ADIRS.3mf
133.0 x 82.0 x 8.82 mm

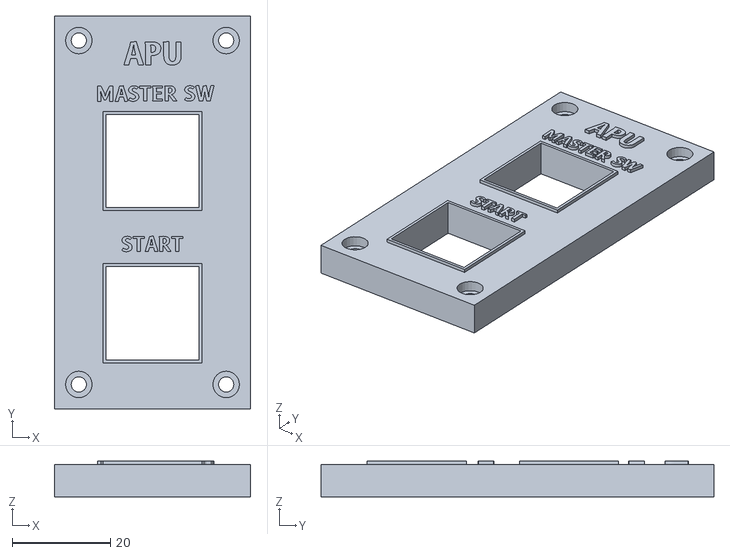
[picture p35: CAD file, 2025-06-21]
STL Files/FaceDown_Printing/OVHD_PANEL_APU_TRASP.stl
40.0 x 80.0 x 7.28

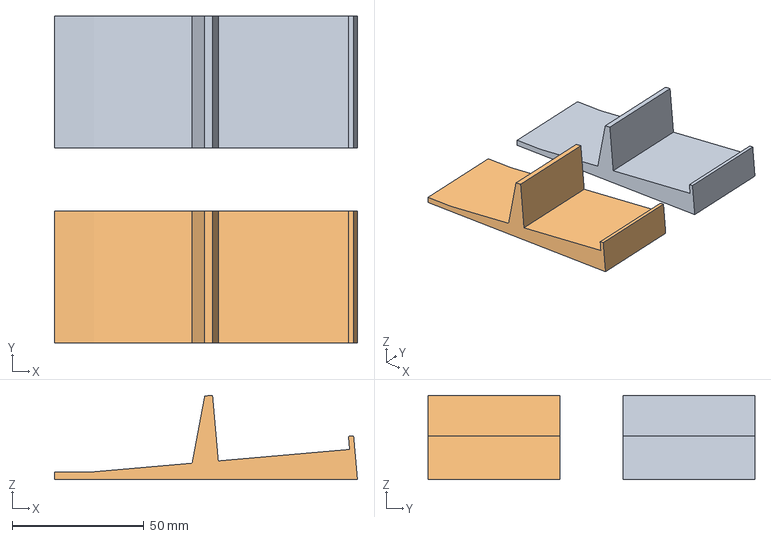
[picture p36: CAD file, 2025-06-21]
STL Files/OVHD_PANEL_SUPPORT.3mf
115.0 x 124.0 x 32.0 mm
OVHD_PANEL_SUPPORT.stl x 2

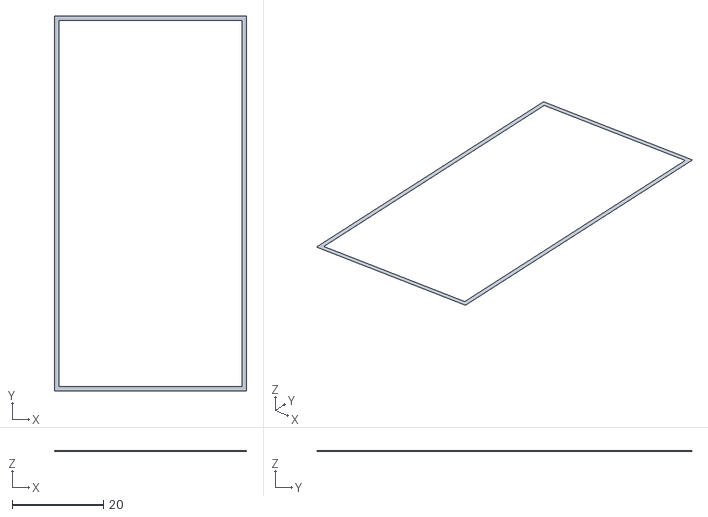
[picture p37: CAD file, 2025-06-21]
STL Files/FaceDown_Printing/OVHD_PANEL_APU_FRAME_WHITE.stl
42.0 x 82.0 x 0.14

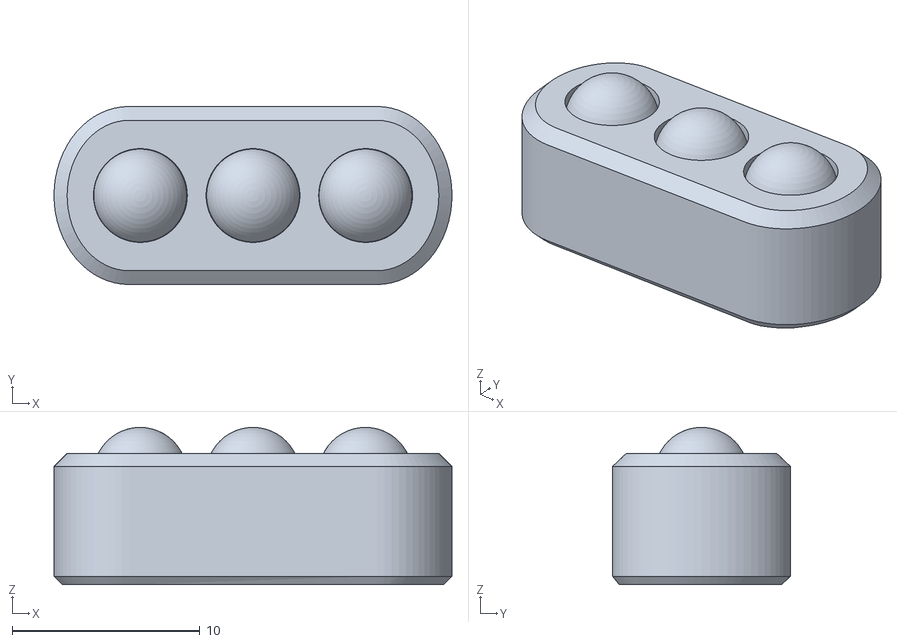
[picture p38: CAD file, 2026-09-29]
STL Files/Levers/obj_6_landing_lts_head.stl
21.2 x 9.49 x 8.38

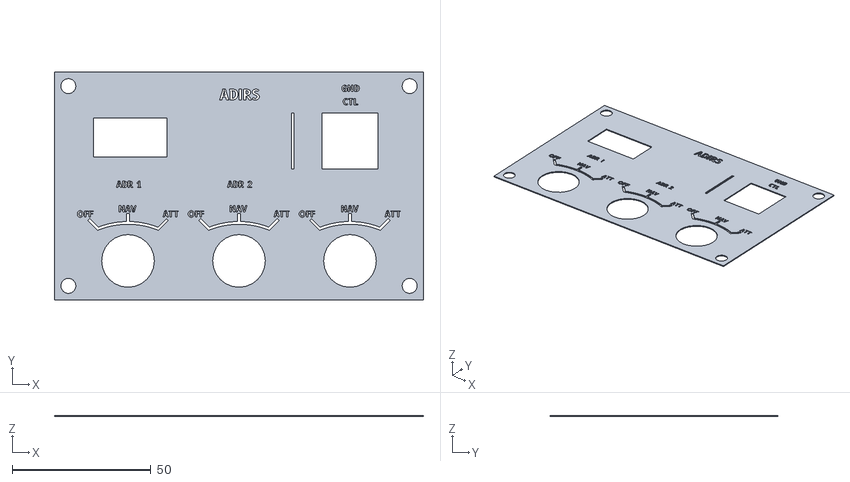
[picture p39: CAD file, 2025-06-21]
STL Files/OVHD_PANEL_ADIRS_BLACK.stl
133.0 x 82.0 x 0.42

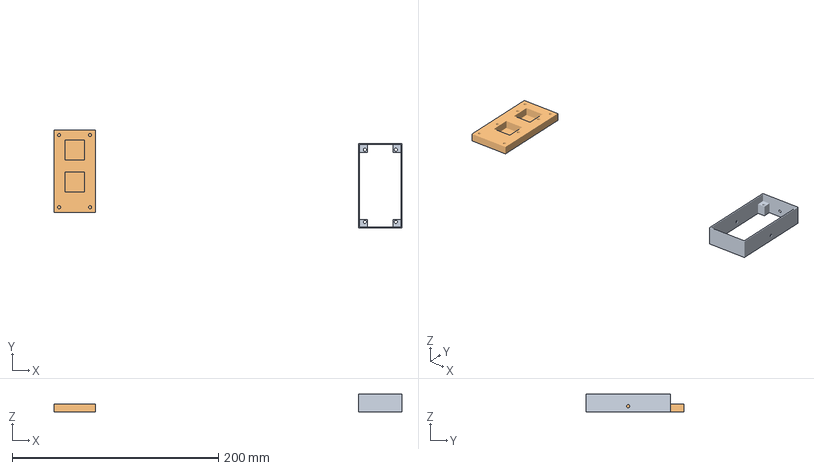
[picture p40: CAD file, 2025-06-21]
STL Files/FaceDown_Printing/OVHD_PANEL.3mf
337.5 x 95.2 x 17.4 mm
OVHD_PANEL_APU_FRAME_TRASP
OVHD_PANEL_APU_BLACK

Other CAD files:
STL Files/FaceDown_Printing/OVHD_PANEL_APU_GRAY.stl
STL Files/Levers/obj_3_paddle_knobs.stl
STL Files/Levers/obj_7_paddle_knobs.stl
STL Files/Levers/obj_1_landing_lts_stem.stl
3D Files/OVHD_KORRY.skp
3D Files/OVHD_KORRY_SHORT.skp
3D Files/OVHD_PANEL_SUPPORT.skp
STL Files/FaceDown_Printing/OVHD_PANEL_APU_FRAME_TRASP.stl
STL Files/FaceDown_Printing/OVHD_PANEL_APU_UPPER_LAYER_TRASP.stl
STL Files/Levers/Landing-Stem-Landing Lights Stem.stl
STL Files/Levers/Screw.stl
STL Files/Levers/landing-lights.stl
STL Files/Levers/obj_2_emer_lts.stl
STL Files/Levers/obj_4_landing_lts_head.stl
STL Files/Levers/obj_8_paddle_knobs.stl
STL Files/Levers/strobe-light.stl
STL Files/Levers/taxi-light.stl
STL Files/OVHD_AVAIL_ON_KORRY_BUTTON_BLACK.stl
STL Files/OVHD_AVAIL_ON_KORRY_BUTTON_TRASP.stl
STL Files/OVHD_FAULT_OFF_KORRY_BUTTON.3mf
STL Files/OVHD_FAULT_OFF_KORRY_BUTTON_BLACK.stl
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

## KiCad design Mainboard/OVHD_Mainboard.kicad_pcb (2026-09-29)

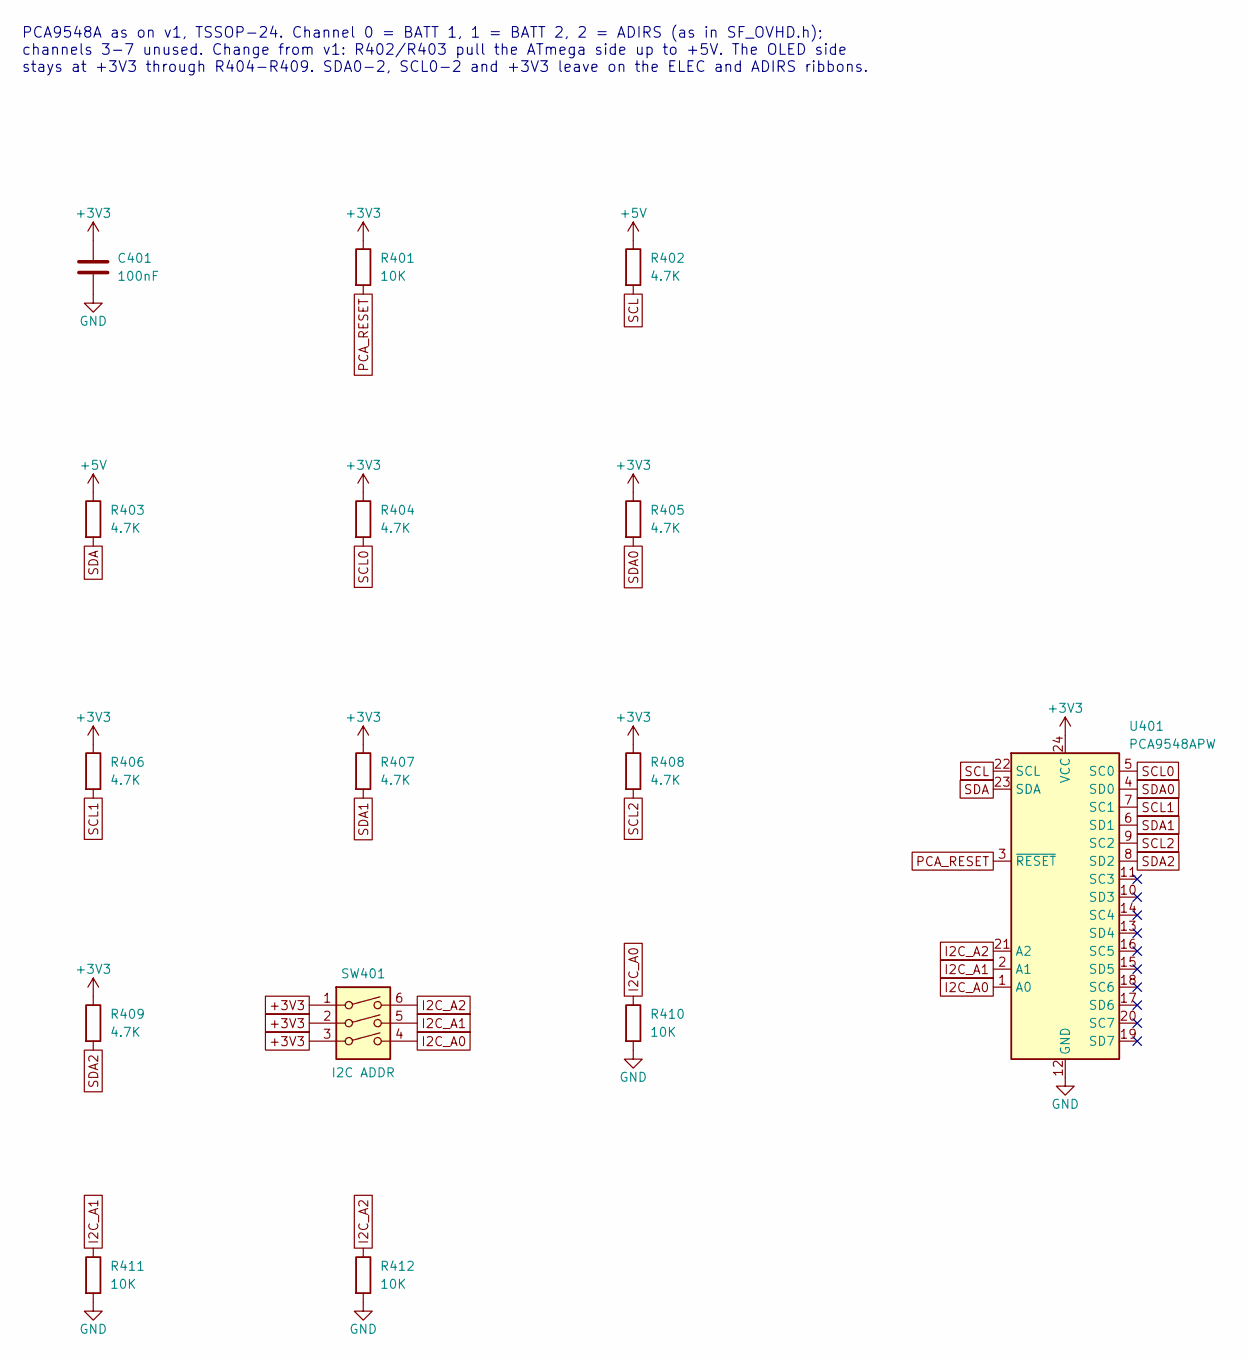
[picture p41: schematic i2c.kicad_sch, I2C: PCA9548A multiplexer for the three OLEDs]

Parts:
C401: 100nF; C_1206_3216Metric_Pad1.33x1.80mm_HandSolder
R401, R410, R411, R412: 10K; R_1206_3216Metric_Pad1.30x1.75mm_HandSolder
R402, R403, R404, R405, R406, R407, R408, R409: 4.7K; R_1206_3216Metric_Pad1.30x1.75mm_HandSolder
SW401: I2C ADDR; SW_DIP_SPSTx03_Slide_9.78x9.8mm_W7.62mm_P2.54mm
U401: PCA9548APW; TSSOP-24_4.4x7.8mm_P0.65mm

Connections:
+3V3: C401.1, R401.1, R404.1, R405.1, R406.1, R407.1, R408.1, R409.1, SW401.1, SW401.2, SW401.3, U401.24 (VCC); also elsewhere on the board
+5V: R402.1, R403.1; also elsewhere on the board
GND: C401.2, R410.2, R411.2, R412.2, U401.12 (GND); also elsewhere on the board
I2C_A0: R410.1, SW401.4, U401.1 (A0)
I2C_A1: R411.1, SW401.5, U401.2 (A1)
I2C_A2: R412.1, SW401.6, U401.21 (A2)
PCA_RESET: R401.2, U401.3 (~RESET)
SCL: R402.2, U401.22 (SCL); also elsewhere on the board
SCL0: R404.2, U401.5 (SC0); also elsewhere on the board
SCL1: R406.2, U401.7 (SC1); also elsewhere on the board
SCL2: R408.2, U401.9 (SC2); also elsewhere on the board
SDA: R403.2, U401.23 (SDA); also elsewhere on the board
SDA0: R405.2, U401.4 (SD0); also elsewhere on the board
SDA1: R407.2, U401.6 (SD1); also elsewhere on the board
SDA2: R409.2, U401.8 (SD2); also elsewhere on the board

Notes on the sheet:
PCA9548A as on v1, TSSOP-24. Channel 0 = BATT 1, 1 = BATT 2, 2 = ADIRS (as in SF_OVHD.h); channels 3-7 unused. Change from v1: R402/R403 pull the ATmega side up to +5V. The OLED side stays at +3V3 through R404-R409. SDA0-2, SCL0-2 and +3V3 leave on the ELEC and ADIRS ribbons.

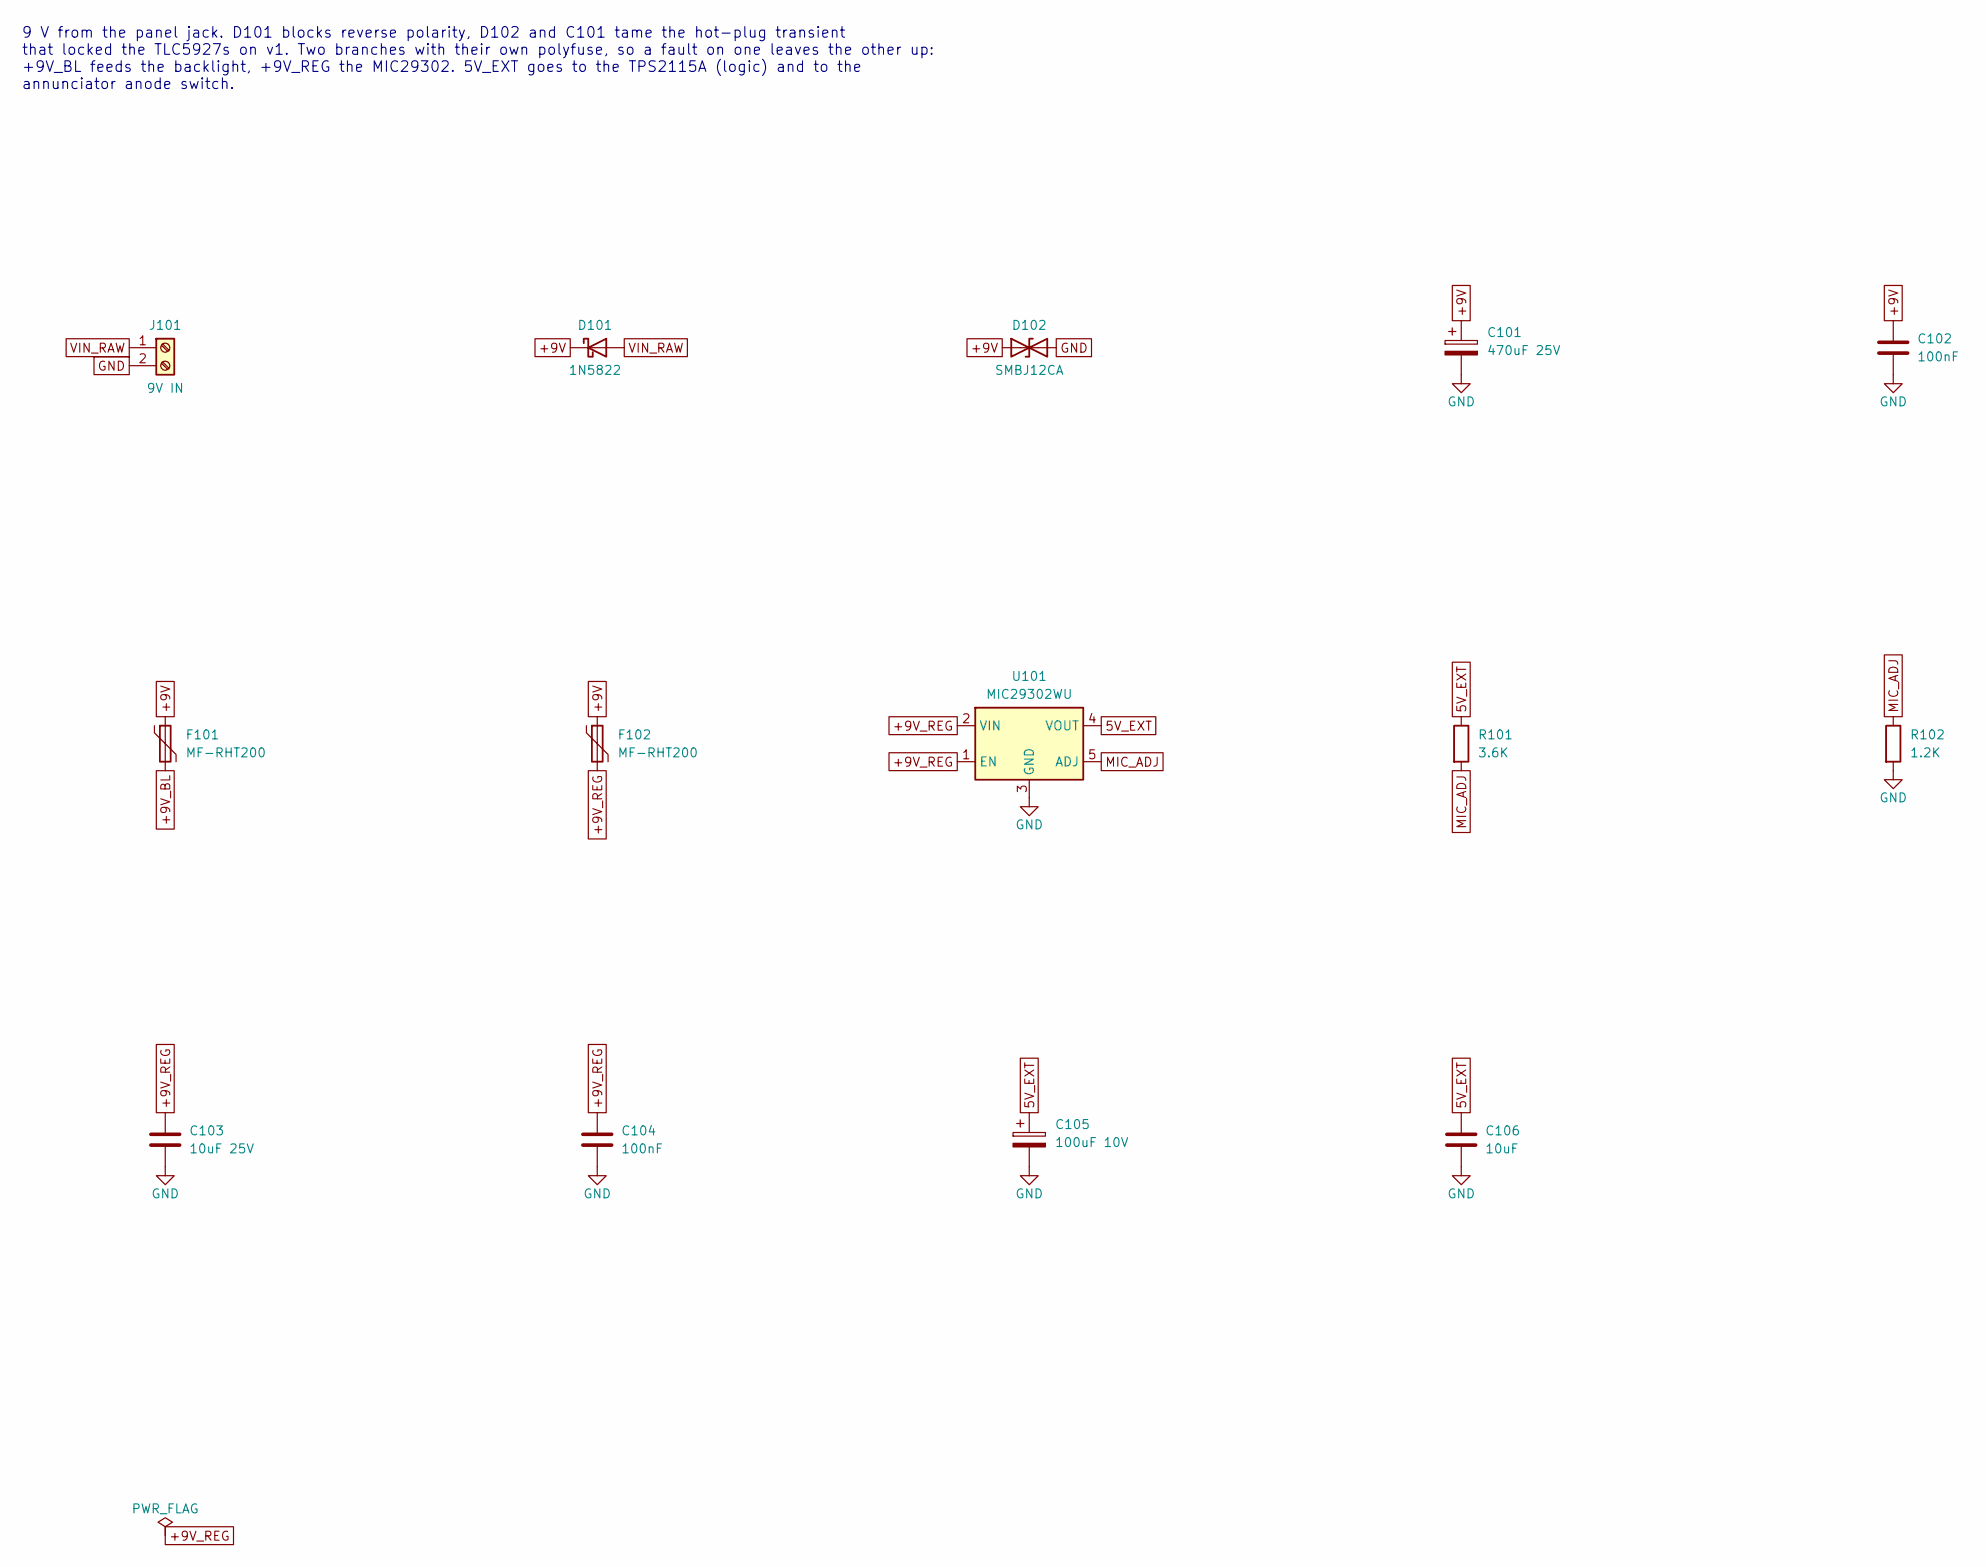
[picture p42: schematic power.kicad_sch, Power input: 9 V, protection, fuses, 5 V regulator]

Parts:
C101: 470uF 25V; CP_Radial_D10.0mm_P5.00mm
C102, C104: 100nF; C_1206_3216Metric_Pad1.33x1.80mm_HandSolder
C103: 10uF 25V; C_1206_3216Metric_Pad1.33x1.80mm_HandSolder
C105: 100uF 10V; CP_Radial_D6.3mm_P2.50mm
C106: 10uF; C_1206_3216Metric_Pad1.33x1.80mm_HandSolder
D101: 1N5822; D_DO-201AD_P15.24mm_Horizontal
D102: SMBJ12CA; D_SMB_Handsoldering
F101, F102: MF-RHT200; Fuse_Bourns_MF-RHT200
J101: 9V IN; TerminalBlock_Phoenix_MKDS-1,5-2-5.08_1x02_P5.08mm_Horizont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
R101: 3.6K; R_1206_3216Metric_Pad1.30x1.75mm_HandSolder
R102: 1.2K; R_1206_3216Metric_Pad1.30x1.75mm_HandSolder
U101: MIC29302WU; TO-263-5_TabPin3

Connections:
5V_EXT: C105.1, C106.1, R101.1, U101.4 (VOUT); also elsewhere on the board
+9V: C101.1, C102.1, D101.1 (K), D102.1 (A1), F101.1, F102.1
+9V_BL: F101.2; also elsewhere on the board
+9V_REG: C103.1, C104.1, F102.2, U101.1 (EN), U101.2 (VIN)
GND: C101.2, C102.2, C103.2, C104.2, C105.2, C106.2, D102.2 (A2), J101.2, R102.2, U101.3 (GND); also elsewhere on the board
MIC_ADJ: R101.2, R102.1, U101.5 (ADJ)
VIN_RAW: D101.2 (A), J101.1

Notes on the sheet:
9 V from the panel jack. D101 blocks reverse polarity, D102 and C101 tame the hot-plug transient that locked the TLC5927s on v1. Two branches with their own polyfuse, so a fault on one leaves the other up: +9V_BL feeds the backlight, +9V_REG the MIC29302. 5V_EXT goes to the TPS2115A (logic) and to 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

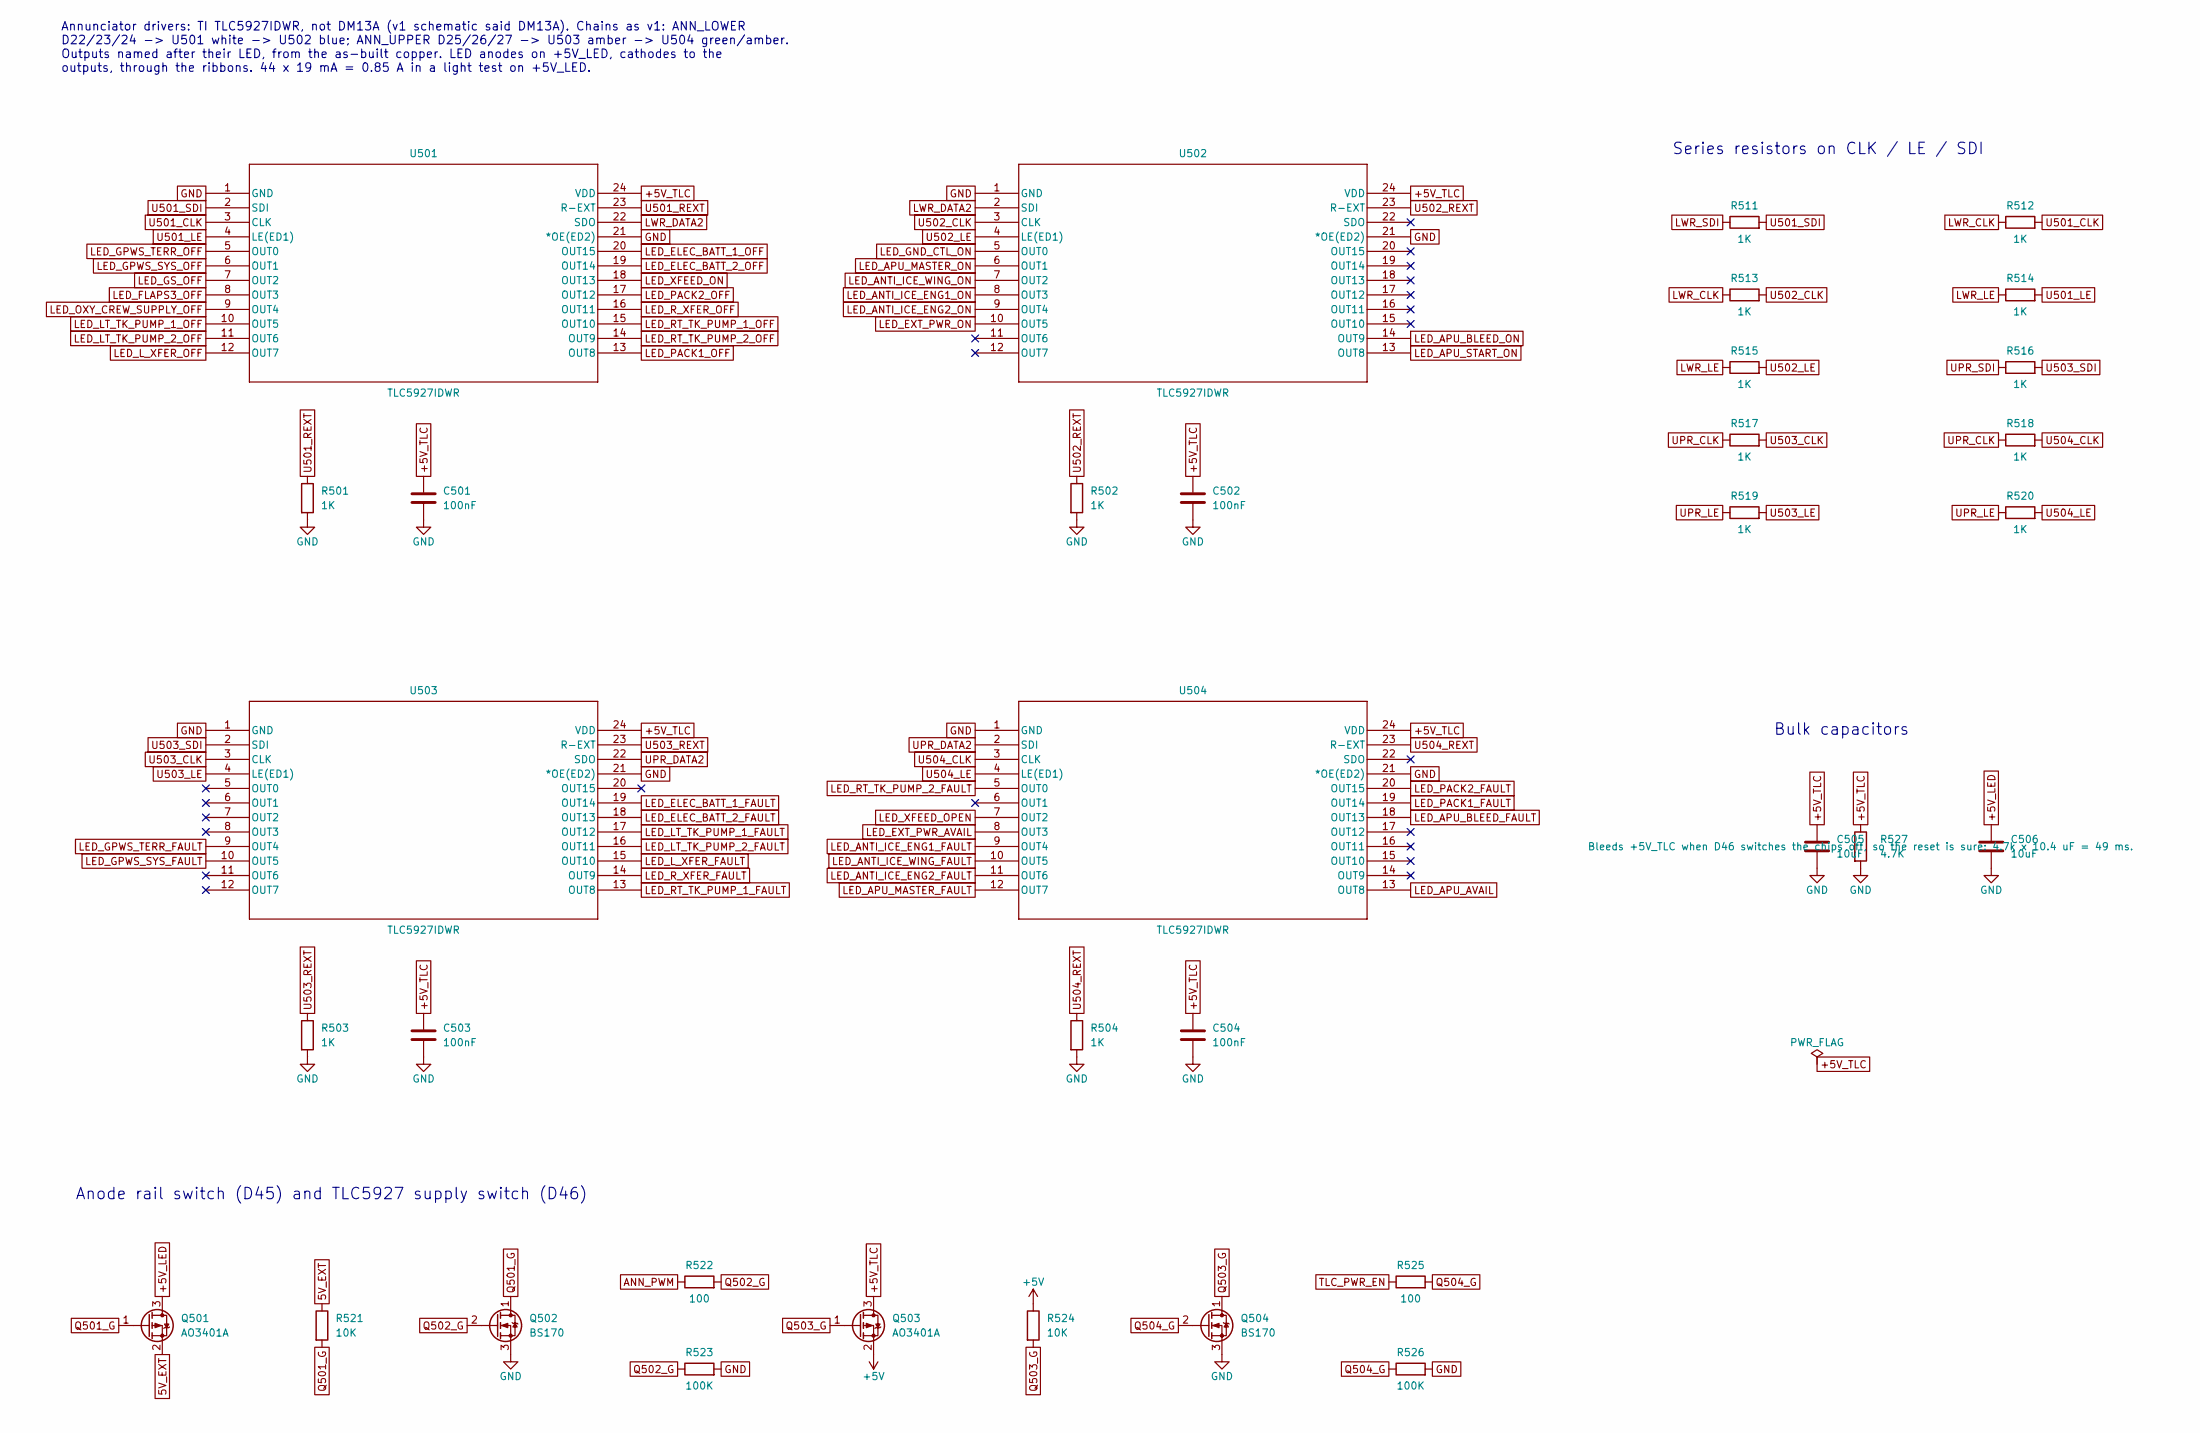
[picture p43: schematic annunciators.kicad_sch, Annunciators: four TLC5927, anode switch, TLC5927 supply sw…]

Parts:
C501, C502, C503, C504: 100nF; C_1206_3216Metric_Pad1.33x1.80mm_HandSolder
C505, C506: 10uF; C_1206_3216Metric_Pad1.33x1.80mm_HandSolder
Q501, Q503: AO3401A; SOT-23
Q502, Q504: BS170; TO-92_Inline
R501, R502, R503, R504, R511, R512, R513, R514, R515, R516, R517, R518, R519, R520: 1K; R_1206_3216Metric_Pad1.30x1.75mm_HandSolder
R521, R524: 10K; R_1206_3216Metric_Pad1.30x1.75mm_HandSolder
R522, R525: 100; R_1206_3216Metric_Pad1.30x1.75mm_HandSolder
R523, R526: 100K; R_1206_3216Metric_Pad1.30x1.75mm_HandSolder
R527: 4.7K; R_1206_3216Metric_Pad1.30x1.75mm_HandSolder
U501, U502, U503, U504: TLC5927IDWR; DW24-M

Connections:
5V_EXT: Q501.2 (S), R521.1; also elsewhere on the board
+5V: Q503.2 (S), R524.1; also elsewhere on the board
+5V_LED: C506.1, Q501.3 (D); also elsewhere on the board
+5V_TLC: C501.1, C502.1, C503.1, C504.1, C505.1, Q503.3 (D), R527.1, U501.24 (VDD), U502.24 (VDD), U503.24 (VDD), U504.24 (VDD)
ANN_PWM: R522.1; also elsewhere on the board
GND: C501.2, C502.2, C503.2, C504.2, C505.2, C506.2, Q502.3 (S), Q504.3 (S), R501.2, R502.2, R503.2, R504.2, R523.2, R526.2, R527.2, U501.1 (GND), U501.21 (*OE(ED2)), U502.1 (GND), U502.21 (*OE(ED2)), U503.1 (GND), U503.21 (*OE(ED2)), U504.1 (GND), U504.21 (*OE(ED2)); also elsewhere on the board
LED_ANTI_ICE_ENG1_FAULT: U504.9 (OUT4); also elsewhere on the board
LED_ANTI_ICE_ENG1_ON: U502.8 (OUT3); also elsewhere on the board
LED_ANTI_ICE_ENG2_FAULT: U504.11 (OUT6); also elsewhere on the board
LED_ANTI_ICE_ENG2_ON: U502.9 (OUT4); also elsewhere on the board
LED_ANTI_ICE_WING_FAULT: U504.10 (OUT5); also elsewhere on the board
LED_ANTI_ICE_WING_ON: U502.7 (OUT2); also elsewhere on the board
LED_APU_AVAIL: U504.13 (OUT8); also elsewhere on the board
LED_APU_BLEED_FAULT: U504.18 (OUT13); also elsewhere on the board
LED_APU_BLEED_ON: U502.14 (OUT9); also elsewhere on the board
LED_APU_MASTER_FAULT: U504.12 (OUT7); also elsewhere on the board
LED_APU_MASTER_ON: U502.6 (OUT1); also elsewhere on the board
LED_APU_START_ON: U502.13 (OUT8); also elsewhere on the board
LED_ELEC_BATT_1_FAULT: U503.19 (OUT14); also elsewhere on the board
LED_ELEC_BATT_1_OFF: U501.20 (OUT15); also elsewhere on the board
LED_ELEC_BATT_2_FAULT: U503.18 (OUT13); also elsewhere on the board
LED_ELEC_BATT_2_OFF: U501.19 (OUT14); also elsewhere on the board
LED_EXT_PWR_AVAIL: U504.8 (OUT3); also elsewhere on the board
LED_EXT_PWR_ON: U502.10 (OUT5); also elsewhere on the board
LED_FLAPS3_OFF: U501.8 (OUT3); also elsewhere on the board
LED_GND_CTL_ON: U502.5 (OUT0); also elsewhere on the board
LED_GPWS_SYS_FAULT: U503.10 (OUT5); also elsewhere on the board
LED_GPWS_SYS_OFF: U501.6 (OUT1); also elsewhere on the board
LED_GPWS_TERR_FAULT: U503.9 (OUT4); also elsewhere on the board
LED_GPWS_TERR_OFF: U501.5 (OUT0); also elsewhere on the board
LED_GS_OFF: U501.7 (OUT2); also elsewhere on the board
LED_LT_TK_PUMP_1_FAULT: U503.17 (OUT12); also elsewhere on the board
LED_LT_TK_PUMP_1_OFF: U501.10 (OUT5); also elsewhere on the board
LED_LT_TK_PUMP_2_FAULT: U503.16 (OUT11); also elsewhere on the board
LED_LT_TK_PUMP_2_OFF: U501.11 (OUT6); also elsewhere on the board
LED_L_XFER_FAULT: U503.15 (OUT10); also elsewhere on the board
LED_L_XFER_OFF: U501.12 (OUT7); also elsewhere on the board
LED_OXY_CREW_SUPPLY_OFF: U501.9 (OUT4); also elsewhere on the board
LED_PACK1_FAULT: U504.19 (OUT14); also elsewhere on the board
LED_PACK1_OFF: U501.13 (OUT8); also elsewhere on the board
LED_PACK2_FAULT: U504.20 (OUT15); also elsewhere on the board
LED_PACK2_OFF: U501.17 (OUT12); also elsewhere on the board
LED_RT_TK_PUMP_1_FAULT: U503.13 (OUT8); also elsewhere on the board
LED_RT_TK_PUMP_1_OFF: U501.15 (OUT10); also elsewhere on the board
LED_RT_TK_PUMP_2_FAULT: U504.5 (OUT0); also elsewhere on the board
LED_RT_TK_PUMP_2_OFF: U501.14 (OUT9); also elsewhere on the board
LED_R_XFER_FAULT: U503.14 (OUT9); also elsewhere on the board
LED_R_XFER_OFF: U501.16 (OUT11); also elsewhere on the board
LED_XFEED_ON: U501.18 (OUT13); also elsewhere on the board
LED_XFEED_OPEN: U504.7 (OUT2); also elsewhere on the board
LWR_CLK: R512.1, R513.1; also elsewhere on the board
LWR_DATA2: U501.22 (SDO), U502.2 (SDI)
LWR_LE: R514.1, R515.1; also elsewhere on the board
LWR_SDI: R511.1; also elsewhere on the board
Q501_G: Q501.1 (G), Q502.1 (D), R521.2
Q502_G: Q502.2 (G), R522.2, R523.1
Q503_G: Q503.1 (G), Q504.1 (D), R524.2
Q504_G: Q504.2 (G), R525.2, R526.1
TLC_PWR_EN: R525.1; also elsewhere on the board
U501_CLK: R512.2, U501.3 (CLK)
U501_LE: R514.2, U501.4 (LE(ED1))
U501_REXT: R501.1, U501.23 (R-EXT)
U501_SDI: R511.2, U501.2 (SDI)
U502_CLK: R513.2, U502.3 (CLK)
U502_LE: R515.2, U502.4 (LE(ED1))
U502_REXT: R502.1, U502.23 (R-EXT)
U503_CLK: R517.2, U503.3 (CLK)
U503_LE: R519.2, U503.4 (LE(ED1))
U503_REXT: R503.1, U503.23 (R-EXT)
U503_SDI: R516.2, U503.2 (SDI)
U504_CLK: R518.2, U504.3 (CLK)
U504_LE: R520.2, U504.4 (LE(ED1))
U504_REXT: R504.1, U504.23 (R-EXT)
UPR_CLK: R517.1, R518.1; also elsewhere on the board
UPR_DATA2: U503.22 (SDO), U504.2 (SDI)
UPR_LE: R519.1, R520.1; also elsewhere on the board
UPR_SDI: R516.1; also elsewhere on the board

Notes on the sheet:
Series resistors on CLK / LE / SDI
Anode rail switch (D45) and TLC5927 supply switch (D46)
Bulk capacitors
Annunciator drivers: TI TLC5927IDWR, not DM13A (v1 schematic said DM13A). Chains as v1: ANN_LOWER D22/23/24 -> U501 white -> U502 blue; ANN_UPPER D25/26/27 -> U503 amber -> U504 green/amber. Outputs named after their LED, from the as-built copper. LED anodes on +5V_LED, cathodes to the outputs, thr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

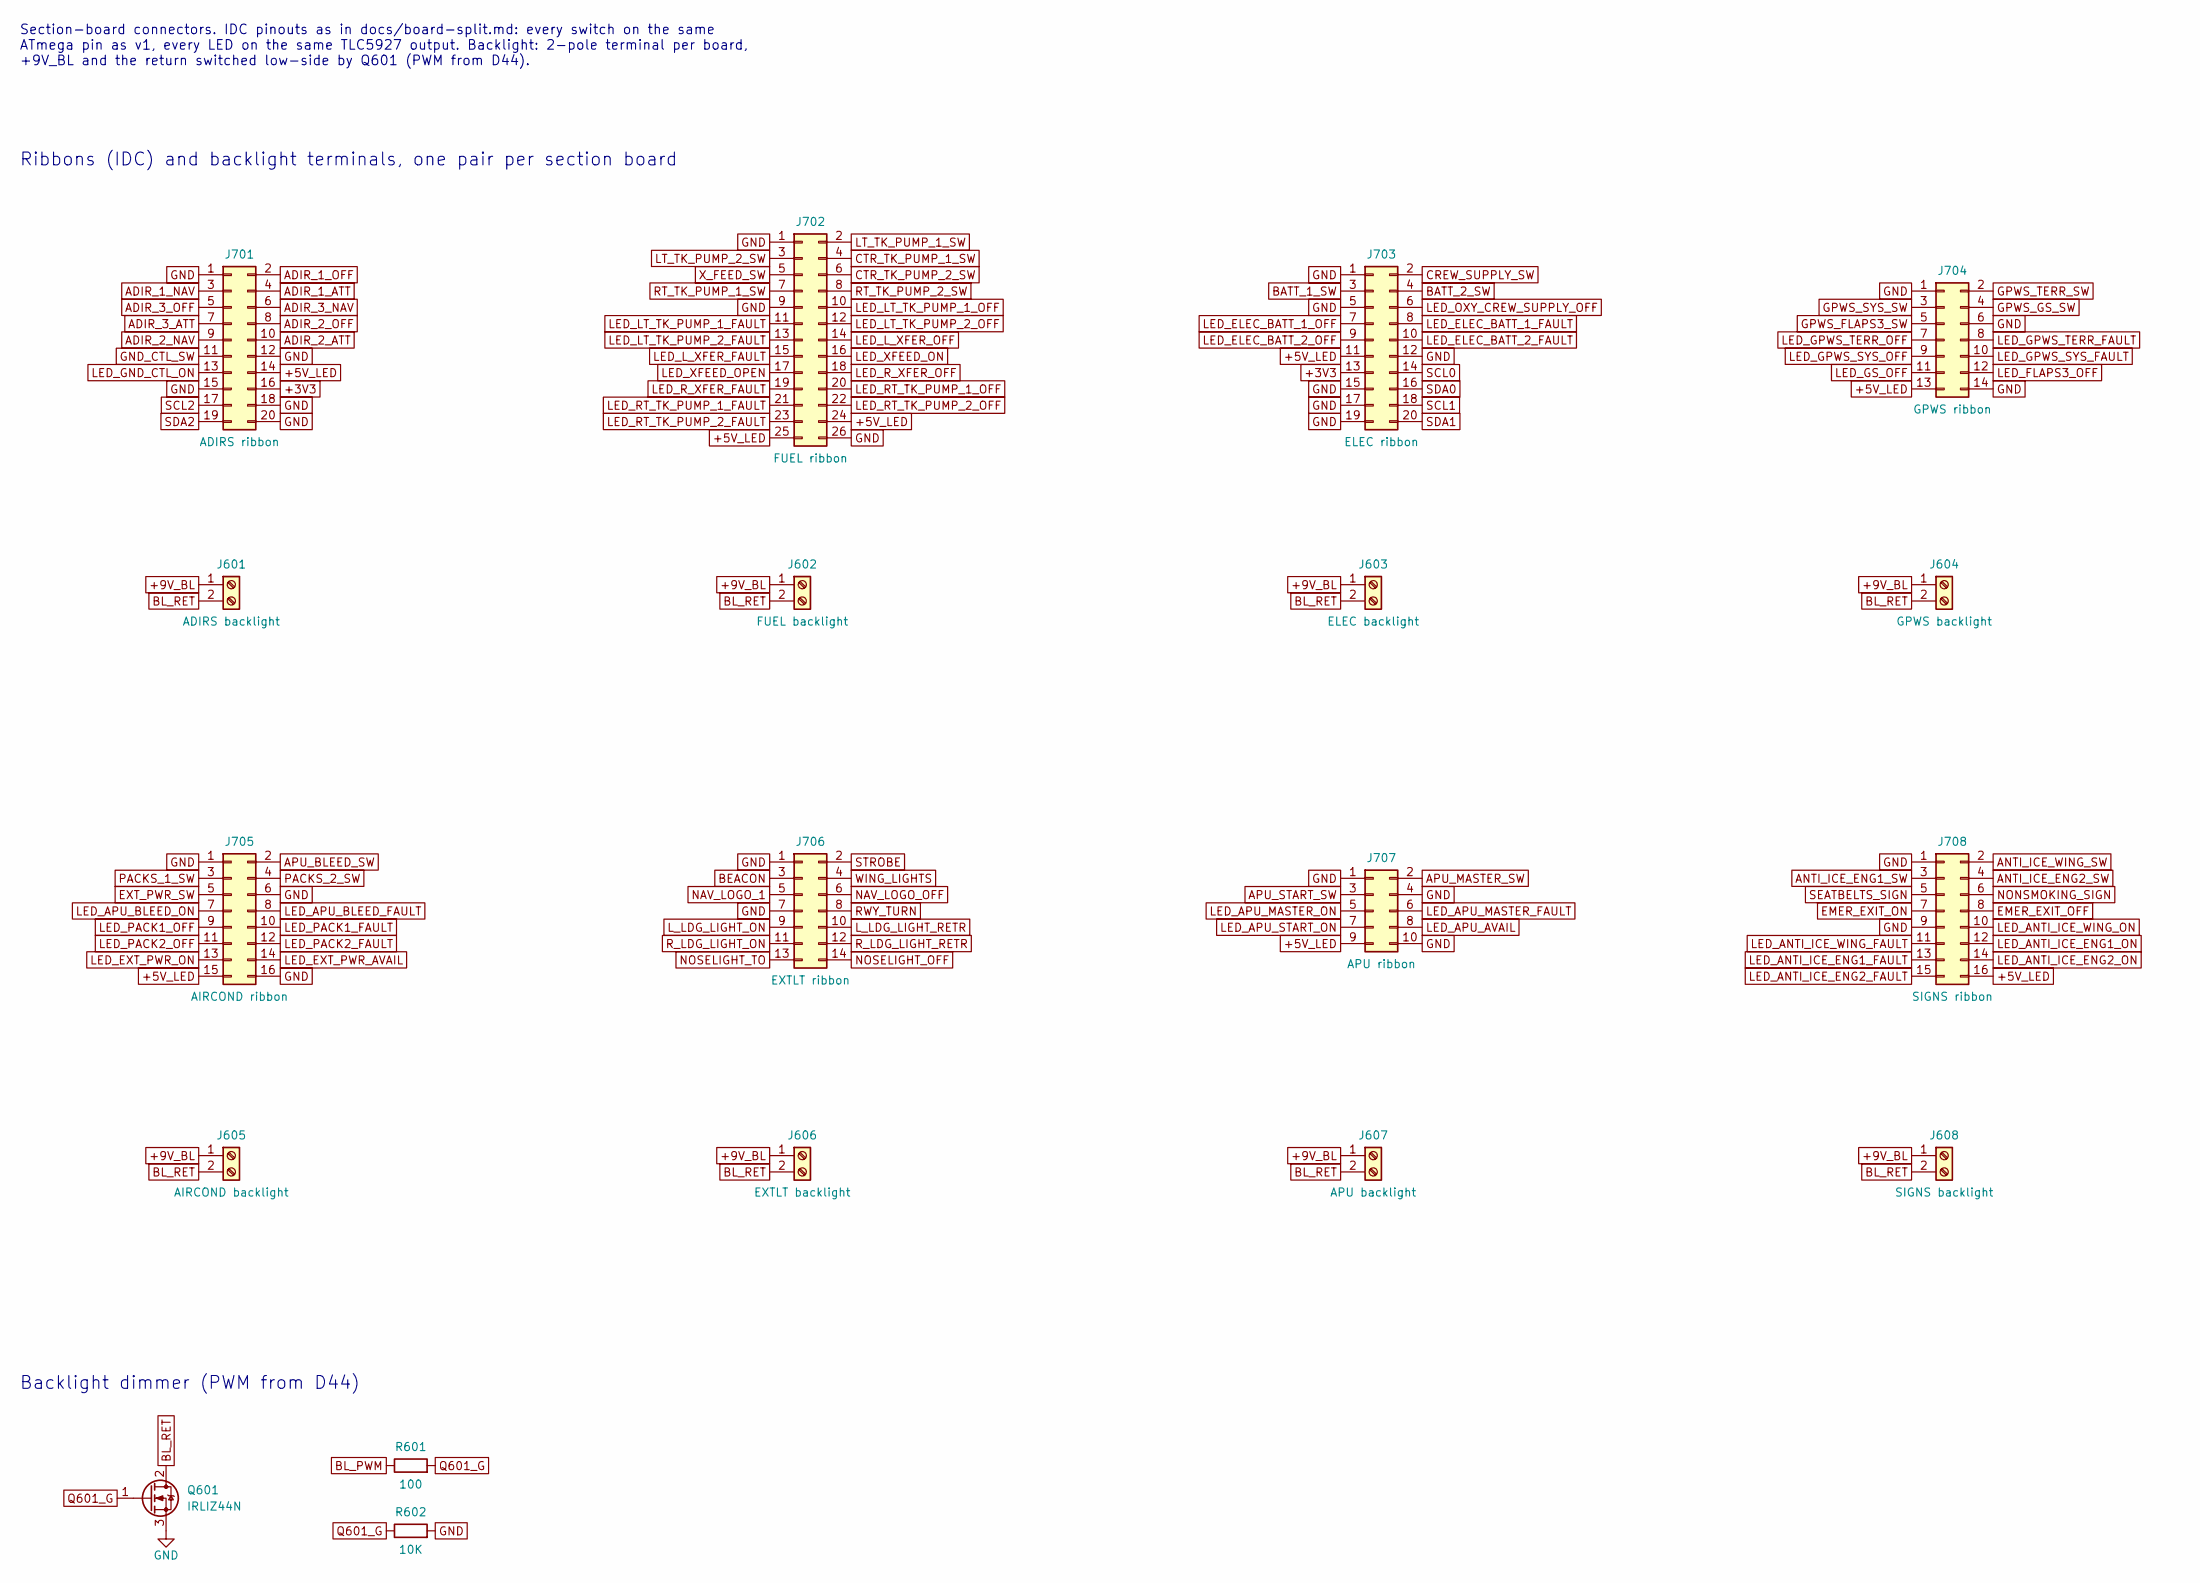
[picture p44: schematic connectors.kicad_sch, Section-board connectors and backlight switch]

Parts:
J601: ADIRS backlight; TerminalBlock_Phoenix_PT-1,5-2-3.5-H_1x02_P3.50mm_Horizontal
J602: FUEL backlight; TerminalBlock_Phoenix_PT-1,5-2-3.5-H_1x02_P3.50mm_Horizontal
J603: ELEC backlight; TerminalBlock_Phoenix_PT-1,5-2-3.5-H_1x02_P3.50mm_Horizontal
J604: GPWS backlight; TerminalBlock_Phoenix_PT-1,5-2-3.5-H_1x02_P3.50mm_Horizontal
J605: AIRCOND backlight; TerminalBlock_Phoenix_PT-1,5-2-3.5-H_1x02_P3.50mm_Horizontal
J606: EXTLT backlight; TerminalBlock_Phoenix_PT-1,5-2-3.5-H_1x02_P3.50mm_Horizontal
J607: APU backlight; TerminalBlock_Phoenix_PT-1,5-2-3.5-H_1x02_P3.50mm_Horizontal
J608: SIGNS backlight; TerminalBlock_Phoenix_PT-1,5-2-3.5-H_1x02_P3.50mm_Horizontal
J701: ADIRS ribbon; IDC-Header_2x10_P2.54mm_Vertical
J702: FUEL ribbon; IDC-Header_2x13_P2.54mm_Vertical
J703: ELEC ribbon; IDC-Header_2x10_P2.54mm_Vertical
J704: GPWS ribbon; IDC-Header_2x07_P2.54mm_Vertical
J705: AIRCOND ribbon; IDC-Header_2x08_P2.54mm_Vertical
J706: EXTLT ribbon; IDC-Header_2x07_P2.54mm_Vertical
J707: APU ribbon; IDC-Header_2x05_P2.54mm_Vertical
J708: SIGNS ribbon; IDC-Header_2x08_P2.54mm_Vertical
Q601: IRLIZ44N; TO-220F-3_Horizontal_TabDown
R601: 100; R_1206_3216Metric_Pad1.30x1.75mm_HandSolder
R602: 10K; R_1206_3216Metric_Pad1.30x1.75mm_HandSolder

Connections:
+3V3: J701.16, J703.13; also elsewhere on the board
+5V_LED: J701.14, J702.24, J702.25, J703.11, J704.13, J705.15, J707.9, J708.16; also elsewhere on the board
+9V_BL: J601.1, J602.1, J603.1, J604.1, J605.1, J606.1, J607.1, J608.1; also elsewhere on the board
ADIR_1_ATT: J701.4; also elsewhere on the board
ADIR_1_NAV: J701.3; also elsewhere on the board
ADIR_1_OFF: J701.2; also elsewhere on the board
ADIR_2_ATT: J701.10; also elsewhere on the board
ADIR_2_NAV: J701.9; also elsewhere on the board
ADIR_2_OFF: J701.8; also elsewhere on the board
ADIR_3_ATT: J701.7; also elsewhere on the board
ADIR_3_NAV: J701.6; also elsewhere on the board
ADIR_3_OFF: J701.5; also elsewhere on the board
ANTI_ICE_ENG1_SW: J708.3; also elsewhere on the board
ANTI_ICE_ENG2_SW: J708.4; also elsewhere on the board
ANTI_ICE_WING_SW: J708.2; also elsewhere on the board
APU_BLEED_SW: J705.2; also elsewhere on the board
APU_MASTER_SW: J707.2; also elsewhere on the board
APU_START_SW: J707.3; also elsewhere on the board
BATT_1_SW: J703.3; also elsewhere on the board
BATT_2_SW: J703.4; also elsewhere on the board
BEACON: J706.3; also elsewhere on the board
BL_PWM: R601.1; also elsewhere on the board
BL_RET: J601.2, J602.2, J603.2, J604.2, J605.2, J606.2, J607.2, J608.2, Q601.2 (D)
CREW_SUPPLY_SW: J703.2; also elsewhere on the board
CTR_TK_PUMP_1_SW: J702.4; also elsewhere on the board
CTR_TK_PUMP_2_SW: J702.6; also elsewhere on the board
EMER_EXIT_OFF: J708.8; also elsewhere on the board
EMER_EXIT_ON: J708.7; also elsewhere on the board
EXT_PWR_SW: J705.5; also elsewhere on the board
GND: J701.1, J701.12, J701.15, J701.18, J701.20, J702.1, J702.9, J702.26, J703.1, J703.5, J703.12, J703.15, J703.17, J703.19, J704.1, J704.6, J704.14, J705.1, J705.6, J705.16, J706.1, J706.7, J707.1, J707.4, J707.10, J708.1, J708.9, Q601.3 (S), R602.2; also elsewhere on the board
GND_CTL_SW: J701.11; also elsewhere on the board
GPWS_FLAPS3_SW: J704.5; also elsewhere on the board
GPWS_GS_SW: J704.4; also elsewhere on the board
GPWS_SYS_SW: J704.3; also elsewhere on the board
GPWS_TERR_SW: J704.2; also elsewhere on the board
LED_ANTI_ICE_ENG1_FAULT: J708.13; also elsewhere on the board
LED_ANTI_ICE_ENG1_ON: J708.12; also elsewhere on the board
LED_ANTI_ICE_ENG2_FAULT: J708.15; also elsewhere on the board
LED_ANTI_ICE_ENG2_ON: J708.14; also elsewhere on the board
LED_ANTI_ICE_WING_FAULT: J708.11; also elsewhere on the board
LED_ANTI_ICE_WING_ON: J708.10; also elsewhere on the board
LED_APU_AVAIL: J707.8; also elsewhere on the board
LED_APU_BLEED_FAULT: J705.8; also elsewhere on the board
LED_APU_BLEED_ON: J705.7; also elsewhere on the board
LED_APU_MASTER_FAULT: J707.6; also elsewhere on the board
LED_APU_MASTER_ON: J707.5; also elsewhere on the board
LED_APU_START_ON: J707.7; also elsewhere on the board
LED_ELEC_BATT_1_FAULT: J703.8; also elsewhere on the board
LED_ELEC_BATT_1_OFF: J703.7; also elsewhere on the board
LED_ELEC_BATT_2_FAULT: J703.10; also elsewhere on the board
LED_ELEC_BATT_2_OFF: J703.9; also elsewhere on the board
LED_EXT_PWR_AVAIL: J705.14; also elsewhere on the board
LED_EXT_PWR_ON: J705.13; also elsewhere on the board
LED_FLAPS3_OFF: J704.12; also elsewhere on the board
LED_GND_CTL_ON: J701.13; also elsewhere on the board
LED_GPWS_SYS_FAULT: J704.10; also elsewhere on the board
LED_GPWS_SYS_OFF: J704.9; also elsewhere on the board
LED_GPWS_TERR_FAULT: J704.8; also elsewhere on the board
LED_GPWS_TERR_OFF: J704.7; also elsewhere on the board
LED_GS_OFF: J704.11; also elsewhere on the board
LED_LT_TK_PUMP_1_FAULT: J702.11; also elsewhere on the board
LED_LT_TK_PUMP_1_OFF: J702.10; also elsewhere on the board
LED_LT_TK_PUMP_2_FAULT: J702.13; also elsewhere on the board
LED_LT_TK_PUMP_2_OFF: J702.12; also elsewhere on the board
LED_L_XFER_FAULT: J702.15; also elsewhere on the board
LED_L_XFER_OFF: J702.14; also elsewhere on the board
LED_OXY_CREW_SUPPLY_OFF: J703.6; also elsewhere on the board
LED_PACK1_FAULT: J705.10; also elsewhere on the board
LED_PACK1_OFF: J705.9; also elsewhere on the board
LED_PACK2_FAULT: J705.12; also elsewhere on the board
LED_PACK2_OFF: J705.11; also elsewhere on the board
LED_RT_TK_PUMP_1_FAULT: J702.21; also elsewhere on the board
LED_RT_TK_PUMP_1_OFF: J702.20; also elsewhere on the board
LED_RT_TK_PUMP_2_FAULT: J702.23; also elsewhere on the board
LED_RT_TK_PUMP_2_OFF: J702.22; also elsewhere on the board
LED_R_XFER_FAULT: J702.19; also elsewhere on the board
LED_R_XFER_OFF: J702.18; also elsewhere on the board
LED_XFEED_ON: J702.16; also elsewhere on the board
LED_XFEED_OPEN: J702.17; also elsewhere on the board
LT_TK_PUMP_1_SW: J702.2; also elsewhere on the board
LT_TK_PUMP_2_SW: J702.3; also elsewhere on the board
L_LDG_LIGHT_ON: J706.9; also elsewhere on the board
L_LDG_LIGHT_RETR: J706.10; also elsewhere on the board
NAV_LOGO_1: J706.5; also elsewhere on the board
NAV_LOGO_OFF: J706.6; also elsewhere on the board
NONSMOKING_SIGN: J708.6; also elsewhere on the board
NOSELIGHT_OFF: J706.14; also elsewhere on the board
NOSELIGHT_TO: J706.13; also elsewhere on the board
PACKS_1_SW: J705.3; also elsewhere on the board
PACKS_2_SW: J705.4; also elsewhere on the board
Q601_G: Q601.1 (G), R601.2, R602.1
RT_TK_PUMP_1_SW: J702.7; also elsewhere on the board
RT_TK_PUMP_2_SW: J702.8; also elsewhere on the board
RWY_TURN: J706.8; also elsewhere on the board
R_LDG_LIGHT_ON: J706.11; also elsewhere on the board
R_LDG_LIGHT_RETR: J706.12; also elsewhere on the board
SCL0: J703.14; also elsewhere on the board
SCL1: J703.18; also elsewhere on the board
SCL2: J701.17; also elsewhere on the board
SDA0: J703.16; also elsewhere on the board
SDA1: J703.20; also elsewhere on the board
SDA2: J701.19; also elsewhere on the board
SEATBELTS_SIGN: J708.5; also elsewhere on the board
STROBE: J706.2; also elsewhere on the board
WING_LIGHTS: J706.4; also elsewhere on the board
X_FEED_SW: J702.5; also elsewhere on the board

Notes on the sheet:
Ribbons (IDC) and backlight terminals, one pair per section board
Section-board connectors. IDC pinouts as in docs/board-split.md: every switch on the same ATmega pin as v1, every LED on the same TLC5927 output. Backlight: 2-pole terminal per board, +9V_BL and the return switched low-side by Q601 (PWM from D44).
Backlight dimmer (PWM from D44)

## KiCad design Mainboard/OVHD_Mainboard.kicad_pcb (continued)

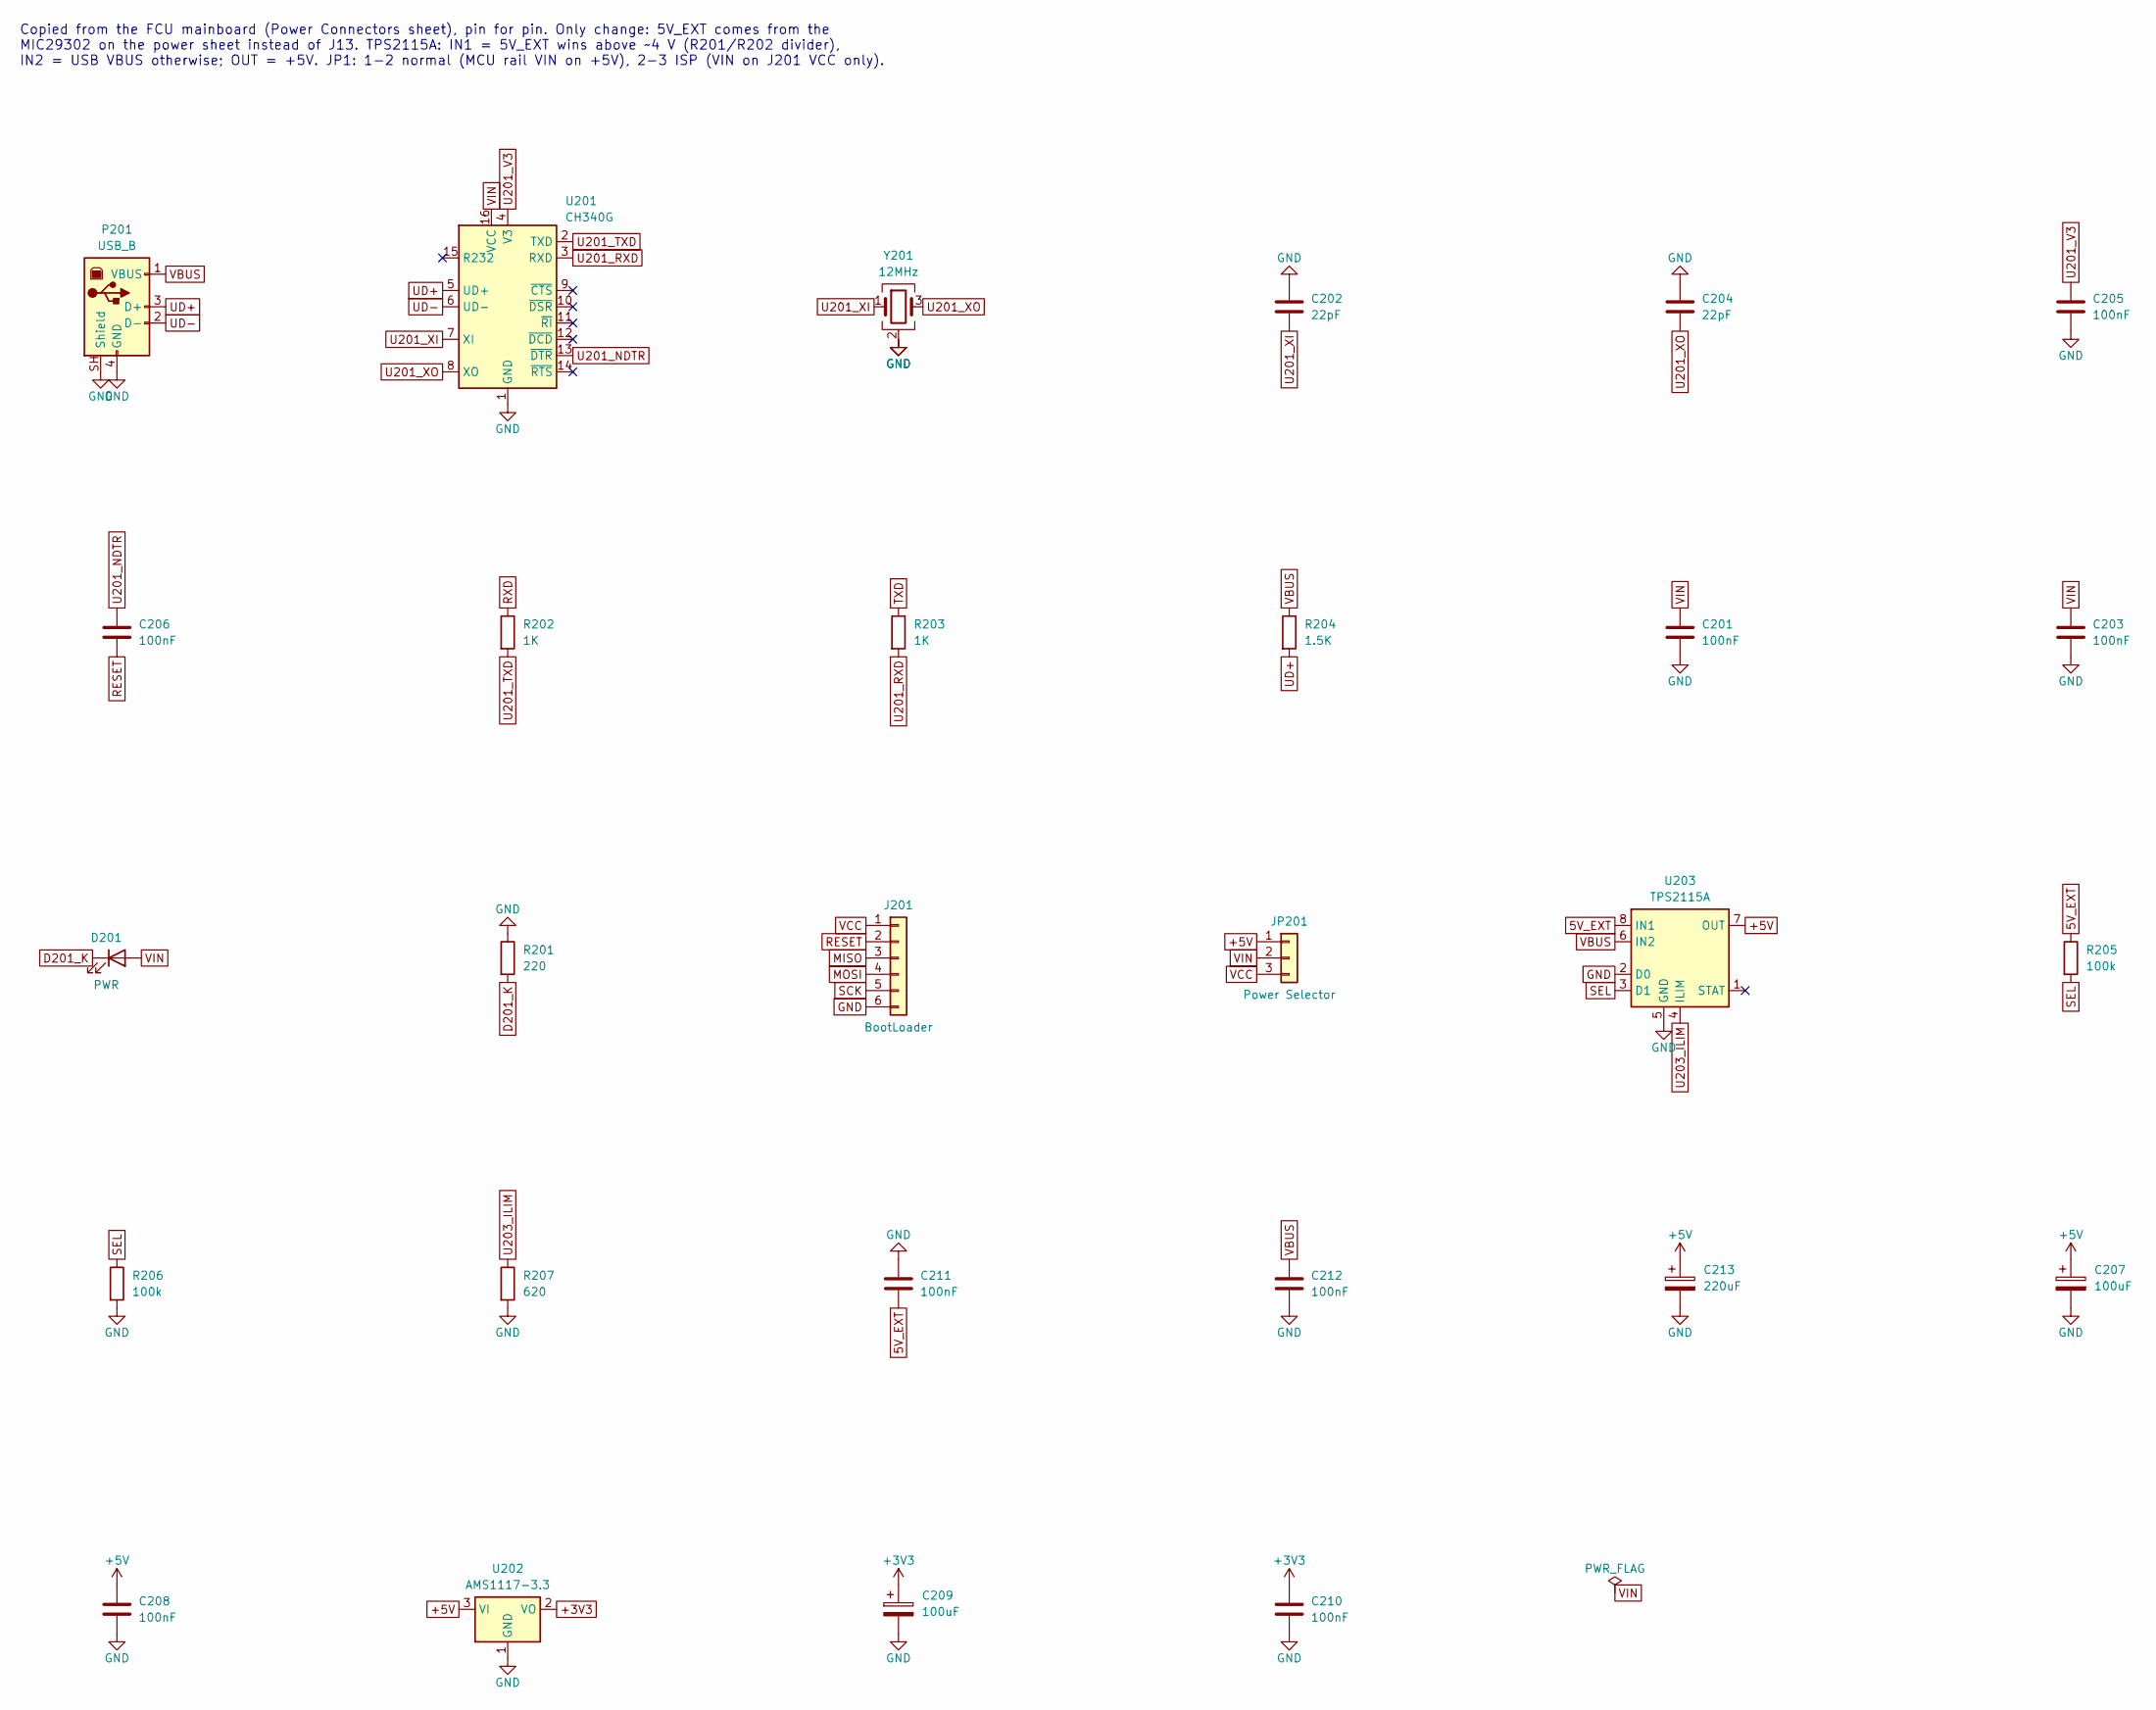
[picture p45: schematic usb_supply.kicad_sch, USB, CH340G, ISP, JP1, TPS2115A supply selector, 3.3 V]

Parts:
C201, C203, C205, C206, C208, C210, C211, C212: 100nF; C_1206_3216Metric_Pad1.33x1.80mm_HandSolder
C202, C204: 22pF; C_1206_3216Metric_Pad1.33x1.80mm_HandSolder
C207, C209: 100uF; C_Elec_6.3x7.7
C213: 220uF; C_Elec_6.3x7.7
D201: PWR; LED_1206_3216Metric_Pad1.42x1.75mm_HandSolder
J201: BootLoader; PinHeader_1x06_P2.54mm_Vertical
JP201: Power Selector; PinHeader_1x03_P2.54mm_Vertical
P201: USB_B; USB_B_OST_USB-B1HSxx_Horizontal
R201: 220; R_1206_3216Metric_Pad1.30x1.75mm_HandSolder
R202, R203: 1K; R_1206_3216Metric_Pad1.30x1.75mm_HandSolder
R204: 1.5K; R_1206_3216Metric_Pad1.30x1.75mm_HandSolder
R205, R206: 100k; R_1206_3216Metric_Pad1.30x1.75mm_HandSolder
R207: 620; R_1206_3216Metric_Pad1.30x1.75mm_HandSolder
U201: CH340G; SOIC-16_3.9x9.9mm_P1.27mm
U202: AMS1117-3.3; SOT-223-3_TabPin2
U203: TPS2115A; TSSOP-8_4.4x3mm_P0.65mm
Y201: 12MHz; Crystal_SMD_EuroQuartz_MQ-4Pin_7.0x5.0mm_HandSoldering

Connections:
5V_EXT: C211.2, R205.1, U203.8 (IN1); also elsewhere on the board
+3V3: C209.1, C210.1, U202.2 (VO); also elsewhere on the board
+5V: C207.1, C208.1, C213.1, JP201.1, U202.3 (VI), U203.7 (OUT); also elsewhere on the board
D201_K: D201.1 (K), R201.2
GND: C201.2, C202.1, C203.2, C204.1, C205.2, C207.2, C208.2, C209.2, C210.2, C211.1, C212.2, C213.2, J201.6, P201.4 (GND), P201.SH (Shield), R201.1, R206.2, R207.2, U201.1 (GND), U202.1 (GND), U203.2 (D0), U203.5 (GND), Y201.2 (G), Y201.4 (G); also elsewhere on the board
MISO: J201.3; also elsewhere on the board
MOSI: J201.4; also elsewhere on the board
RESET: C206.2, J201.2; also elsewhere on the board
RXD: R202.1; also elsewhere on the board
SCK: J201.5; also elsewhere on the board
SEL: R205.2, R206.1, U203.3 (D1)
TXD: R203.1; also elsewhere on the board
U201_NDTR: C206.1, U201.13 (~DTR)
U201_RXD: R203.2, U201.3 (RXD)
U201_TXD: R202.2, U201.2 (TXD)
U201_V3: C205.1, U201.4 (V3)
U201_XI: C202.2, U201.7 (XI), Y201.1
U201_XO: C204.2, U201.8 (XO), Y201.3
U203_ILIM: R207.1, U203.4 (ILIM)
UD+: P201.3 (D+), R204.2, U201.5 (UD+)
UD-: P201.2 (D-), U201.6 (UD-)
VBUS: C212.1, P201.1 (VBUS), R204.1, U203.6 (IN2)
VCC: J201.1, JP201.3
VIN: C201.1, C203.1, D201.2 (A), JP201.2, U201.16 (VCC); also elsewhere on the board

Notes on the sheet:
Copied from the FCU mainboard (Power Connectors sheet), pin for pin. Only change: 5V_EXT comes from the MIC29302 on the power sheet instead of J13. TPS2115A: IN1 = 5V_EXT wins above ~4 V (R201/R202 divider), IN2 = USB VBUS otherwise; OUT = +5V. JP1: 1-2 normal (MCU rail VIN on +5V), 2-3 ISP (VIN on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

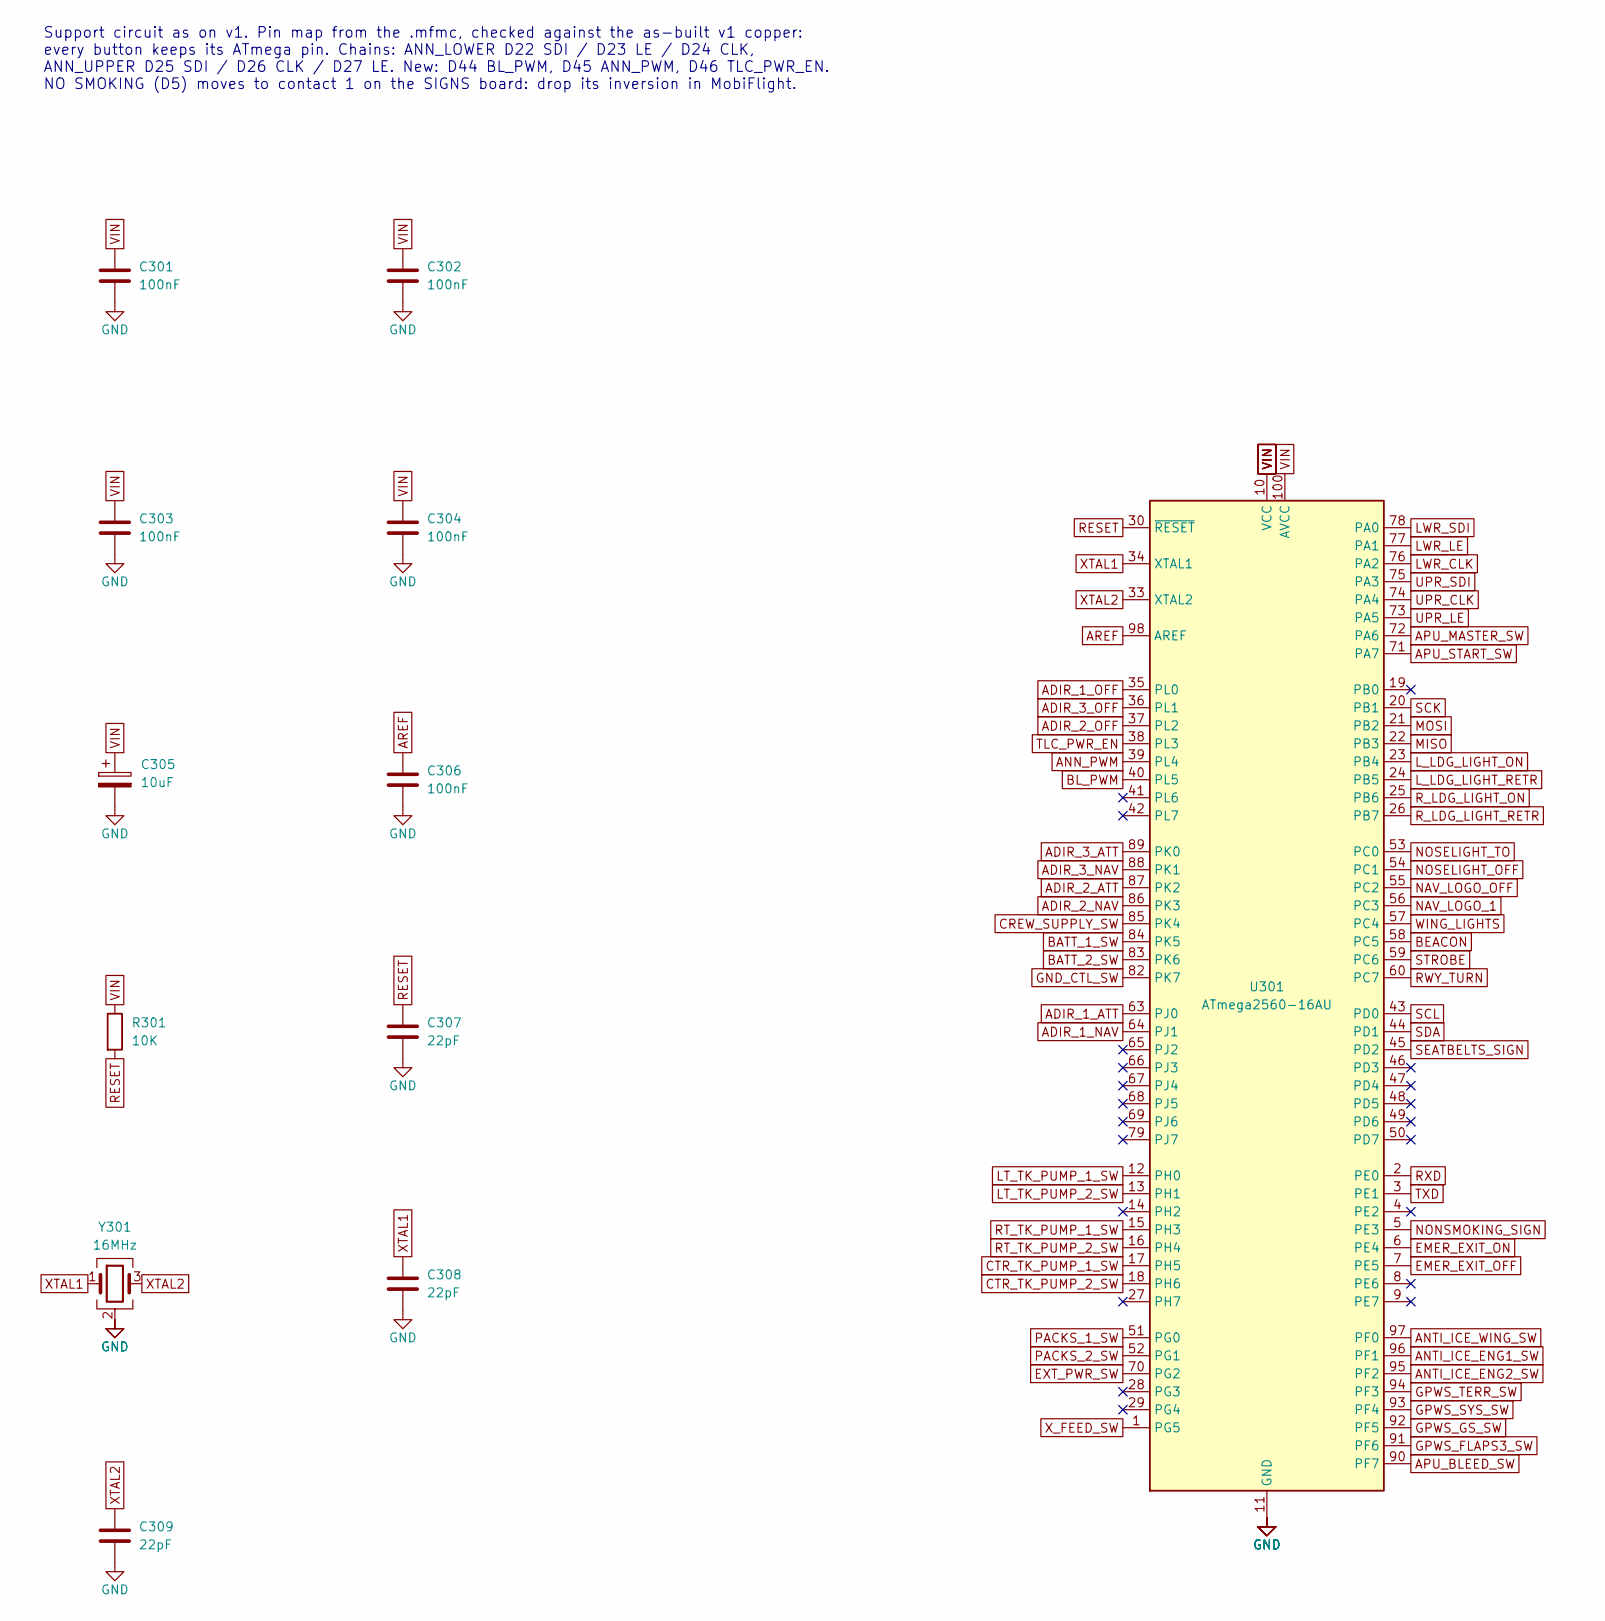
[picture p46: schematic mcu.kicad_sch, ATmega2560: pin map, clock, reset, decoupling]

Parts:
C301, C302, C303, C304, C306: 100nF; C_1206_3216Metric_Pad1.33x1.80mm_HandSolder
C305: 10uF; CP_Elec_4x5.4
C307, C308, C309: 22pF; C_1206_3216Metric_Pad1.33x1.80mm_HandSolder
R301: 10K; R_1206_3216Metric_Pad1.30x1.75mm_HandSolder
U301: ATmega2560-16AU; TQFP-100_14x14mm_P0.5mm
Y301: 16MHz; Crystal_SMD_EuroQuartz_MQ-4Pin_7.0x5.0mm_HandSoldering

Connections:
ADIR_1_ATT: U301.63 (PJ0); also elsewhere on the board
ADIR_1_NAV: U301.64 (PJ1); also elsewhere on the board
ADIR_1_OFF: U301.35 (PL0); also elsewhere on the board
ADIR_2_ATT: U301.87 (PK2); also elsewhere on the board
ADIR_2_NAV: U301.86 (PK3); also elsewhere on the board
ADIR_2_OFF: U301.37 (PL2); also elsewhere on the board
ADIR_3_ATT: U301.89 (PK0); also elsewhere on the board
ADIR_3_NAV: U301.88 (PK1); also elsewhere on the board
ADIR_3_OFF: U301.36 (PL1); also elsewhere on the board
ANN_PWM: U301.39 (PL4); also elsewhere on the board
ANTI_ICE_ENG1_SW: U301.96 (PF1); also elsewhere on the board
ANTI_ICE_ENG2_SW: U301.95 (PF2); also elsewhere on the board
ANTI_ICE_WING_SW: U301.97 (PF0); also elsewhere on the board
APU_BLEED_SW: U301.90 (PF7); also elsewhere on the board
APU_MASTER_SW: U301.72 (PA6); also elsewhere on the board
APU_START_SW: U301.71 (PA7); also elsewhere on the board
AREF: C306.1, U301.98 (AREF)
BATT_1_SW: U301.84 (PK5); also elsewhere on the board
BATT_2_SW: U301.83 (PK6); also elsewhere on the board
BEACON: U301.58 (PC5); also elsewhere on the board
BL_PWM: U301.40 (PL5); also elsewhere on the board
CREW_SUPPLY_SW: U301.85 (PK4); also elsewhere on the board
CTR_TK_PUMP_1_SW: U301.17 (PH5); also elsewhere on the board
CTR_TK_PUMP_2_SW: U301.18 (PH6); also elsewhere on the board
EMER_EXIT_OFF: U301.7 (PE5); also elsewhere on the board
EMER_EXIT_ON: U301.6 (PE4); also elsewhere on the board
EXT_PWR_SW: U301.70 (PG2); also elsewhere on the board
GND: C301.2, C302.2, C303.2, C304.2, C305.2, C306.2, C307.2, C308.2, C309.2, U301.11 (GND), U301.32 (GND), U301.62 (GND), U301.81 (GND), U301.99 (GND), Y301.2 (G), Y301.4 (G); also elsewhere on the board
GND_CTL_SW: U301.82 (PK7); also elsewhere on the board
GPWS_FLAPS3_SW: U301.91 (PF6); also elsewhere on the board
GPWS_GS_SW: U301.92 (PF5); also elsewhere on the board
GPWS_SYS_SW: U301.93 (PF4); also elsewhere on the board
GPWS_TERR_SW: U301.94 (PF3); also elsewhere on the board
LT_TK_PUMP_1_SW: U301.12 (PH0); also elsewhere on the board
LT_TK_PUMP_2_SW: U301.13 (PH1); also elsewhere on the board
LWR_CLK: U301.76 (PA2); also elsewhere on the board
LWR_LE: U301.77 (PA1); also elsewhere on the board
LWR_SDI: U301.78 (PA0); also elsewhere on the board
L_LDG_LIGHT_ON: U301.23 (PB4); also elsewhere on the board
L_LDG_LIGHT_RETR: U301.24 (PB5); also elsewhere on the board
MISO: U301.22 (PB3); also elsewhere on the board
MOSI: U301.21 (PB2); also elsewhere on the board
NAV_LOGO_1: U301.56 (PC3); also elsewhere on the board
NAV_LOGO_OFF: U301.55 (PC2); also elsewhere on the board
NONSMOKING_SIGN: U301.5 (PE3); also elsewhere on the board
NOSELIGHT_OFF: U301.54 (PC1); also elsewhere on the board
NOSELIGHT_TO: U301.53 (PC0); also elsewhere on the board
PACKS_1_SW: U301.51 (PG0); also elsewhere on the board
PACKS_2_SW: U301.52 (PG1); also elsewhere on the board
RESET: C307.1, R301.2, U301.30 (~RESET); also elsewhere on the board
RT_TK_PUMP_1_SW: U301.15 (PH3); also elsewhere on the board
RT_TK_PUMP_2_SW: U301.16 (PH4); also elsewhere on the board
RWY_TURN: U301.60 (PC7); also elsewhere on the board
RXD: U301.2 (PE0); also elsewhere on the board
R_LDG_LIGHT_ON: U301.25 (PB6); also elsewhere on the board
R_LDG_LIGHT_RETR: U301.26 (PB7); also elsewhere on the board
SCK: U301.20 (PB1); also elsewhere on the board
SCL: U301.43 (PD0); also elsewhere on the board
SDA: U301.44 (PD1); also elsewhere on the board
SEATBELTS_SIGN: U301.45 (PD2); also elsewhere on the board
STROBE: U301.59 (PC6); also elsewhere on the board
TLC_PWR_EN: U301.38 (PL3); also elsewhere on the board
TXD: U301.3 (PE1); also elsewhere on the board
UPR_CLK: U301.74 (PA4); also elsewhere on the board
UPR_LE: U301.73 (PA5); also elsewhere on the board
UPR_SDI: U301.75 (PA3); also elsewhere on the board
VIN: C301.1, C302.1, C303.1, C304.1, C305.1, R301.1, U301.10 (VCC), U301.31 (VCC), U301.61 (VCC), U301.80 (VCC), U301.100 (AVCC); also elsewhere on the board
WING_LIGHTS: U301.57 (PC4); also elsewhere on the board
XTAL1: C308.1, U301.34 (XTAL1), Y301.1
XTAL2: C309.1, U301.33 (XTAL2), Y301.3
X_FEED_SW: U301.1 (PG5); also elsewhere on the board

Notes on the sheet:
Support circuit as on v1. Pin map from the .mfmc, checked against the as-built v1 copper: every button keeps its ATmega pin. Chains: ANN_LOWER D22 SDI / D23 LE / D24 CLK, ANN_UPPER D25 SDI / D26 CLK / D27 LE. New: D44 BL_PWM, D45 ANN_PWM, D46 TLC_PWR_EN. NO SMOKING (D5) moves to contact 1 on the SI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

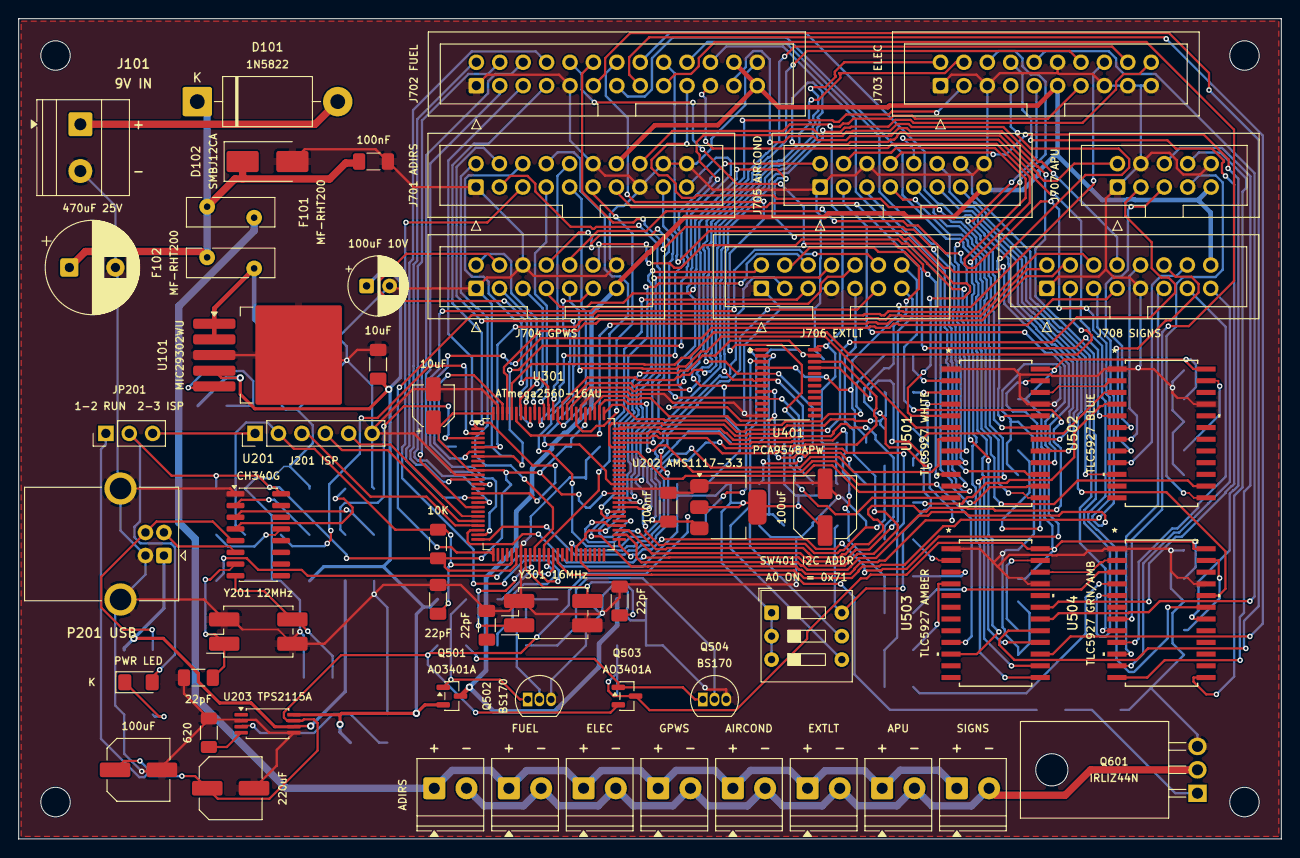
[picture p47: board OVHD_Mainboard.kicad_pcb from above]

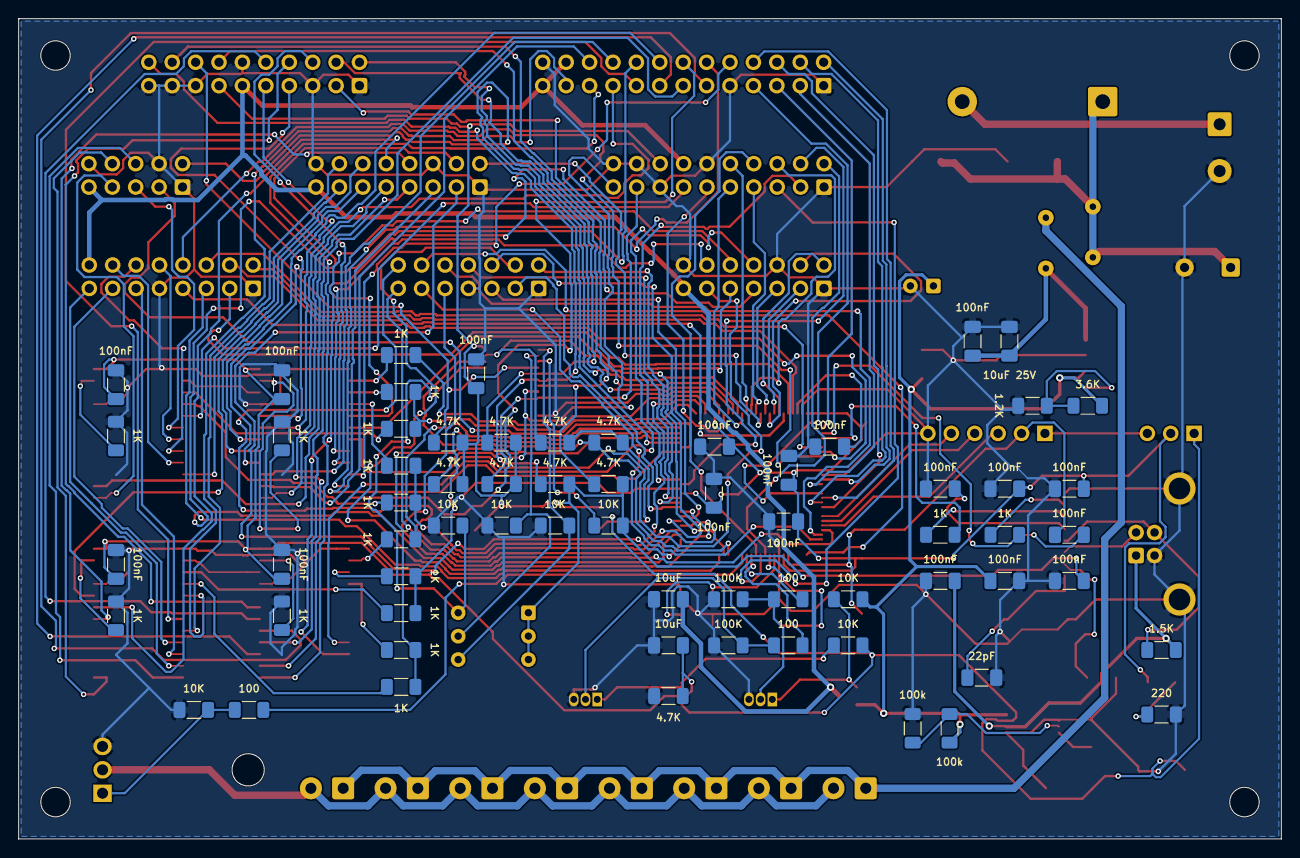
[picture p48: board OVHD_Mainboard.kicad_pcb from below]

Board: 2 copper layers, 137.0 x 89.0 mm, 127 parts (65 on the bottom side), 170 nets.

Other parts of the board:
H1, H2, H3, H4: MountingHole_3.2mm_M3

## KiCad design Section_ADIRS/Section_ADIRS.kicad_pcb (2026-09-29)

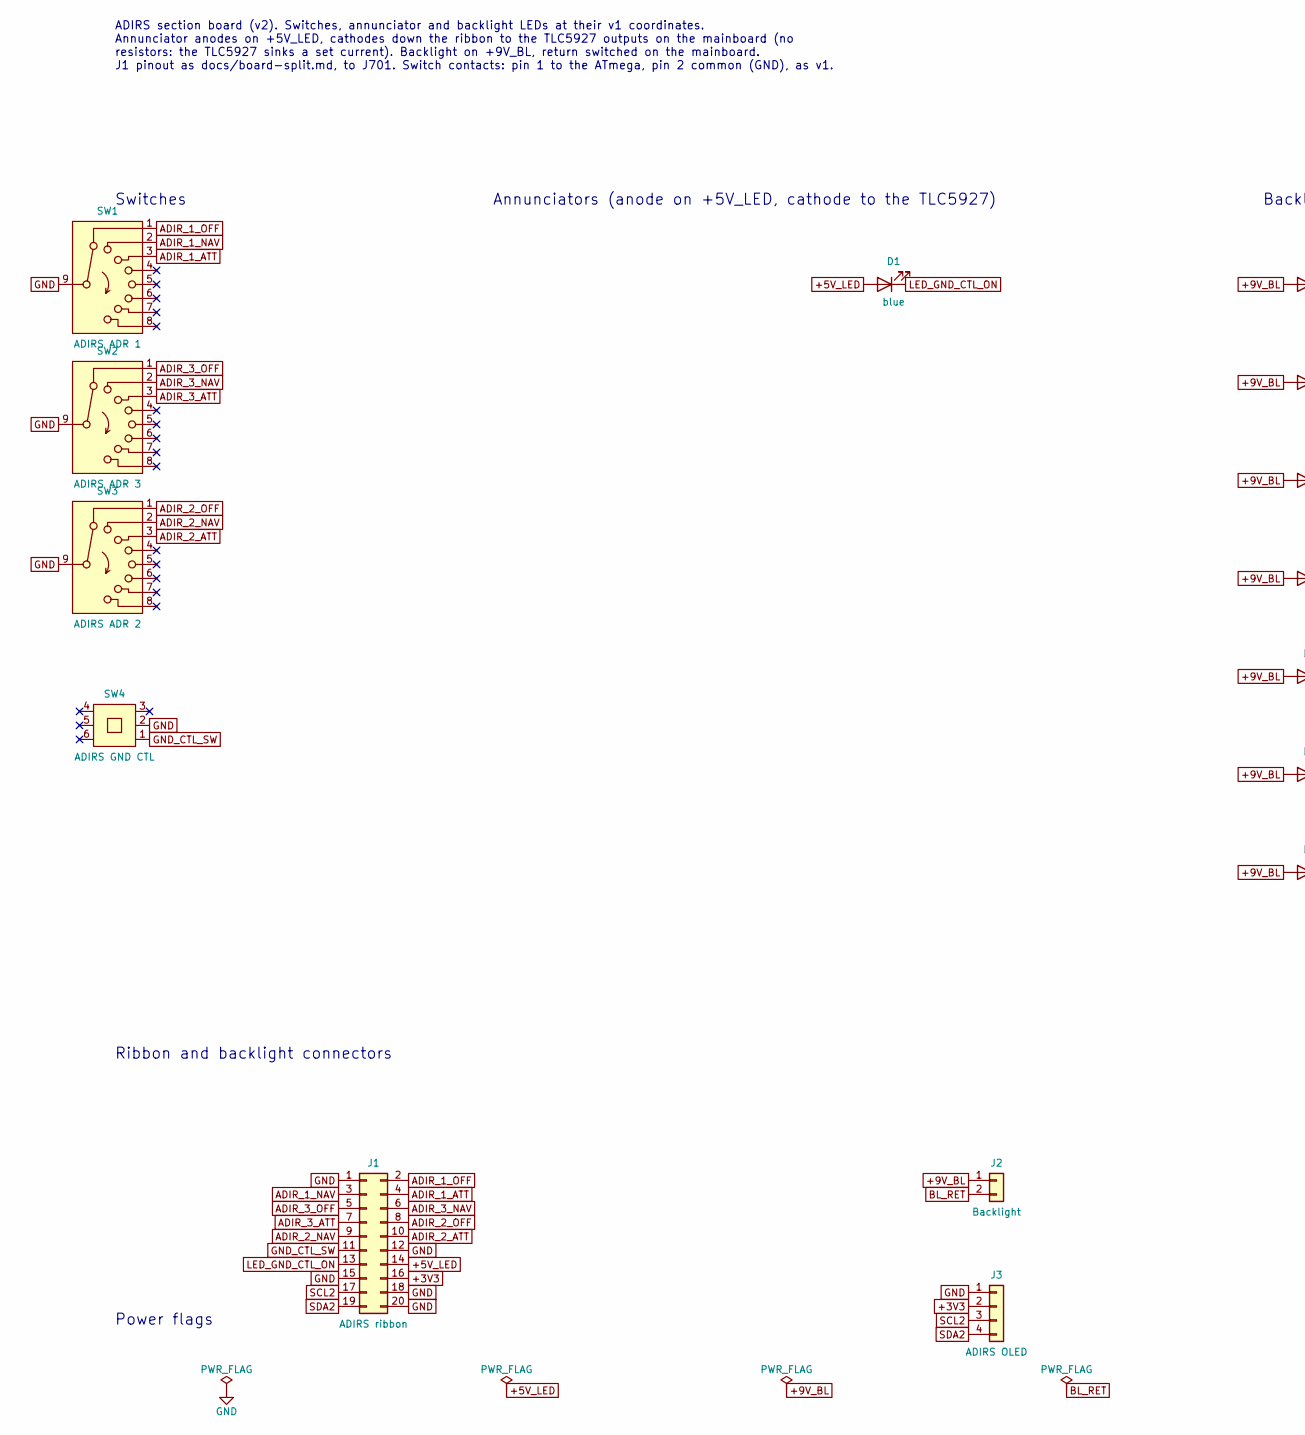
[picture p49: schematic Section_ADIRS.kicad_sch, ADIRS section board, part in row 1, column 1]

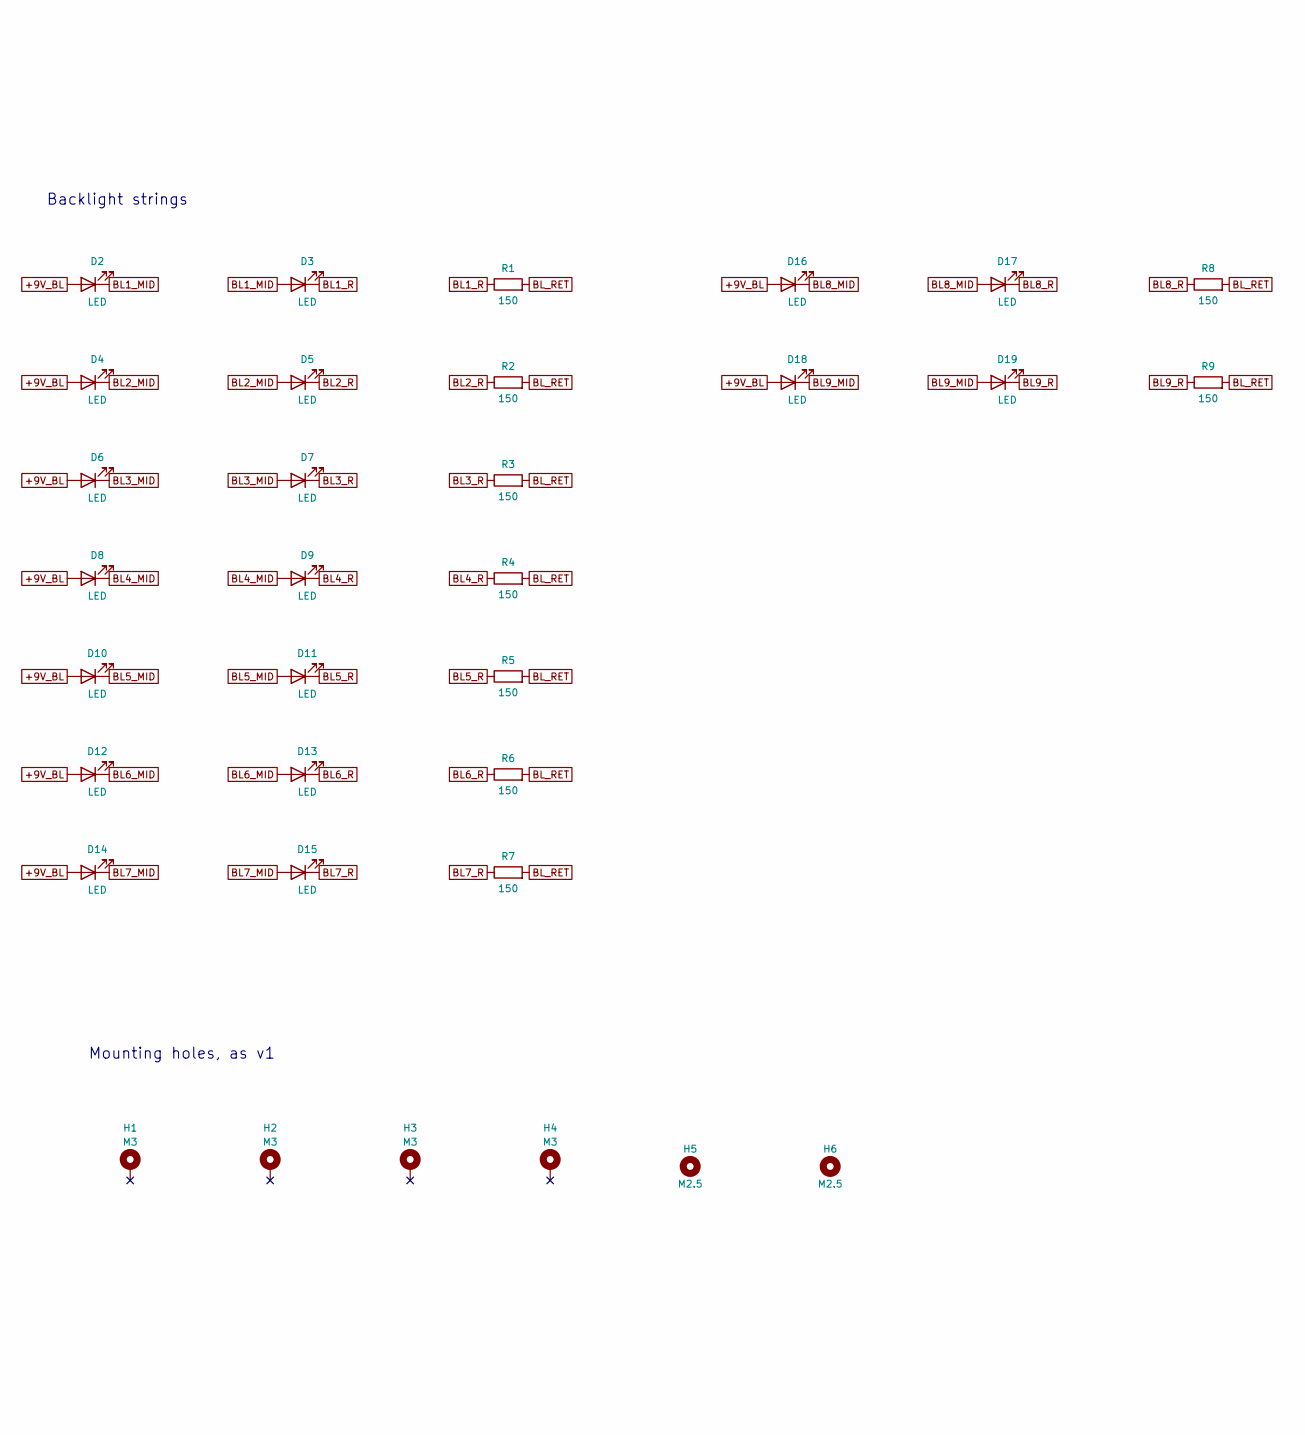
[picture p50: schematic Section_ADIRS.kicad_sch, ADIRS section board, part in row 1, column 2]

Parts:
D1: blue; LED_Rectangular_W3.9mm_H1.8mm_FlatTop
D2, D3, D4, D5, D6, D7, D8, D9, D10, D11, D12, D13, D14, D15, D16, D17, D18, D19: LED; LED_1206_3216Metric_Pad1.42x1.75mm_HandSolder
H1, H2, H3, H4: M3; MountingHole_3.2mm_M3_DIN965_Pad_TopBottom
H5, H6: M2.5; MountingHole_2.7mm_M2.5
J1: ADIRS ribbon; IDC-Header_2x10_P2.54mm_Vertical_SMD
J2: Backlight; JST_PH_B2B-PH-SM4-TB_1x02-1MP_P2.00mm_Vertical
J3: ADIRS OLED; PinSocket_1x04_P2.54mm_Vertical
R1, R2, R3, R4, R5, R6, R7, R8, R9: 150; R_1206_3216Metric_Pad1.30x1.75mm_HandSolder
SW1: ADIRS ADR 1; Rotary_SW_8x1_SF
SW2: ADIRS ADR 3; Rotary_SW_8x1_SF
SW3: ADIRS ADR 2; Rotary_SW_8x1_SF
SW4: ADIRS GND CTL; G-Switch_PS-7054DVB-6PN

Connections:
+3V3: J1.16, J3.2
+5V_LED: D1.2 (A), J1.14
+9V_BL: D2.2 (A), D4.2 (A), D6.2 (A), D8.2 (A), D10.2 (A), D12.2 (A), D14.2 (A), D16.2 (A), D18.2 (A), J2.1
ADIR_1_ATT: J1.4, SW1.3
ADIR_1_NAV: J1.3, SW1.2
ADIR_1_OFF: J1.2, SW1.1
ADIR_2_ATT: J1.10, SW3.3
ADIR_2_NAV: J1.9, SW3.2
ADIR_2_OFF: J1.8, SW3.1
ADIR_3_ATT: J1.7, SW2.3
ADIR_3_NAV: J1.6, SW2.2
ADIR_3_OFF: J1.5, SW2.1
BL1_MID: D2.1 (K), D3.2 (A)
BL1_R: D3.1 (K), R1.1
BL2_MID: D4.1 (K), D5.2 (A)
BL2_R: D5.1 (K), R2.1
BL3_MID: D6.1 (K), D7.2 (A)
BL3_R: D7.1 (K), R3.1
BL4_MID: D8.1 (K), D9.2 (A)
BL4_R: D9.1 (K), R4.1
BL5_MID: D10.1 (K), D11.2 (A)
BL5_R: D11.1 (K), R5.1
BL6_MID: D12.1 (K), D13.2 (A)
BL6_R: D13.1 (K), R6.1
BL7_MID: D14.1 (K), D15.2 (A)
BL7_R: D15.1 (K), R7.1
BL8_MID: D16.1 (K), D17.2 (A)
BL8_R: D17.1 (K), R8.1
BL9_MID: D18.1 (K), D19.2 (A)
BL9_R: D19.1 (K), R9.1
BL_RET: J2.2, R1.2, R2.2, R3.2, R4.2, R5.2, R6.2, R7.2, R8.2, R9.2
GND: J1.1, J1.12, J1.15, J1.18, J1.20, J3.1, SW1.9, SW2.9, SW3.9, SW4.2
GND_CTL_SW: J1.11, SW4.1
LED_GND_CTL_ON: D1.1 (K), J1.13
SCL2: J1.17, J3.3
SDA2: J1.19, J3.4

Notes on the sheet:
Ribbon and backlight connectors
Switches
Backlight strings
ADIRS section board (v2). Switches, annunciator and backlight LEDs at their v1 coordinates. Annunciator anodes on +5V_LED, cathodes down the ribbon to the TLC5927 outputs on the mainboard (no resistors: the TLC5927 sinks a set current). Backlight on +9V_BL, return switched on the mainboard. J1 pino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
Annunciators (anode on +5V_LED, cathode to the TLC5927)
Power flags
Mounting holes, as v1

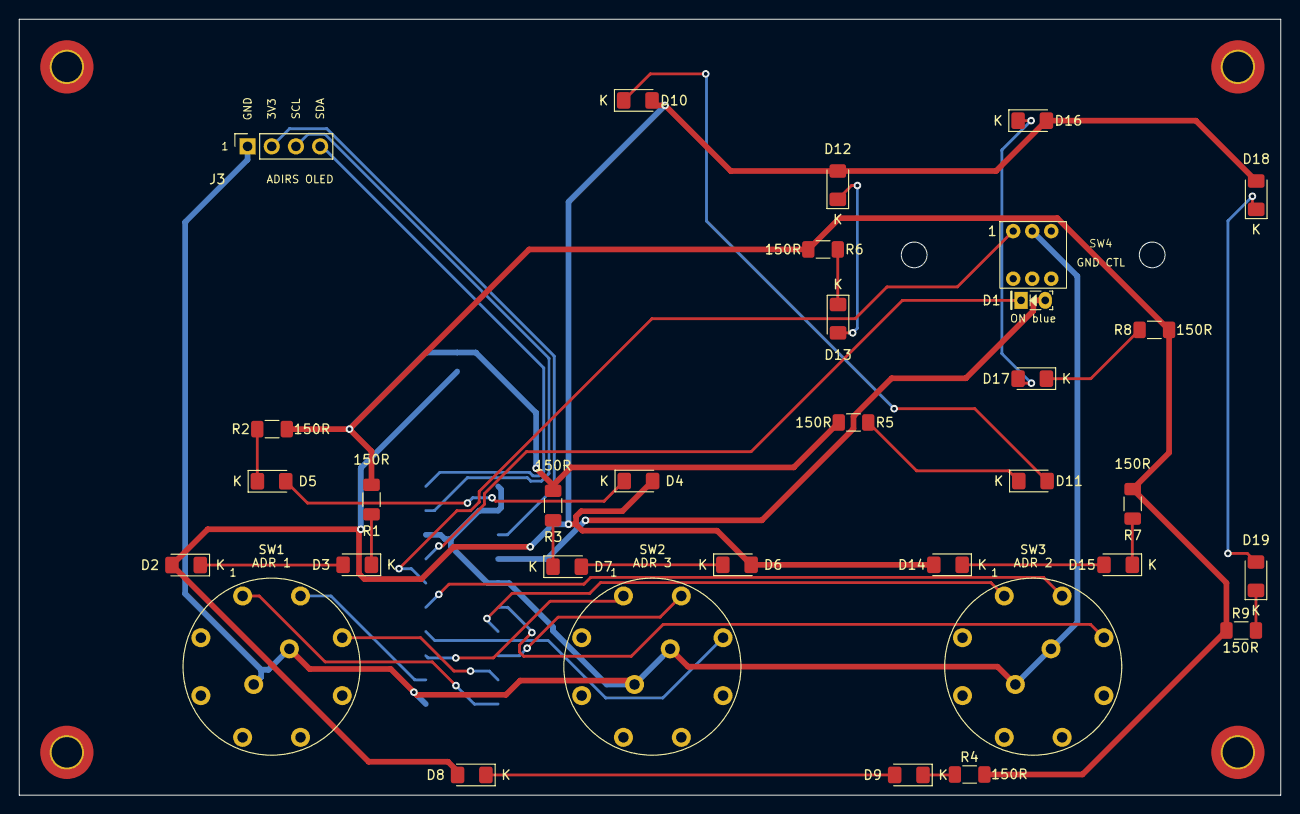
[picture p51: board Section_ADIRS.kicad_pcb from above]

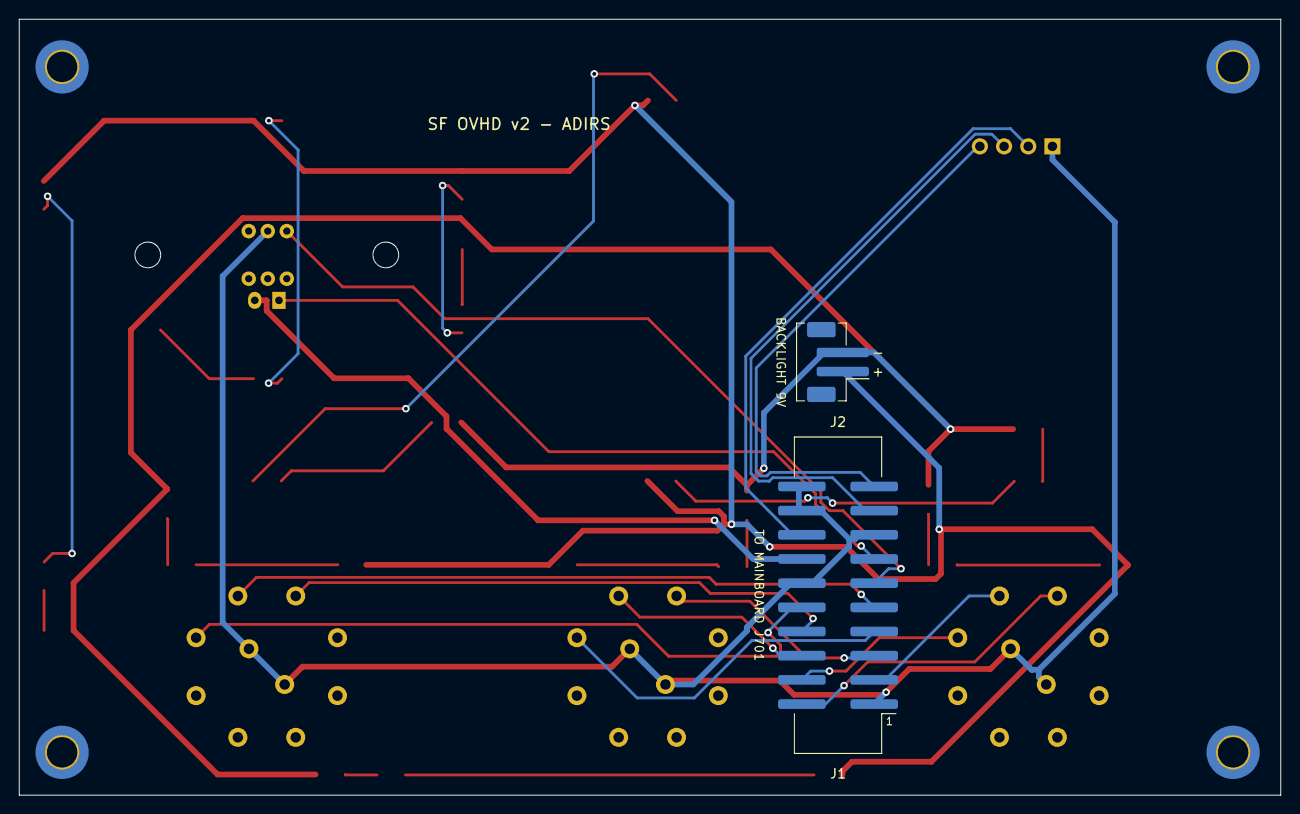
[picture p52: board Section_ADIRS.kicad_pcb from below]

Board: 2 copper layers, 132.5 x 81.5 mm, 41 parts (2 on the bottom side), 36 nets.

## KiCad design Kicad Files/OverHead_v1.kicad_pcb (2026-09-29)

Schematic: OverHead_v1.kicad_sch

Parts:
C1, C2, C3, C4, C7: 100nF; C_1206_3216Metric_Pad1.33x1.80mm_HandSolder
C5: 10uF; C_Elec_4x5.4
C6, C8, C9: 22pF; C_1206_3216Metric_Pad1.33x1.80mm_HandSolder
R1: 10K; R_1206_3216Metric_Pad1.30x1.75mm_HandSolder
U1: ATMega2560; TQFP100-0.5-14X14MM
XT16MHz1: 16MHz; Crystal_SMD_EuroQuartz_MQ-4Pin_7.0x5.0mm_HandSoldering

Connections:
ADR_1_ATT: U1.63 (PJ0); also elsewhere on the board
ADR_1_NAV: U1.64 (PJ1); also elsewhere on the board
ADR_1_OFF: U1.35 (PL0); also elsewhere on the board
ADR_2_ATT: U1.89 (PK0); also elsewhere on the board
ADR_2_NAV: U1.88 (PK1); also elsewhere on the board
ADR_2_OFF: U1.36 (PL1); also elsewhere on the board
ADR_3_ATT: U1.87 (PK2); also elsewhere on the board
ADR_3_NAV: U1.86 (PK3); also elsewhere on the board
ADR_3_OFF: U1.37 (PL2); also elsewhere on the board
ANTI_ICE_ENG1_SW: U1.96 (PF1); also elsewhere on the board
ANTI_ICE_ENG2_SW: U1.95 (PF2); also elsewhere on the board
ANTI_ICE_WING_SW: U1.97 (PF0); also elsewhere on the board
APU_BLEED_SW: U1.90 (PF7); also elsewhere on the board
APU_MASTER_SW: U1.72 (PA6); also elsewhere on the board
APU_START_SW: U1.71 (PA7); also elsewhere on the board
BEACON_ON: U1.58 (PC5); also elsewhere on the board
CLK1: U1.76 (PA2); also elsewhere on the board
CLK2: U1.74 (PA4); also elsewhere on the board
CTR_TK_PUMP_1_SW: U1.17 (PH5); also elsewhere on the board
CTR_TK_PUMP_2_SW: U1.18 (PH6); also elsewhere on the board
DIN1: U1.78 (PA0); also elsewhere on the board
DIN2: U1.75 (PA3); also elsewhere on the board
ELEC_BATT_1_SW: U1.84 (PK5); also elsewhere on the board
ELEC_BATT_2_SW: U1.83 (PK6); also elsewhere on the board
EMERG_OFF: U1.7 (PE5); also elsewhere on the board
EMERG_ON: U1.6 (PE4); also elsewhere on the board
EXT_PWR_SW: U1.70 (PG2); also elsewhere on the board
GND: C1.2, C2.2, C3.2, C4.2, C5.2, C6.2, C7.2, C8.2, C9.2, U1.11 (GND), U1.32 (GND), U1.62 (GND), U1.81 (GND), U1.99 (GND), XT16MHz1.2, XT16MHz1.4; also elsewhere on the board
GND_CTL_SW: U1.82 (PK7); also elsewhere on the board
GPWS_FLAPS3_SW: U1.91 (PF6); also elsewhere on the board
GPWS_GS_SW: U1.92 (PF5); also elsewhere on the board
GPWS_SYS_SW: U1.93 (PF4); also elsewhere on the board
GPWS_TERR_SW: U1.94 (PF3); also elsewhere on the board
LCH1: U1.77 (PA1); also elsewhere on the board
LCH2: U1.73 (PA5); also elsewhere on the board
LT_TK_PUMP_1_SW: U1.12 (PH0); also elsewhere on the board
LT_TK_PUMP_2_SW: U1.13 (PH1); also elsewhere on the board
L_LDG_LIGHT_ON: U1.23 (PB4); also elsewhere on the board
L_LDG_LIGHT_RETR: U1.24 (PB5); also elsewhere on the board
MISO: U1.22 (PB3); also elsewhere on the board
MOSI: U1.21 (PB2); also elsewhere on the board
NAV_1: U1.56 (PC3); also elsewhere on the board
NAV_1_OFF: U1.55 (PC2); also elsewhere on the board
NOSE_OFF: U1.54 (PC1); also elsewhere on the board
NOSE_TO: U1.53 (PC0); also elsewhere on the board
NOSMOKING_ON: U1.50 (PD7); also elsewhere on the board
unnamed: C7.1, U1.98 (AREF)
unnamed: C9.1, U1.34 (XTAL1), XT16MHz1.1
unnamed: C8.1, U1.33 (XTAL2), XT16MHz1.3
OXY_CREW_SUPPLY_SW: U1.85 (PK4); also elsewhere on the board
PACK1_SW: U1.51 (PG0); also elsewhere on the board
PACK2_SW: U1.52 (PG1); also elsewhere on the board
RESET: C6.1, R1.2, U1.30 (~RESET); also elsewhere on the board
RT_TK_PUMP_1_SW: U1.15 (PH3); also elsewhere on the board
RT_TK_PUMP_2_SW: U1.16 (PH4); also elsewhere on the board
RWY_TURN_ON: U1.60 (PC7); also elsewhere on the board
RXD: U1.2 (PE0); also elsewhere on the board
R_LDG_LIGHT_ON: U1.25 (PB6); also elsewhere on the board
R_LDG_LIGHT_RETR: U1.26 (PB7); also elsewhere on the board
SCK: U1.20 (PB1); also elsewhere on the board
SCL: U1.43 (PD0); also elsewhere on the board
SDA: U1.44 (PD1); also elsewhere on the board
SEATBELTS_ON: U1.45 (PD2); also elsewhere on the board
STROBE_ON: U1.59 (PC6); also elsewhere on the board
TXD: U1.3 (PE1); also elsewhere on the board
VIN: C1.1, C2.1, C3.1, C4.1, C5.1, R1.1, U1.10 (VCC), U1.31 (VCC), U1.61 (VCC), U1.80 (VCC), U1.100 (AVCC); also elsewhere on the board
WING_ON: U1.57 (PC4); also elsewhere on the board
XFEED_SW: U1.1 (PG5); also elsewhere on the board

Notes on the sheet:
DM13A Drivers

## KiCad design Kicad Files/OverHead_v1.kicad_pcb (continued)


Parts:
H13, H14, H15, H16: MountingHole; MountingHole_3.2mm_M3_DIN965_Pad_TopBottom
SW6: TERR; G-Switch PS-7054DVB-6PN
SW7: SYS; G-Switch PS-7054DVB-6PN
SW8: G/S MODE; G-Switch PS-7054DVB-6PN
SW9: LDG FLAPS 3; G-Switch PS-7054DVB-6PN

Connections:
GND: SW6.2, SW7.2, SW8.2, SW9.2; also elsewhere on the board
GPWS_FLAPS3_SW: SW9.1; also elsewhere on the board
GPWS_GS_SW: SW8.1; also elsewhere on the board
GPWS_SYS_SW: SW7.1; also elsewhere on the board
GPWS_TERR_SW: SW6.1; also elsewhere on the board


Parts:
H9, H10, H11, H12: MountingHole; MountingHole_3.2mm_M3_DIN965_Pad_TopBottom
S9: SEATBELTS; Toggle_Switch_100SP1T1B4M2QE; MPN 100SP1T1B4M2QE; Digi-Key_PN EG2355-ND
S10: NOSMOKING; Toggle_Switch_100SP1T1B4M2QE; MPN 100SP1T1B4M2QE; Digi-Key_PN EG2355-ND
S11: EMERGENCY_LT; Toggle_Switch_100SP1T1B4M2QE; MPN 100SP1T1B4M2QE; Digi-Key_PN EG2355-ND
SW3: ANTI_ICE_WING_SW; G-Switch PS-7054DVB-6PN
SW4: ANTI_ICE_ENG1_SW; G-Switch PS-7054DVB-6PN
SW5: ANTI_ICE_ENG2_SW; G-Switch PS-7054DVB-6PN

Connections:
ANTI_ICE_ENG1_SW: SW4.1; also elsewhere on the board
ANTI_ICE_ENG2_SW: SW5.1; also elsewhere on the board
ANTI_ICE_WING_SW: SW3.1; also elsewhere on the board
EMERG_OFF: S11.3; also elsewhere on the board
EMERG_ON: S11.1; also elsewhere on the board
GND: S9.2 (Com), S10.2 (Com), S11.2 (Com), SW3.2, SW4.2, SW5.2; also elsewhere on the board
NOSMOKING_OFF: S10.3
NOSMOKING_ON: S10.1; also elsewhere on the board
SEATBELTS_OFF: S9.3
SEATBELTS_ON: S9.1; also elsewhere on the board


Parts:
C16: 10uF; C_1206_3216Metric_Pad1.33x1.80mm_HandSolder
C17: 100nF; C_1206_3216Metric_Pad1.33x1.80mm_HandSolder
D76, D79, D120, D121, D122, D123, D124, D125, D127: STS; LED_Rectangular_W3.9mm_H1.8mm_FlatTop
D78, D80, D90, D92, D103, D106, D107: ANN; LED_Rectangular_W3.9mm_H1.8mm_FlatTop
R51: 56; R_1206_3216Metric_Pad1.30x1.75mm_HandSolder
RV1: POT_WHITE; potentiometer_3362P
U6: DM13A-WHITE-0-100; SOP-24_7.5x15.4mm_P1.27mm

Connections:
+5V: C16.1, D76.2 (A), D78.2 (A), D79.2 (A), D80.2 (A), D90.2 (A), D92.2 (A), D103.2 (A), D106.2 (A), D107.2 (A), D120.2 (A), D121.2 (A), D122.2 (A), D123.2 (A), D124.2 (A), D125.2 (A), D127.2 (A), U6.24 (VDD); also elsewhere on the board
/DM13-WHITE/LED_ELEC_BATT_1_OFF: D106.1 (K), U6.20 (OUT15)
/DM13-WHITE/LED_ELEC_BATT_2_OFF: D107.1 (K), U6.19 (OUT14)
/DM13-WHITE/LED_FLAPS3_OFF: D80.1 (K), U6.8 (OUT3)
/DM13-WHITE/LED_GPWS_SYS_OFF: D78.1 (K), U6.6 (OUT1)
/DM13-WHITE/LED_GPWS_TERR_OFF: D76.1 (K), U6.5 (OUT0)
/DM13-WHITE/LED_GS_OFF: D79.1 (K), U6.7 (OUT2)
/DM13-WHITE/LED_LT_TK_PUMP_1_OFF: D120.1 (K), U6.10 (OUT5)
/DM13-WHITE/LED_LT_TK_PUMP_2_OFF: D121.1 (K), U6.11 (OUT6)
/DM13-WHITE/LED_L_XFER_OFF: D122.1 (K), U6.12 (OUT7)
/DM13-WHITE/LED_OXY_CREW_SUPPLY_OFF: D103.1 (K), U6.9 (OUT4)
/DM13-WHITE/LED_PACK1_OFF: D90.1 (K), U6.13 (OUT8)
/DM13-WHITE/LED_PACK2_OFF: D92.1 (K), U6.17 (OUT12)
/DM13-WHITE/LED_RT_TK_PUMP_1_OFF: D125.1 (K), U6.15 (OUT10)
/DM13-WHITE/LED_RT_TK_PUMP_2_OFF: D127.1 (K), U6.14 (OUT9)
/DM13-WHITE/LED_R_XFER_OFF: D124.1 (K), U6.16 (OUT11)
/DM13-WHITE/LED_XFEED_ON: D123.1 (K), U6.18 (OUT13)
CLK1: U6.3 (CLOCK); also elsewhere on the board
DIN1: U6.2 (DIN); also elsewhere on the board
DOUT1: U6.22 (DOUT); also elsewhere on the board
GND: C16.2, C17.1, RV1.1, U6.1 (GND), U6.21 (~EN); also elsewhere on the board
LCH1: U6.4 (LATCH); also elsewhere on the board
unnamed: R51.2, RV1.2
unnamed: C17.2, R51.1, U6.23 (REXT)


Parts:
C20: 10uF; C_1206_3216Metric_Pad1.33x1.80mm_HandSolder
C21: 100nF; C_1206_3216Metric_Pad1.33x1.80mm_HandSolder
D4, D129, D130, D131: STS; LED_Rectangular_W3.9mm_H1.8mm_FlatTop
D109, D126, D132, D133: ANN; LED_Rectangular_W3.9mm_H1.8mm_FlatTop
R52: 56; R_1206_3216Metric_Pad1.30x1.75mm_HandSolder
RV3: POT_BLUE; potentiometer_3362P
U7: DM13A-BLUE-0-100; SOP-24_7.5x15.4mm_P1.27mm

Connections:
+5V: C20.1, D4.2 (A), D109.2 (A), D126.2 (A), D129.2 (A), D130.2 (A), D131.2 (A), D132.2 (A), D133.2 (A), U7.24 (VDD); also elsewhere on the board
/DM13-BLUE/LED_ANTI_ICE_ENG1_ON: D132.1 (K), U7.8 (OUT3)
/DM13-BLUE/LED_ANTI_ICE_ENG2_ON: D133.1 (K), U7.9 (OUT4)
/DM13-BLUE/LED_ANTI_ICE_WING_ON: D131.1 (K), U7.7 (OUT2)
/DM13-BLUE/LED_APU_BLEED_ON: D129.1 (K), U7.14 (OUT9)
/DM13-BLUE/LED_APU_MASTER_ON: D130.1 (K), U7.6 (OUT1)
/DM13-BLUE/LED_APU_START_ON: D4.1 (K), U7.13 (OUT8)
/DM13-BLUE/LED_EXT_PWR_ON: D126.1 (K), U7.10 (OUT5)
/DM13-BLUE/LED_GND_CTL_ON: D109.1 (K), U7.5 (OUT0)
CLK1: U7.3 (CLOCK); also elsewhere on the board
DOUT1: U7.2 (DIN); also elsewhere on the board
GND: C20.2, C21.1, RV3.1, U7.1 (GND), U7.21 (~EN); also elsewhere on the board
LCH1: U7.4 (LATCH); also elsewhere on the board
unnamed: R52.2, RV3.2
unnamed: C21.2, R52.1, U7.23 (REXT)


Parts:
C10, C12, C14, C15, C25: 100nF; C_1206_3216Metric_Pad1.33x1.80mm_HandSolder
C11, C13: 22pF; C_1206_3216Metric_Pad1.33x1.80mm_HandSolder
C26: 470nF; C_1206_3216Metric_Pad1.33x1.80mm_HandSolder
C32, C33: 10uF; C_1206_3216Metric_Pad1.33x1.80mm_HandSolder
C34, C35: 100uF; C_Elec_6.3x7.7
D145: LED; LED_1206_3216Metric_Pad1.42x1.75mm_HandSolder
D162: USB_Protection; D_SMA_DO-214-AC
D163: BarrelJack_Prot; D_SMA_DO-214-AC
D164: BarrelJackProt_FromLed; D_SMA_DO-214-AC
J4: BootLoader; PinHeader_1x06_P2.54mm_Vertical
J5: PJ-102A; Barrel_Jack_5.5mmODx2.1mmID_PJ-102A; MPN PJ-102A; Digi-Key_PN CP-102A-ND
JP1: Power Selector; PinHeader_1x03_P2.54mm_Vertical
P1: USB_C_Plug_USB2.0; USB_B_OST_USB-B1HSxx_Horizontal
R2: 1.5K; R_1206_3216Metric_Pad1.30x1.75mm_HandSolder
R3, R4: 1K; R_1206_3216Metric_Pad1.30x1.75mm_HandSolder
R5: 220; R_1206_3216Metric_Pad1.30x1.75mm_HandSolder
R47: 3.6K; R_1206_3216Metric_Pad1.30x1.75mm_HandSolder
R48: 1.2K; R_1206_3216Metric_Pad1.30x1.75mm_HandSolder
U2: AMS1117-3.3; SOT-223-3_TabPin2
U3: CH340G; SOIC-16_3.9x9.9mm_P1.27mm
U4: MIC29302WU; TO-263-5_TabPin3
XT12MHz1: 12MHz; Crystal_SMD_EuroQuartz_MQ-4Pin_7.0x5.0mm_HandSoldering

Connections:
+3V3: U2.2 (VO); also elsewhere on the board
+5V: C33.2, C35.1, D162.1 (K), JP1.1, R47.1, U2.3 (VI), U4.4 (VOUT); also elsewhere on the board
+9V: D163.2 (A), D164.1 (K); also elsewhere on the board
GND: C10.2, C11.1, C12.2, C13.1, C14.2, C25.2, C26.2, C32.1, C33.1, C34.2, C35.2, J4.6, J5.2, P1.4 (GND), P1.5 (Shield), R5.1, R48.2, U2.1 (GND), U3.1 (GND), U4.3 (GND), XT12MHz1.2, XT12MHz1.4; also elsewhere on the board
MISO: J4.3; also elsewhere on the board
MOSI: J4.4; also elsewhere on the board
unnamed: D145.1 (K), R5.2
unnamed: D162.2 (A), P1.1 (VBUS), R2.1
unnamed: C32.2, C34.1, D163.1 (K), U4.1 (EN), U4.2 (VIN)
unnamed: C25.1, C26.1, D164.2 (A), J5.1
unnamed: R4.2, U3.3 (RXD)
unnamed: R3.2, U3.2 (TXD)
unnamed: C14.1, U3.4 (V3)
unnamed: C11.2, U3.7 (XI), XT12MHz1.1
unnamed: C13.2, U3.8 (XO), XT12MHz1.3
unnamed: C15.1, U3.13 (~DTR)
unnamed: R47.2, R48.1, U4.5 (ADJ)
RESET: C15.2, J4.2; also elsewhere on the board
RXD: R3.1; also elsewhere on the board
SCK: J4.5; also elsewhere on the board
TXD: R4.1; also elsewhere on the board
UD+: P1.3 (D+), R2.2, U3.5 (UD+)
UD-: P1.2 (D-), U3.6 (UD-)
VCC: J4.1, JP1.3
VIN: C10.1, C12.1, D145.2 (A), JP1.2, U3.16 (VCC); also elsewhere on the board

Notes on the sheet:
Place the 100nF as close as practical to the +9V input


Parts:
C18, C22: 10uF; C_1206_3216Metric_Pad1.33x1.80mm_HandSolder
C19, C23: 100nF; C_1206_3216Metric_Pad1.33x1.80mm_HandSolder
D1, D3, D91, D183, D185: STS; LED_Rectangular_W3.9mm_H1.8mm_FlatTop
D2, D50, D51, D52, D75, D77, D87, D89, D99, D108, D128, D178, D184, D188, D190: ANN; LED_Rectangular_W3.9mm_H1.8mm_FlatTop
R49, R50: 56; R_1206_3216Metric_Pad1.30x1.75mm_HandSolder
RV2: POT_GREEN; potentiometer_3362P
RV4: POT_ORANGE; potentiometer_3362P
U5: DM13A-GREEN-0-100; SOP-24_7.5x15.4mm_P1.27mm
U8: DM13A-ORANGE-0-100; SOP-24_7.5x15.4mm_P1.27mm

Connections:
+5V: C18.1, C22.1, D1.2 (A), D2.2 (A), D3.2 (A), D50.2 (A), D51.2 (A), D52.2 (A), D75.2 (A), D77.2 (A), D87.2 (A), D89.2 (A), D91.2 (A), D99.2 (A), D108.2 (A), D128.2 (A), D178.2 (A), D183.2 (A), D184.2 (A), D185.2 (A), D188.2 (A), D190.2 (A), U5.24 (VDD), U8.24 (VDD); also elsewhere on the board
/DM13-ORANGE/DOUT2: U5.2 (DIN), U8.22 (DOUT)
/DM13-ORANGE/LED_ANTI_ICE_ENG1_FAULT: D183.1 (K), U5.9 (OUT4)
/DM13-ORANGE/LED_ANTI_ICE_ENG2_FAULT: D185.1 (K), U5.11 (OUT6)
/DM13-ORANGE/LED_ANTI_ICE_WING_FAULT: D184.1 (K), U5.10 (OUT5)
/DM13-ORANGE/LED_APU_AVAIL: D128.1 (K), U5.13 (OUT8)
/DM13-ORANGE/LED_APU_BLEED_FAULT: D87.1 (K), U5.18 (OUT13)
/DM13-ORANGE/LED_APU_MASTER_FAULT: D178.1 (K), U5.12 (OUT7)
/DM13-ORANGE/LED_ELEC_BATT_1_FAULT: D1.1 (K), U8.19 (OUT14)
/DM13-ORANGE/LED_ELEC_BATT_2_FAULT: D3.1 (K), U8.18 (OUT13)
/DM13-ORANGE/LED_EXT_PWR_AVAIL: D99.1 (K), U5.8 (OUT3)
/DM13-ORANGE/LED_GPWS_SYS_FAULT: D190.1 (K), U8.10 (OUT5)
/DM13-ORANGE/LED_GPWS_TERR_FAULT: D188.1 (K), U8.9 (OUT4)
/DM13-ORANGE/LED_LT_TK_PUMP_1_FAULT: D50.1 (K), U8.17 (OUT12)
/DM13-ORANGE/LED_LT_TK_PUMP_2_FAULT: D51.1 (K), U8.16 (OUT11)
/DM13-ORANGE/LED_L_XFER_FAULT: D52.1 (K), U8.15 (OUT10)
/DM13-ORANGE/LED_PACK1_FAULT: D89.1 (K), U5.19 (OUT14)
/DM13-ORANGE/LED_PACK2_FAULT: D91.1 (K), U5.20 (OUT15)
/DM13-ORANGE/LED_RT_TK_PUMP_1_FAULT: D77.1 (K), U8.13 (OUT8)
/DM13-ORANGE/LED_RT_TK_PUMP_2_FAULT: D108.1 (K), U5.5 (OUT0)
/DM13-ORANGE/LED_R_XFER_FAULT: D75.1 (K), U8.14 (OUT9)
/DM13-ORANGE/LED_XFEED_OPEN: D2.1 (K), U5.7 (OUT2)
CLK2: U5.3 (CLOCK), U8.3 (CLOCK); also elsewhere on the board
DIN2: U8.2 (DIN); also elsewhere on the board
GND: C18.2, C19.1, C22.2, C23.1, RV2.1, RV4.1, U5.1 (GND), U5.21 (~EN), U8.1 (GND), U8.21 (~EN); also elsewhere on the board
LCH2: U5.4 (LATCH), U8.4 (LATCH); also elsewhere on the board
unnamed: R49.2, RV4.2
unnamed: R50.2, RV2.2
unnamed: C19.2, R50.1, U5.23 (REXT)
unnamed: C23.2, R49.1, U8.23 (REXT)


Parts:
C24: 100nF; C_1206_3216Metric_Pad1.33x1.80mm_HandSolder
H34, H35, H36, H37, H38, H39, H40, H41, H42, H43, H44, H45, H46, H47, H48, H49, H50, H51, H52, H53, H54, H55, H56, H57, H58, H59, H60, H61, H62, H63, H64, H65, H66, H67, H68, H69, H70, H71: MountingHole; MountingHole_2.7mm_M2.5
I2C_1: PCA9548APW; SOP65P640X120-24N
J1: BATT_1_OLED; PinSocket_1x04_P2.54mm_Vertical
J2: BATT_2_OLED; PinSocket_1x04_P2.54mm_Vertical
J3: ADIRS_OLED; PinSocket_1x04_P2.54mm_Vertical
R6, R53, R54, R55: 10K; R_1206_3216Metric_Pad1.30x1.75mm_HandSolder
R7, R8, R41, R42, R43, R44, R45, R46: 4.7K; R_1206_3216Metric_Pad1.30x1.75mm_HandSolder
SW28: SW_DIP_x03; SW_DIP_SPSTx03_Slide_9.78x9.8mm_W7.62mm_P2.54mm

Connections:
+3V3: C24.1, I2C_1.24 (VCC), J1.2, J2.2, J3.2, R6.1, R7.2, R8.1, R41.2, R42.2, R43.2, R44.2, R45.2, R46.2, SW28.1, SW28.2, SW28.3; also elsewhere on the board
/I2C/A0: I2C_1.1 (A0), R53.1, SW28.4
/I2C/A1: I2C_1.2 (A1), R54.2, SW28.5
/I2C/A2: I2C_1.21 (A2), R55.2, SW28.6
/I2C/SCL0: I2C_1.5 (SC0), J1.3, R41.1
/I2C/SCL1: I2C_1.7 (SC1), J2.3, R42.1
/I2C/SCL2: I2C_1.9 (SC2), J3.3, R43.1
/I2C/SDA0: I2C_1.4 (SD0), J1.4, R44.1
/I2C/SDA1: I2C_1.6 (SD1), J2.4, R45.1
/I2C/SDA2: I2C_1.8 (SD2), J3.4, R46.1
GND: C24.2, I2C_1.12 (GND), J1.1, J2.1, J3.1, R53.2, R54.1, R55.1; also elsewhere on the board
unnamed: I2C_1.3 (~RESET), R6.2
SCL: I2C_1.22 (SCL), R7.1; also elsewhere on the board
SDA: I2C_1.23 (SDA), R8.2; also elsewhere on the board


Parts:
H21, H22, H23, H24: MountingHole; MountingHole_3.2mm_M3_DIN965_Pad_TopBottom
SW24: GND_CTL; G-Switch PS-7054DVB-6PN
SW25: ADR_1; Rotary_SW_8x1_SF
SW26: ADR_2; Rotary_SW_8x1_SF
SW27: ADR_3; Rotary_SW_8x1_SF

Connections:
ADR_1_ATT: SW25.3; also elsewhere on the board
ADR_1_NAV: SW25.2; also elsewhere on the board
ADR_1_OFF: SW25.1; also elsewhere on the board
ADR_2_ATT: SW26.3; also elsewhere on the board
ADR_2_NAV: SW26.2; also elsewhere on the board
ADR_2_OFF: SW26.1; also elsewhere on the board
ADR_3_ATT: SW27.3; also elsewhere on the board
ADR_3_NAV: SW27.2; also elsewhere on the board
ADR_3_OFF: SW27.1; also elsewhere on the board
GND: SW24.2, SW25.9, SW26.9, SW27.9; also elsewhere on the board
GND_CTL_SW: SW24.1; also elsewhere on the board

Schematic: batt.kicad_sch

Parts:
H30, H31, H32, H33: MountingHole; MountingHole_3.2mm_M3_DIN965_Pad_TopBottom
SW14: OXY_CREW_SUPPLY; G-Switch PS-7054DVB-6PN
SW15: ELEC_BATT_1; G-Switch PS-7054DVB-6PN
SW16: ELEC_BATT_2; G-Switch PS-7054DVB-6PN

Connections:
ELEC_BATT_1_SW: SW15.1; also elsewhere on the board
ELEC_BATT_2_SW: SW16.1; also elsewhere on the board
GND: SW14.2, SW15.2, SW16.2; also elsewhere on the board
OXY_CREW_SUPPLY_SW: SW14.1; also elsewhere on the board

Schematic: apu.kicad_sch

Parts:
H1, H2, H3, H4: MountingHole; MountingHole_3.2mm_M3_DIN965_Pad_TopBottom
SW1: APU_MASTER_SW; G-Switch PS-7054DVB-6PN
SW2: APU_START_SW; G-Switch PS-7054DVB-6PN

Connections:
APU_MASTER_SW: SW1.1; also elsewhere on the board
APU_START_SW: SW2.1; also elsewhere on the board
GND: SW1.2, SW2.2; also elsewhere on the board

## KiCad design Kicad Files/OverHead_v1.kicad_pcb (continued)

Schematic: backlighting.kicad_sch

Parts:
D5, D6, D7, D8, D9, D10, D11, D12, D13, D14, D15, D16, D17, D18, D19, D20, D21, D22, D23, D24, D25, D26, D27, D28, D29, D30, D31, D32, D33, D34, D35, D36, D37, D38, D39, D40, D41, D42, D43, D44, D45, D46, D47, D48, D49, D53, D54, D55, D56, D57, D58, D59, D60, D61, D62, D63, D64, D65, D66, D67, D68, D69, D70, D71, D72, D73, D74, D81, D82, D83, D84, D85, D86, D88, D93, D94, D95, D96, D97, D98, D100, D101, D102, D104, D105, D110, D111, D112, D113, D114, D115, D116, D117, D118, D119, D134, D135, D136, D137, D138, D139, D140, D141, D142, D143, D144, D146, D147, D148, D149, D150, D151, D152, D153, D154, D155, D156, D157, D158, D159, D160, D161: LED; LED_1206_3216Metric_Pad1.42x1.75mm_HandSolder
R9, R10, R11, R12, R13, R14, R15, R16, R17, R18, R19, R20, R21, R22, R23, R24, R25, R26, R27, R28, R29, R30, R31, R32, R33, R34, R35, R36, R37, R38, R39, R40, R57, R58, R59, R60, R61, R62, R63, R64, R65, R66, R67, R68, R69, R70, R71, R72, R73, R74, R75, R76, R77, R78, R79, R80, R81, R82, R83, R84, R85: 150; R_1206_3216Metric_Pad1.30x1.75mm_HandSolder

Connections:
+9V: D5.2 (A), D7.2 (A), D9.2 (A), D11.2 (A), D13.2 (A), D15.2 (A), D17.2 (A), D19.2 (A), D21.2 (A), D23.2 (A), D25.2 (A), D27.2 (A), D29.2 (A), D31.2 (A), D33.2 (A), D35.2 (A), D37.2 (A), D39.2 (A), D41.2 (A), D43.2 (A), D45.2 (A), D47.2 (A), D49.2 (A), D54.2 (A), D56.2 (A), D58.2 (A), D60.2 (A), D62.2 (A), D64.2 (A), D66.2 (A), D68.2 (A), D70.2 (A), D72.2 (A), D74.2 (A), D82.2 (A), D84.2 (A), D86.2 (A), D93.2 (A), D95.2 (A), D97.2 (A), D100.2 (A), D102.2 (A), D105.2 (A), D111.2 (A), D113.2 (A), D115.2 (A), D117.2 (A), D119.2 (A), D135.2 (A), D137.2 (A), D139.2 (A), D141.2 (A), D143.2 (A), D146.2 (A), D148.2 (A), D150.2 (A), D152.2 (A), D154.2 (A), D156.2 (A), D158.2 (A), D160.2 (A); also elsewhere on the board
GND: R9.2, R10.2, R11.2, R12.2, R13.2, R14.2, R15.2, R16.2, R17.2, R18.2, R19.2, R20.2, R21.2, R22.2, R23.2, R24.2, R25.2, R26.2, R27.2, R28.2, R29.2, R30.2, R31.2, R32.2, R33.2, R34.2, R35.2, R36.2, R37.2, R38.2, R39.2, R40.2, R57.2, R58.2, R59.2, R60.2, R61.2, R62.2, R63.2, R64.2, R65.2, R66.2, R67.2, R68.2, R69.2, R70.2, R71.2, R72.2, R73.2, R74.2, R75.2, R76.2, R77.2, R78.2, R79.2, R80.2, R81.2, R82.2, R83.2, R84.2, R85.2; also elsewhere on the board
unnamed: D5.1 (K), D6.2 (A)
unnamed: D6.1 (K), R9.1
unnamed: D7.1 (K), D8.2 (A)
unnamed: D8.1 (K), R10.1
unnamed: D9.1 (K), D10.2 (A)
unnamed: D10.1 (K), R11.1
unnamed: D11.1 (K), D12.2 (A)
unnamed: D12.1 (K), R12.1
unnamed: D13.1 (K), D14.2 (A)
unnamed: D14.1 (K), R13.1
unnamed: D15.1 (K), D16.2 (A)
unnamed: D16.1 (K), R14.1
unnamed: D17.1 (K), D18.2 (A)
unnamed: D18.1 (K), R15.1
unnamed: D19.1 (K), D20.2 (A)
unnamed: D20.1 (K), R16.1
unnamed: D21.1 (K), D22.2 (A)
unnamed: D22.1 (K), R17.1
unnamed: D23.1 (K), D24.2 (A)
unnamed: D24.1 (K), R18.1
unnamed: D25.1 (K), D26.2 (A)
unnamed: D26.1 (K), R19.1
unnamed: D27.1 (K), D28.2 (A)
unnamed: D28.1 (K), R20.1
unnamed: D29.1 (K), D30.2 (A)
unnamed: D30.1 (K), R21.1
unnamed: D31.1 (K), D32.2 (A)
unnamed: D32.1 (K), R22.1
unnamed: D33.1 (K), D34.2 (A)
unnamed: D34.1 (K), R23.1
unnamed: D35.1 (K), D36.2 (A)
unnamed: D36.1 (K), R24.1
unnamed: D37.1 (K), D38.2 (A)
unnamed: D38.1 (K), R25.1
unnamed: D39.1 (K), D40.2 (A)
unnamed: D40.1 (K), R26.1
unnamed: D41.1 (K), D42.2 (A)
unnamed: D42.1 (K), R27.1
unnamed: D43.1 (K), D44.2 (A)
unnamed: D44.1 (K), R28.1
unnamed: D45.1 (K), D46.2 (A)
unnamed: D46.1 (K), R29.1
unnamed: D47.1 (K), D48.2 (A)
unnamed: D48.1 (K), R30.1
unnamed: D49.1 (K), D53.2 (A)
unnamed: D53.1 (K), R31.1
unnamed: D54.1 (K), D55.2 (A)
unnamed: D55.1 (K), R32.1
unnamed: D56.1 (K), D57.2 (A)
unnamed: D57.1 (K), R33.1
unnamed: D58.1 (K), D59.2 (A)
unnamed: D59.1 (K), R34.1
unnamed: D60.1 (K), D61.2 (A)
unnamed: D61.1 (K), R35.1
unnamed: D62.1 (K), D63.2 (A)
unnamed: D63.1 (K), R36.1
unnamed: D64.1 (K), D65.2 (A)
unnamed: D65.1 (K), R37.1
unnamed: D66.1 (K), D67.2 (A)
unnamed: D67.1 (K), R38.1
unnamed: D68.1 (K), D69.2 (A)
unnamed: D69.1 (K), R39.1
unnamed: D70.1 (K), D71.2 (A)
unnamed: D71.1 (K), R40.1
unnamed: D72.1 (K), D73.2 (A)
unnamed: D73.1 (K), R57.1
unnamed: D74.1 (K), D81.2 (A)
unnamed: D81.1 (K), R58.1
unnamed: D82.1 (K), D83.2 (A)
unnamed: D83.1 (K), R59.1
unnamed: D84.1 (K), D85.2 (A)
unnamed: D85.1 (K), R60.1
unnamed: D86.1 (K), D88.2 (A)
unnamed: D88.1 (K), R61.1
unnamed: D93.1 (K), D94.2 (A)
unnamed: D94.1 (K), R62.1
unnamed: D95.1 (K), D96.2 (A)
unnamed: D96.1 (K), R63.1
unnamed: D97.1 (K), D98.2 (A)
unnamed: D98.1 (K), R64.1
unnamed: D100.1 (K), D101.2 (A)
unnamed: D101.1 (K), R65.1
unnamed: D102.1 (K), D104.2 (A)
unnamed: D104.1 (K), R66.1
unnamed: D105.1 (K), D110.2 (A)
unnamed: D110.1 (K), R67.1
unnamed: D111.1 (K), D112.2 (A)
unnamed: D112.1 (K), R68.1
unnamed: D113.1 (K), D114.2 (A)
unnamed: D114.1 (K), R69.1
unnamed: D115.1 (K), D116.2 (A)
unnamed: D116.1 (K), R70.1
unnamed: D117.1 (K), D118.2 (A)
unnamed: D118.1 (K), R71.1
unnamed: D119.1 (K), D134.2 (A)
unnamed: D134.1 (K), R72.1
unnamed: D135.1 (K), D136.2 (A)
unnamed: D136.1 (K), R73.1
unnamed: D137.1 (K), D138.2 (A)
unnamed: D138.1 (K), R74.1
unnamed: D139.1 (K), D140.2 (A)
unnamed: D140.1 (K), R75.1
unnamed: D141.1 (K), D142.2 (A)
unnamed: D142.1 (K), R76.1
unnamed: D143.1 (K), D144.2 (A)
unnamed: D144.1 (K), R77.1
unnamed: D146.1 (K), D147.2 (A)
unnamed: D147.1 (K), R78.1
unnamed: D148.1 (K), D149.2 (A)
unnamed: D149.1 (K), R79.1
unnamed: D150.1 (K), D151.2 (A)
unnamed: D151.1 (K), R80.1
unnamed: D152.1 (K), D153.2 (A)
unnamed: D153.1 (K), R81.1
unnamed: D154.1 (K), D155.2 (A)
unnamed: D155.1 (K), R82.1
unnamed: D156.1 (K), D157.2 (A)
unnamed: D157.1 (K), R83.1
unnamed: D158.1 (K), D159.2 (A)
unnamed: D159.1 (K), R84.1
unnamed: D160.1 (K), D161.2 (A)
unnamed: D161.1 (K), R85.1

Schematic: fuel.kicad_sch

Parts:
H25, H26, H27, H28, H29: MountingHole; MountingHole_3.2mm_M3_DIN965_Pad_TopBottom
SW17: LT_TK_PUMP_1; G-Switch PS-7054DVB-6PN
SW18: LT_TK_PUMP_2; G-Switch PS-7054DVB-6PN
SW19: L_XFER; G-Switch PS-7054DVB-6PN
SW20: X_FEED; G-Switch PS-7054DVB-6PN
SW21: R_XFER; G-Switch PS-7054DVB-6PN
SW22: RT_TK_PUMP_1; G-Switch PS-7054DVB-6PN
SW23: RT_TK_PUMP_2; G-Switch PS-7054DVB-6PN

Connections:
CTR_TK_PUMP_1_SW: SW19.1; also elsewhere on the board
CTR_TK_PUMP_2_SW: SW21.1; also elsewhere on the board
GND: SW17.2, SW18.2, SW19.2, SW20.2, SW21.2, SW22.2, SW23.2; also elsewhere on the board
LT_TK_PUMP_1_SW: SW17.1; also elsewhere on the board
LT_TK_PUMP_2_SW: SW18.1; also elsewhere on the board
RT_TK_PUMP_1_SW: SW22.1; also elsewhere on the board
RT_TK_PUMP_2_SW: SW23.1; also elsewhere on the board
XFEED_SW: SW20.1; also elsewhere on the board

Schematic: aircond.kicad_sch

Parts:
H17, H18, H19, H20: MountingHole; MountingHole_3.2mm_M3_DIN965_Pad_TopBottom
SW10: APU BLEED; G-Switch PS-7054DVB-6PN
SW11: PACK1; G-Switch PS-7054DVB-6PN
SW12: PACK2; G-Switch PS-7054DVB-6PN
SW13: EXT_PWR; G-Switch PS-7054DVB-6PN

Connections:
APU_BLEED_SW: SW10.1; also elsewhere on the board
EXT_PWR_SW: SW13.1; also elsewhere on the board
GND: SW10.2, SW11.2, SW12.2, SW13.2; also elsewhere on the board
PACK1_SW: SW11.1; also elsewhere on the board
PACK2_SW: SW12.1; also elsewhere on the board

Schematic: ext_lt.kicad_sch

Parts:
H5, H6, H7, H8: MountingHole; MountingHole_3.2mm_M3_DIN965_Pad_TopBottom
S1: LDG_LIGHT_L; Toggle_Switch_100SP1T1B4M2QE; MPN 100SP1T1B4M2QE; Digi-Key_PN EG2355-ND
S2: LDG_LIGHT_R; Toggle_Switch_100SP1T1B4M2QE; MPN 100SP1T1B4M2QE; Digi-Key_PN EG2355-ND
S3: NOSE_LIGHT; Toggle_Switch_100SP1T1B4M2QE; MPN 100SP1T1B4M2QE; Digi-Key_PN EG2355-ND
S4: NAV&LOGO; Toggle_Switch_100SP1T1B4M2QE; MPN 100SP1T1B4M2QE; Digi-Key_PN EG2355-ND
S5: WING; Toggle_Switch_100SP1T1B4M2QE; MPN 100SP1T1B4M2QE; Digi-Key_PN EG2355-ND
S6: BEACON; Toggle_Switch_100SP1T1B4M2QE; MPN 100SP1T1B4M2QE; Digi-Key_PN EG2355-ND
S7: STROBE; Toggle_Switch_100SP1T1B4M2QE; MPN 100SP1T1B4M2QE; Digi-Key_PN EG2355-ND
S8: RWY TURN; Toggle_Switch_100SP1T1B4M2QE; MPN 100SP1T1B4M2QE; Digi-Key_PN EG2355-ND

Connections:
BEACON_ON: S6.1; also elsewhere on the board
GND: S1.2 (Com), S2.2 (Com), S3.2 (Com), S4.2 (Com), S5.2 (Com), S6.2 (Com), S7.2 (Com), S8.2 (Com); also elsewhere on the board
L_LDG_LIGHT_ON: S1.1; also elsewhere on the board
L_LDG_LIGHT_RETR: S1.3; also elsewhere on the board
NAV_1: S4.1; also elsewhere on the board
NAV_1_OFF: S4.3; also elsewhere on the board
NOSE_OFF: S3.3; also elsewhere on the board
NOSE_TO: S3.1; also elsewhere on the board
RWY_TURN_ON: S8.1; also elsewhere on the board
R_LDG_LIGHT_ON: S2.1; also elsewhere on the board
R_LDG_LIGHT_RETR: S2.3; also elsewhere on the board
STROBE_ON: S7.1; also elsewhere on the board
WING_ON: S5.1; also elsewhere on the board



Board: 4 copper layers, 313.0 x 206.0 mm, 416 parts (77 on the bottom side), 271 nets.

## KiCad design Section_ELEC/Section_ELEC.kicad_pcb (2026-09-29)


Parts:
D1, D3, D5: white; LED_Rectangular_W3.9mm_H1.8mm_FlatTop
D2, D4: amber; LED_Rectangular_W3.9mm_H1.8mm_FlatTop
D6, D7, D8, D9, D10, D11, D12, D13, D14, D15: LED; LED_1206_3216Metric_Pad1.42x1.75mm_HandSolder
H1, H2, H3, H4: M3; MountingHole_3.2mm_M3_DIN965_Pad_TopBottom
H5, H6, H7, H8: M2.5; MountingHole_2.7mm_M2.5
J1: ELEC ribbon; IDC-Header_2x10_P2.54mm_Vertical_SMD
J2: Backlight; JST_PH_B2B-PH-SM4-TB_1x02-1MP_P2.00mm_Vertical
J3: BATT 1 OLED; PinSocket_1x04_P2.54mm_Vertical
J4: BATT 2 OLED; PinSocket_1x04_P2.54mm_Vertical
R1, R2, R3, R4, R5: 150; R_1206_3216Metric_Pad1.30x1.75mm_HandSolder
SW1: ELEC OXY CREW SUPPLY; G-Switch_PS-7054DVB-6PN
SW2: ELEC BATT 1; G-Switch_PS-7054DVB-6PN
SW3: ELEC BATT 2; G-Switch_PS-7054DVB-6PN

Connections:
+3V3: J1.13, J3.2, J4.2
+5V_LED: D1.2 (A), D2.2 (A), D3.2 (A), D4.2 (A), D5.2 (A), J1.11
+9V_BL: D6.2 (A), D8.2 (A), D10.2 (A), D12.2 (A), D14.2 (A), J2.1
BATT_1_SW: J1.3, SW2.1
BATT_2_SW: J1.4, SW3.1
BL1_MID: D6.1 (K), D7.2 (A)
BL1_R: D7.1 (K), R1.1
BL2_MID: D8.1 (K), D9.2 (A)
BL2_R: D9.1 (K), R2.1
BL3_MID: D10.1 (K), D11.2 (A)
BL3_R: D11.1 (K), R3.1
BL4_MID: D12.1 (K), D13.2 (A)
BL4_R: D13.1 (K), R4.1
BL5_MID: D14.1 (K), D15.2 (A)
BL5_R: D15.1 (K), R5.1
BL_RET: J2.2, R1.2, R2.2, R3.2, R4.2, R5.2
CREW_SUPPLY_SW: J1.2, SW1.1
GND: J1.1, J1.5, J1.12, J1.15, J1.17, J1.19, J3.1, J4.1, SW1.2, SW2.2, SW3.2
LED_ELEC_BATT_1_FAULT: D2.1 (K), J1.8
LED_ELEC_BATT_1_OFF: D3.1 (K), J1.7
LED_ELEC_BATT_2_FAULT: D4.1 (K), J1.10
LED_ELEC_BATT_2_OFF: D5.1 (K), J1.9
LED_OXY_CREW_SUPPLY_OFF: D1.1 (K), J1.6
SCL0: J1.14, J3.3
SCL1: J1.18, J4.3
SDA0: J1.16, J3.4
SDA1: J1.20, J4.4

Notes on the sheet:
Backlight strings
Power flags
Ribbon and backlight connectors
Switches
Mounting holes, as v1
ELEC section board (v2). Switches, annunciator and backlight LEDs at their v1 coordinates. Annunciator anodes on +5V_LED, cathodes down the ribbon to the TLC5927 outputs on the mainboard (no resistors: the TLC5927 sinks a set current). Backlight on +9V_BL, return switched on the mainboard. J1 pinou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
Annunciators (anode on +5V_LED, cathode to the TLC5927)



Board: 2 copper layers, 177.5 x 39.5 mm, 35 parts (3 on the bottom side), 27 nets.

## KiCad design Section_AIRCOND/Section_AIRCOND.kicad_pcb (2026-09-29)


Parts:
D1, D3, D5: amber; LED_Rectangular_W3.9mm_H1.8mm_FlatTop
D2, D8: blue; LED_Rectangular_W3.9mm_H1.8mm_FlatTop
D4, D6: white; LED_Rectangular_W3.9mm_H1.8mm_FlatTop
D7: green; LED_Rectangular_W3.9mm_H1.8mm_FlatTop
D9, D10, D11, D12, D13, D14, D15, D16, D17, D18, D19, D20, D21: LED; LED_1206_3216Metric_Pad1.42x1.75mm_HandSolder
H1, H2, H3, H4: M3; MountingHole_3.2mm_M3_DIN965_Pad_TopBottom
H5, H6, H7, H8, H9, H10, H11, H12: M2.5; MountingHole_2.7mm_M2.5
J1: AIRCOND ribbon; IDC-Header_2x08_P2.54mm_Vertical_SMD
J2: Backlight; JST_PH_B2B-PH-SM4-TB_1x02-1MP_P2.00mm_Vertical
R1, R2, R3, R4, R5, R6: 150; R_1206_3216Metric_Pad1.30x1.75mm_HandSolder
R7: 330; R_1206_3216Metric_Pad1.30x1.75mm_HandSolder
SW1: AIRCOND APU BLEED; G-Switch_PS-7054DVB-6PN
SW2: AIRCOND PACK 1; G-Switch_PS-7054DVB-6PN
SW3: AIRCOND PACK 2; G-Switch_PS-7054DVB-6PN
SW4: AIRCOND EXT PWR; G-Switch_PS-7054DVB-6PN

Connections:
+5V_LED: D1.2 (A), D2.2 (A), D3.2 (A), D4.2 (A), D5.2 (A), D6.2 (A), D7.2 (A), D8.2 (A), J1.15
+9V_BL: D9.2 (A), D11.2 (A), D13.2 (A), D15.2 (A), D17.2 (A), D19.2 (A), D21.2 (A), J2.1
APU_BLEED_SW: J1.2, SW1.1
BL1_MID: D9.1 (K), D10.2 (A)
BL1_R: D10.1 (K), R1.1
BL2_MID: D11.1 (K), D12.2 (A)
BL2_R: D12.1 (K), R2.1
BL3_MID: D13.1 (K), D14.2 (A)
BL3_R: D14.1 (K), R3.1
BL4_MID: D15.1 (K), D16.2 (A)
BL4_R: D16.1 (K), R4.1
BL5_MID: D17.1 (K), D18.2 (A)
BL5_R: D18.1 (K), R5.1
BL6_MID: D19.1 (K), D20.2 (A)
BL6_R: D20.1 (K), R6.1
BL7_R: D21.1 (K), R7.1
BL_RET: J2.2, R1.2, R2.2, R3.2, R4.2, R5.2, R6.2, R7.2
EXT_PWR_SW: J1.5, SW4.1
GND: J1.1, J1.6, J1.16, SW1.2, SW2.2, SW3.2, SW4.2
LED_APU_BLEED_FAULT: D1.1 (K), J1.8
LED_APU_BLEED_ON: D2.1 (K), J1.7
LED_EXT_PWR_AVAIL: D7.1 (K), J1.14
LED_EXT_PWR_ON: D8.1 (K), J1.13
LED_PACK1_FAULT: D3.1 (K), J1.10
LED_PACK1_OFF: D4.1 (K), J1.9
LED_PACK2_FAULT: D5.1 (K), J1.12
LED_PACK2_OFF: D6.1 (K), J1.11
PACKS_1_SW: J1.3, SW2.1
PACKS_2_SW: J1.4, SW3.1

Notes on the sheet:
Annunciators (anode on +5V_LED, cathode to the TLC5927)
Backlight strings
Switches
AIRCOND section board (v2). Switches, annunciator and backlight LEDs at their v1 coordinates. Annunciator anodes on +5V_LED, cathodes down the ribbon to the TLC5927 outputs on the mainboard (no resistors: the TLC5927 sinks a set current). Backlight on +9V_BL, return switched on the mainboard. J1 pi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
Power flags
Mounting holes, as v1
Ribbon and backlight connectors



Board: 2 copper layers, 150.5 x 39.0 mm, 46 parts (2 on the bottom side), 29 nets.

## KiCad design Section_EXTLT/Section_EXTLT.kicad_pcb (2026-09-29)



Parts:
D1, D2, D3, D4, D5, D6, D7, D8, D9, D10, D11, D12, D13, D14, D15, D16, D17, D18, D19, D20, D21, D22, D23, D24, D25, D26, D27, D28, D29, D30, D31: LED; LED_1206_3216Metric_Pad1.42x1.75mm_HandSolder
H1, H2, H3, H4: M3; MountingHole_3.2mm_M3_DIN965_Pad_TopBottom
J1: EXTLT ribbon; IDC-Header_2x07_P2.54mm_Vertical_SMD
J2: Backlight; JST_PH_B2B-PH-SM4-TB_1x02-1MP_P2.00mm_Vertical
R1, R2, R3, R4, R5, R6, R7, R8, R9, R10, R11, R12, R13, R14, R15: 150; R_1206_3216Metric_Pad1.30x1.75mm_HandSolder
R16: 330; R_1206_3216Metric_Pad1.30x1.75mm_HandSolder
SW1: EXTLT STROBE; Toggle_Switch_100SP1T1B4M2QE
SW2: EXTLT BEACON; Toggle_Switch_100SP1T1B4M2QE
SW3: EXTLT WING; Toggle_Switch_100SP1T1B4M2QE
SW4: EXTLT NAV & LOGO; Toggle_Switch_100SP1T1B4M2QE
SW5: EXTLT RWY TURN; Toggle_Switch_100SP1T1B4M2QE
SW6: EXTLT LDG LIGHT L; Toggle_Switch_100SP1T1B4M2QE
SW7: EXTLT LDG LIGHT R; Toggle_Switch_100SP1T1B4M2QE
SW8: EXTLT NOSE LIGHT; Toggle_Switch_100SP1T1B4M2QE

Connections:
+9V_BL: D1.2 (A), D3.2 (A), D5.2 (A), D7.2 (A), D9.2 (A), D11.2 (A), D13.2 (A), D15.2 (A), D17.2 (A), D19.2 (A), D21.2 (A), D23.2 (A), D25.2 (A), D27.2 (A), D29.2 (A), D31.2 (A), J2.1
BEACON: J1.3, SW2.1
BL1_MID: D1.1 (K), D2.2 (A)
BL1_R: D2.1 (K), R1.1
BL2_MID: D3.1 (K), D4.2 (A)
BL2_R: D4.1 (K), R2.1
BL3_MID: D5.1 (K), D6.2 (A)
BL3_R: D6.1 (K), R3.1
BL4_MID: D7.1 (K), D8.2 (A)
BL4_R: D8.1 (K), R4.1
BL5_MID: D9.1 (K), D10.2 (A)
BL5_R: D10.1 (K), R5.1
BL6_MID: D11.1 (K), D12.2 (A)
BL6_R: D12.1 (K), R6.1
BL7_MID: D13.1 (K), D14.2 (A)
BL7_R: D14.1 (K), R7.1
BL8_MID: D15.1 (K), D16.2 (A)
BL8_R: D16.1 (K), R8.1
BL9_MID: D17.1 (K), D18.2 (A)
BL9_R: D18.1 (K), R9.1
BL10_MID: D19.1 (K), D20.2 (A)
BL10_R: D20.1 (K), R10.1
BL11_MID: D21.1 (K), D22.2 (A)
BL11_R: D22.1 (K), R11.1
BL12_MID: D23.1 (K), D24.2 (A)
BL12_R: D24.1 (K), R12.1
BL13_MID: D25.1 (K), D26.2 (A)
BL13_R: D26.1 (K), R13.1
BL14_MID: D27.1 (K), D28.2 (A)
BL14_R: D28.1 (K), R14.1
BL15_MID: D29.1 (K), D30.2 (A)
BL15_R: D30.1 (K), R15.1
BL16_R: D31.1 (K), R16.1
BL_RET: J2.2, R1.2, R2.2, R3.2, R4.2, R5.2, R6.2, R7.2, R8.2, R9.2, R10.2, R11.2, R12.2, R13.2, R14.2, R15.2, R16.2
GND: J1.1, J1.7, SW1.2 (Com), SW2.2 (Com), SW3.2 (Com), SW4.2 (Com), SW5.2 (Com), SW6.2 (Com), SW7.2 (Com), SW8.2 (Com)
L_LDG_LIGHT_ON: J1.9, SW6.1
L_LDG_LIGHT_RETR: J1.10, SW6.3
NAV_LOGO_1: J1.5, SW4.1
NAV_LOGO_OFF: J1.6, SW4.3
NOSELIGHT_OFF: J1.14, SW8.3
NOSELIGHT_TO: J1.13, SW8.1
RWY_TURN: J1.8, SW5.1
R_LDG_LIGHT_ON: J1.11, SW7.1
R_LDG_LIGHT_RETR: J1.12, SW7.3
STROBE: J1.2, SW1.1
WING_LIGHTS: J1.4, SW3.1

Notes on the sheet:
Power flags
Ribbon and backlight connectors
Mounting holes, as v1
Switches
Backlight strings
EXTLT section board (v2). Switches, annunciator and backlight LEDs at their v1 coordinates. Annunciator anodes on +5V_LED, cathodes down the ribbon to the TLC5927 outputs on the mainboard (no resistors: the TLC5927 sinks a set current). Backlight on +9V_BL, return switched on the mainboard. J1 pino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



Board: 2 copper layers, 159.5 x 79.5 mm, 61 parts (3 on the bottom side), 46 nets.

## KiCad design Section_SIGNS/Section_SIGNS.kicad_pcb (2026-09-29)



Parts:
D1, D3, D5: amber; LED_Rectangular_W3.9mm_H1.8mm_FlatTop
D2, D4, D6: blue; LED_Rectangular_W3.9mm_H1.8mm_FlatTop
D7, D8, D9, D10, D11, D12, D13, D14, D15, D16, D17, D18, D19, D20, D21, D22, D23, D24, D25, D26, D27, D28: LED; LED_1206_3216Metric_Pad1.42x1.75mm_HandSolder
H1, H2, H3, H4: M3; MountingHole_3.2mm_M3_DIN965_Pad_TopBottom
H5, H6, H7, H8, H9, H10: M2.5; MountingHole_2.7mm_M2.5
J1: SIGNS ribbon; IDC-Header_2x08_P2.54mm_Vertical_SMD
J2: Backlight; JST_PH_B2B-PH-SM4-TB_1x02-1MP_P2.00mm_Vertical
R1, R2, R3, R4, R5, R6, R7, R8, R9, R10, R11: 150; R_1206_3216Metric_Pad1.30x1.75mm_HandSolder
SW1: SIGNS WING; G-Switch_PS-7054DVB-6PN
SW2: SIGNS ENG 1; G-Switch_PS-7054DVB-6PN
SW3: SIGNS ENG 2; G-Switch_PS-7054DVB-6PN
SW4: SIGNS SEAT BELTS; Toggle_Switch_100SP1T1B4M2QE
SW5: SIGNS NO SMOKING; Toggle_Switch_100SP1T1B4M2QE
SW6: SIGNS EMER EXIT LT; Toggle_Switch_100SP1T1B4M2QE
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

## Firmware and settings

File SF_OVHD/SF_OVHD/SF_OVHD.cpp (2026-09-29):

#include "SF_OVHD.h"
#include "TLCSupply.h"
#include <Fonts/FreeSans18pt7b.h>                // ADIRS, from Adafruit GFX
#include "Fonts/DSEG14Modern_Regular20pt7b.h"  // BATT 1 and 2, https://github.com/keshikan/DSEG via https://rop.nl/truetype2gfx/

// Values from the Connector, in fixed buffers so a redraw never touches the
// heap. Each holds more than its display can show at the font it uses.
char ovhdBatt1Value[8]  = "00.00";
char ovhdBatt2Value[8]  = "00.00";
char AdirsValue[16]     = "On batt";

// copies a value from the Connector, cutting it to the buffer rather than overrunning it
static void setValue(char *dest, size_t size, const char *src)
{
    strncpy(dest, src, size - 1);
    dest[size - 1] = 0x00;
}

// light test switch
uint8_t lightTestOn = 0x00;

SF_OVHD::SF_OVHD()
{
    _initialised = false;
}

void SF_OVHD::attach(uint8_t addrI2C)
{
    // Power the annunciator drivers up first, whatever happens to the displays
    // below: the board and its 5 V are up by now. update() finishes the cycle.
    TLCSupply::powerCycle();

    _addrI2C = addrI2C;
    Wire.begin();
    Wire.setClock(400000);
    void *mem = MF_ALLOC_TYPE(OLEDInterface, 1);
    if (!mem) {
        // Error Message to Connector
        cmdMessenger.sendCmd(kStatus, F("Custom Device does not fit in Memory"));
        return;
    }
    if (_addrI2C & 0x01) {
        oled = new (mem) OLEDInterface(SSD1306);
    } else {
        oled = new (mem) OLEDInterface(SH1106);
    }
    // the driver itself may not have fitted; OLEDInterface has reported it
    if (!oled->ready())
        return;
    _initialised = true;
}

void SF_OVHD::begin()
{
    if (!_initialised)
        return;

    // The same three steps for each display: select its channel, initialise the
    // controller behind it, draw. The draw clears the buffer and pushes a
    // frame by itself, so nothing is pushed before it.

    // Battery 1
    setTCAChannel(TCA9548A_CHANNEL_BATT1);
    oled->begin(SCREEN_ADDRESS, true);
    updateDisplayBatt(TCA9548A_CHANNEL_BATT1, ovhdBatt1Value);

    // Battery 2
    setTCAChannel(TCA9548A_CHANNEL_BATT2);
    oled->begin(SCREEN_ADDRESS, true);
    updateDisplayBatt(TCA9548A_CHANNEL_BATT2, ovhdBatt2Value);

    // ADIRS
    setTCAChannel(TCA9548A_CHANNEL_ADIRS);
    oled->begin(SCREEN_ADDRESS, true);
    updateDisplayAdirs();
}

void SF_OVHD::detach()
{
    if (!_initialised)
        return;
    _initialised = false;
}

void SF_OVHD::set(int16_t messageID, char *message)
{
    /* **********************************************************************************
        Each messageID has it's own value
        check for the messageID and define what to do.
        Important Remark!
        MessageID == -1 will be send from the connector when Mobiflight is closed
        Put in your code to shut down your custom device (e.g. clear a display)
        MessageID == -2 will be send from the connector when PowerSavingMode is entered
        Put in your code to enter this mode (e.g. clear a display)

    ********************************************************************************** */
    // The annunciator drivers do not depend on the displays
    if (messageID == 5) {
        TLCSupply::powerCycle();
        return;
    }

    // attach() gives up without a display driver, and then there is nothing to draw on
    if (!_initialised)
        return;

    switch (messageID) {
    case -1: // the Connector is closing
    case -2: // the Connector enters power saving
        // Blank all three rather than leave the last values standing: a static
        // picture burns into an OLED. The next value that arrives redraws its
        // display as usual.
        blankDisplays();
        break;
    case 0:
        /* code */
        setValue(ovhdBatt1Value, sizeof(ovhdBatt1Value), message);
        updateDisplayBatt(TCA9548A_CHANNEL_BATT1, ovhdBatt1Value);
        break;
    case 1:
        /* code */
        setValue(ovhdBatt2Value, sizeof(ovhdBatt2Value), message);
        updateDisplayBatt(TCA9548A_CHANNEL_BATT2, ovhdBatt2Value);
        break;
    case 2:
        /* code */
        setValue(AdirsValue, sizeof(AdirsValue), message);
        updateDisplayAdirs();
        break;
    case 3:
        lightTestOn = atoi(message);
        updateDisplayBatt(TCA9548A_CHANNEL_BATT1, ovhdBatt1Value);
        updateDisplayBatt(TCA9548A_CHANNEL_BATT2, ovhdBatt2Value);
        updateDisplayAdirs();
        break;
    case 4: {
        // 0-100 from the Connector. Until the first one arrives the displays
        // keep their driver's default: 0xCF on SSD1306, 0xFF on SH1106.
        // An empty value is ignored rather than read as 0, which would be darkest.
        if (message[0] == 0x00)
            break;
        int16_t percent = atoi(message);
        setBrightness(percent < 0 ? 0 : (percent > 100 ? 100 : percent));
        break;
    }
    default:
        break;
    }
}

// Called every MF_CUSTOMDEVICE_POLL_MS. It only finishes a power cycle of the
// annunciator drivers: the displays are redrawn when a value arrives and at no
// other time.
void SF_OVHD::update()
{
    TLCSupply::update();
}

/* ************************************************************************************************
 ************************************************************************************************
 ************************************************************************************************ */

/*
  clear all three displays
*/
void SF_OVHD::blankDisplays(void)
{
    const uint8_t channels[] = {TCA9548A_CHANNEL_BATT1, TCA9548A_CHANNEL_BATT2, TCA9548A_CHANNEL_ADIRS};
    for (uint8_t i = 0; i < sizeof(channels); i++) {
        setTCAChannel(channels[i]);
        oled->clearDisplay();
        oled->display();
    }
}

/*
  set the contrast of all three displays; nothing is redrawn, the picture stays
*/
void SF_OVHD::setBrightness(uint8_t percent)
{
    uint8_t       contrast   = (uint16_t)percent * 255 / 100;
    const uint8_t channels[] = {TCA9548A_CHANNEL_BATT1, TCA9548A_CHANNEL_BATT2, TCA9548A_CHANNEL_ADIRS};
    for (uint8_t i = 0; i < sizeof(channels); i++) {
        setTCAChannel(channels[i]);
        oled->setContrast(contrast);
    }
}

/*
  switch multiplexer channel
*/
void SF_OVHD::setTCAChannel(byte i)
{
    Wire.beginTransmission(_addrI2C);
    Wire.write(1 << i);
    // The PCA9548A switches on the STOP that endTransmission() waits for, so the
    // channel is live by the time this returns and needs no pause.
    Wire.endTransmission();
}
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

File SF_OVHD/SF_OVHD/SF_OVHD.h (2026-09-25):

#pragma once

#include "Arduino.h"
#include "OLEDInterface.h"

// The multiplexer's address comes from the Connector, not from here.
// Channel of the PCA9548A each display is wired to:
#define TCA9548A_CHANNEL_BATT1 0
#define TCA9548A_CHANNEL_BATT2 1
#define TCA9548A_CHANNEL_ADIRS 2


class SF_OVHD
{
public:
    SF_OVHD();
    void begin();
    void attach(uint8_t addrI2C);
    void detach();
    void set(int16_t messageID, char *message);
    void update();

private:
    bool          _initialised;
    uint8_t       _addrI2C;
    OLEDInterface *oled;

    void setTCAChannel(byte i);
    void blankDisplays(void);
    void setBrightness(uint8_t percent);
    void updateDisplayBatt(uint8_t channel, const char *value);
    void updateDisplayAdirs(void);

};

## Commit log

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2025-01-15 Fixed some issues with the code and path on remote drive
    [OverHead_v1.kicad_sch, bom.csv, designators.csv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]
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2025-01-15 Changed the polarity label for some backlighting led that were wrongly placed
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2026-09-25 Replace the stale firmware copy with the live SF_OVHD tree
    What sat under SF_OVHD was the January 2025 tree, named SF_OVHD_MAINBOARD.
    The board runs the SF_OVHD package, version 1.0.5, built from
    Documents\vsCode\SF_OVHD in March: multiplexer channels 0/1/2 instead of
    0/1/3, DSEG14 fonts, and the device and board renamed SF_OVHD and
    "SF OVHD Mega". The MobiFlight project binds 96 rows to that board, and its
    custom device is SF_OVHD at 0x71.
    This commit brings that tree over as it is, with no changes. One caveat:
    SF_OVHD.cpp was touched again after the 1.0.5 hex was built. The installed
    binary still prints "28.8V" and "00.0V" where this source prints "28.80" and
    "00.00", and nothing else dif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
    [MFCustomDevice.cpp, SF_OVHD.cpp, SF_OVHD.h]
2026-09-25 Follow MobiFlight's own template: core firmware 3.1.4
    Same move as SF_FCU: the scaffolding now comes from MobiFlight's
    CommunityTemplate, which pins core 3.1.4, up from 2.5.1. The template has
    not changed since SF_FCU was moved, so platformio.ini, the three build
    scripts and the workflows are taken from there as they are, including its
    two fixes: the version read from the environment is stripped, and
    SERIAL_RX_BUFFER_SIZE stays at 256.
    The custom device API moved with the core:
    - attach() takes configFromFlash and bails out when adrPin is zero
    - getStringFromEEPROM() became the bounds-checked getStringFromMem()
    - FitInMemory() is gone. SF_OVHD::attach, OLEDInterface and
    MFCustomDevice no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
    [MFCustomDevice.cpp, OLEDInterface.h, SF_OVHD.cpp]
2026-09-25 Build only the device families the panel has
    The module config on the board, and every row the MobiFlight project binds
    to it, uses three kinds of device: 49 buttons, the two ShiftRegister chains
    that drive the DM13A LED drivers, and the custom device. So segment
    displays, character LCD, steppers, servos, analog inputs, input shifters and
    both multiplexers are unflagged, and board.json no longer offers them.
    This is where the panel parts company with SF_FCU: output shifters stay on.
    The annunciators and the backlighting are 44 outputs on those DM13A chains.
    Buttons, encoders and plain outputs are core and always present.
    RAM 4280 -> 4090 bytes, flash 56794 -> 42226. MFOutputShifter is conf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
2026-09-25 Blank the displays when the Connector closes or goes to sleep
    MessageID -1 (Connector closing) and -2 (power saving, after the 600 s in
    the .mfmc) fell through into case 0 for want of a break. Whatever the
    Connector sent with them became the BATT 1 value, and BATT 2 and ADIRS kept
    their last picture indefinitely.
    Both now clear all three displays and stop there. A picture left standing
    for hours burns into an OLED, and these are exactly the hours nobody is
    looking. The next value the Connector sends redraws its display as usual.
    [SF_OVHD.cpp, SF_OVHD.h]
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2026-09-25 Do not draw on a display driver that never got built
    If the Adafruit driver did not fit in the device arena, OLEDInterface
    reported it and returned with both driver pointers NULL. SF_OVHD::attach
    went on to set _initialised regardless, and every later draw dereferenced
    NULL. And if OLEDInterface itself did not fit, attach() returned early
    leaving oled uninitialised, but set() never looked at _initialised either:
    MFCustomDevice's own flag is set whatever happens inside, so the first value
    from the Connector would have drawn through a wild pointer.
    OLEDInterface now says whether it has a driver, attach() only marks the
    device initialised when it has, and set() does nothing otherwise. The
    Conn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
    [OLEDInterface.h, SF_OVHD.cpp]
2026-09-25 Take the heap out of the redraw path
    The three values from the Connector were Arduino Strings, each holding a
    heap block that was freed and reallocated every time a value came in.
    Battery voltage changes by the hundredth all flight long, so that is a
    steady churn of small allocations on an 8 KB AVR, which is how it ends up
    fragmented and falling over at hour three rather than minute one.
    They are fixed buffers now, sized above what each display can show at its
    font, and a value too long is cut to fit rather than overrunning.
    OLEDInterface loses its String overloads, which nothing calls any more.
    The only allocation left in the linked binary is Adafruit's 1 KB frame
    buffer, taken once in be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
    [OLEDInterface.h, SF_OVHD.cpp]
2026-09-25 Drop the pause after each channel switch, and make begin() alike
    setTCAChannel() slept 5 ms after selecting a channel. The PCA9548A closes
    its switch on the STOP condition, and Wire.endTransmission() does not return
    until the STOP has been sent, so the channel is already live and the pause
    bought nothing. It cost 5 ms on every redraw, 15 ms for the light test, and
    that is time the loop is not reading the serial port.
    The three blocks in begin() had drifted apart: BATT 1 and BATT 2 pushed a
    blank frame before drawing, ADIRS did not. The draw that follows clears the
    buffer and pushes a frame by itself, so none of that survives. All three are
    now the same select, initialise, draw.
    No change t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
    [SF_OVHD.cpp]
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2026-09-25 Ship the module config the board actually runs
    The package's SF OVHD Mainboard.mfmc still described the January board: module
    type "SF OVHD Mainboard Mega", which no firmware reports any more, and a
    lone custom device at 0x70. Loading it from the Connector did not match the
    board, and it would have left every switch and annunciator unconfigured.
    It is replaced by the config on the board since March 2025: 49 buttons, the
    ANN_UPPER and ANN_LOWER shift register chains (4 x 8 bits
    each, i.e. two 16-bit DM13A per chain), and the SF_OVHD custom
    device at 0x71. Module type SF OVHD Mega. No pin is used twice.
    board.json's DeviceConfigs entry now describes it as the whole panel
    rather than "OverHead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
2026-09-25 Let the Connector set the brightness of the three displays
    New messageID 4, Brightness, 0-100. It sets the contrast register of all
    three OLEDs, 0-255 linearly, through a new OLEDInterface::setContrast() that
    covers both drivers. Nothing is redrawn and the picture stays. It is meant
    to follow the ANN LT BRT/DIM switch, which dims these displays in the
    aircraft, or a dimmer knob. On this board neither the annunciators nor
    the backlighting can follow it. The annunciators are set once per colour by
    the DM13A trimmers, and the backlighting by fixed 150-ohm resistors on 9 V.
    The OLEDs at least no longer have to stay at full brightness at night.
    Until the first value arrives nothing is touched, s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
    [OLEDInterface.h, SF_OVHD.cpp, SF_OVHD.h]
2026-09-25 Rewrite both readmes
    The top-level Readme said what the repository holds in three lines and left
    the rest as template placeholders. It now describes the panel and its nine
    sections, what every folder holds, and the mainboard as the KiCad project
    has it: ATmega2560 and CH340G, the 9 V / 5 V / 3.3 V supplies, 24 Korry
    buttons, 11 toggles and three ADIRS rotaries on direct pins, four DM13A,
    one per legend colour, in two chains with a trimmer each, 123 backlight LEDs,
    and three OLEDs behind a PCA9548A. It then gives the order to build one
    in. Two steps nobody would guess are spelled out: the blank ATmega needs
    its bootloader burned through J4 first, and the files in production/ are
    older than th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
2026-09-26 Plan the split of the mainboard into a mainboard and eight section boards
    docs/board-split.md is the design on paper, to review before any KiCad work:
    one mainboard on the case floor, and eight section boards, one per printed
    panel, cut out of the current layout with every hole and every switch where
    it is today. It records the decisions and the reasons for them: mechanics,
    power with a TPS2115A and a separate annunciator rail, I2C pull-ups moved to
    5 V, fixed REXT resistors instead of the trimmers (the trimmer range sat
    several times below the DM13A's minimum REXT, which is why it never did
    anything), PWM dimming of annunciators and backlight on D45 and D44, and a
    pin-by-pin pinout of the e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
2026-09-26 Replace the guessed REXT values with the ones measured on the board
    The plan had taken the DM13A's current from its datasheet and proposed 2-4
    kOhm. On the board that gave dim annunciators. The LED current was
    measured as the step in the 9 V supply current when one LED is switched on,
    and these chips give about a fifth of what the datasheet says: 4.7 kOhm is
    ~4 mA, 300 Ohm is 39 mA, and 680 Ohm is 17-18 mA with the light right on all
    four colours. 680 Ohm it is, on every chip.
    The same measurements show why the trimmer never worked: 56-156 Ohm puts
    the chip at its own output limit, ~80 mA into one LED with the trimmer at
    zero. They also show a chip that stops driving its outputs at a low RE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
2026-09-26 Record the hot-plug lock-up of the DM13A and what the new board does about it
    On the current board, with 680 Ohm on every REXT, the annunciators stay dark
    about 19 times in 20 when the barrel is pushed into a 9 V adapter that is
    already live. They work every time when the barrel is already in and the
    adapter is then plugged into the mains, and they work on the bench supply.
    Two different adapters behave the same. The OLEDs, switches and backlight
    work throughout, and data still passes through the DM13As. Their outputs
    just never turn on, until a full power cycle. The DM13A has no reset, so a
    bad start sticks.
    The lock-up seen earlier at 56 and 300 Ohm was put down to a low REXT. It
    is the s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
2026-09-27 Put back the v1 project as it was sent to JLCPCB, with the rotaries fixed
    The board in the panel was ordered on 3 March 2025. The Gerbers uploaded to
    JLCPCB for that order are byte-identical to production/OverHead_v1.zip,
    exported that evening at 22:08. KiCad backed the project up at 22:06 and
    at 22:26, with the same copper in both. This restores the 22:26 snapshot:
    the board, the schematic sheets and the project files.
    Its one flaw is in the file, not in the copper. On 22 February the three
    ADIRS rotaries used SimPanel:Rotary_SW_8x1_SF, the footprint made for the
    switches actually bought, whose pins sit one position round. By 3 March an
    update from the schematic had put the library Rotary_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
    [OverHead_v1.kicad_pcb, OverHead_v1.kicad_sch, adirs.kicad_sch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]
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2026-09-27 Start the v2 mainboard: power input and the USB / supply-selector sheets
    A new KiCad project, Mainboard/OVHD_Mainboard, self-contained like the FCU
    boards. Its local libraries hold the TPS2115A from the FCU and the TLC5927IDWR
    from the Digi-Key download. The TLC5927 uses the DW24-M land pattern, the
    one with the most toe for a soldering iron. For 3D it points at KiCad's
    SOIC-24W model, since the download has none.
    Power sheet, new. 9 V from the panel jack on a screw terminal. A 1N5822
    against reverse polarity, as on the FCU PSU. An SMBJ12CA and a 470 uF
    electrolytic across the input, against the hot-plug transient that locks
    the TLC5927s. Two MF-RHT200 polyfuses split it into +9V_BL for the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
    [OVHD_Mainboard.kicad_sch, power.kicad_sch, usb_supply.kicad_sch]
2026-09-27 Write the mainboard sheets in KiCad 10's own format, fixing the load error
    KiCad refused to open the two sub-sheets on their own. The one thing it
    rejected was the notes text block, which carried real newlines inside the
    string where KiCad wants the escape \n. Loaded through the root sheet it
    slipped past the ERC, and opened in the editor it gave the error.
    The generator now escapes it. After generating, every sheet, both symbol
    libraries and the footprint library are loaded and re-saved by kicad-cli, one
    file at a time. So each sheet is known to load on its own, and all are in
    the native KiCad 10 format (20260306) rather than the older one they were
    written in. ERC still shows no errors, a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
    [OVHD_Mainboard.kicad_sch, power.kicad_sch, usb_supply.kicad_sch]
2026-09-27 Add the ATmega2560 sheet to the v2 mainboard
    The support circuit is the one on the v1 board: four 100 nF and a 10 uF on
    the MCU rail, 100 nF on AREF, 10k and 22 pF on RESET, and a 16 MHz 7x5 mm
    hand-soldering crystal with two 22 pF.
    The pin map comes from the .mfmc, whose 49 buttons were checked against the
    as-built copper. Every button keeps its ATmega pin, named as in the .mfmc.
    Also on it: the two TLC5927 chains on D22-D27 as in the ShiftRegister
    entries, I2C on D20/D21, the UART to the CH340G, the ISP lines, and the
    three new outputs, D44 BL_PWM, D45 ANN_PWM and D46 TLC_PWR_EN. The other 21
    pins carry no-connect flags. Checked in the exported netlist: all 100 pins
    of U301 on the intende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
    [OVHD_Mainboard.kicad_sch, mcu.kicad_sch, power.kicad_sch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]
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2026-09-27 Complete the mainboard schematic: backlight switch and the eight connectors
    The last sheet carries the backlight dimmer and the section-board
    connectors. The dimmer is an IRLIZ44N low-side switch, as on the FCU, gated
    from D44 through 100R with a 10k pull-down. Each section board gets a
    shrouded IDC header with the pinout in docs/board-split.md, 136 pins over
    eight headers, and a 5.08 mm two-pole terminal for its backlight, +9V_BL
    and the switched return.
    The whole schematic now passes the ERC with no errors and no warnings.
    Checked on the exported netlist: each of the 49 .mfmc buttons runs from its
    v1 ATmega pin to exactly one ribbon pin; each of the 44 annunciators from
    its TLC5927 output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
    [OVHD_Mainboard.kicad_sch, annunciators.kicad_sch, connectors.kicad_sch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]
2026-09-27 Take the schematic as KiCad repaired it: the project file named the FCU's root
    On first open KiCad reported an error it had fixed itself. The cause was
    the project file, copied from the FCU: in KiCad 10, top_level_sheets names
    the root sheet, and it still named FCU_Mainboard_v3.kicad_sch and the
    FCU's root UUID. KiCad adopted that UUID as the root and rewrote every
    symbol's instance path to match.
    The files committed here are the ones KiCad saved after that repair. The
    only differences are the 272 instance paths, one embedded_fonts line and
    the project file's top_level_sheets entry, now naming OVHD_Mainboard. No
    part, value or connection changed, and the ERC is still clean. The build
    script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
    [OVHD_Mainboard.kicad_sch, annunciators.kicad_sch, connectors.kicad_sch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]
2026-09-27 Add the APU trial section board and the shared part library
    Libraries/ holds the custom footprints (Korry, annunciator LED, ADR rotary,
    toggle), extracted from the v1 board, and the Korry and toggle symbols from
    the v1 schematic, with every pin made passive.
    Section_APU/ is the first section board: every v1 part at its v1 place,
    checked pad by pad, D148 as a single-LED string with a new 470 ohm, and the
    SMD IDC 2x5 and JST PH on the back, towards the mainboard. All assembly
    information is on the silkscreen. Routed with Freerouting: ERC 0, DRC 0,
    nothing unconnected, no schematic-parity issues.
    [Section_APU.kicad_pcb, Section_APU.kicad_sch]
2026-09-27 Tidy the APU schematic and put the board on its sheet
    Schematic: parts in spaced groups on the 100 mil grid, reference and value
    outside the symbol body, horizontal on rotated parts, and GND on sideways
    pins as a label instead of a power symbol that crowded its neighbours.
    PCB: moved by (-54, -80) mm onto the middle of the A4 sheet, grid origin at
    v1's (0, 0), title block filled in. Rerouted: ERC 0, DRC 0, nothing
    unconnected, no schematic-parity issues.
    [Section_APU.kicad_pcb, Section_APU.kicad_sch]
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2026-09-27 Add the GPWS section board, from a builder shared by all section boards
    One builder now makes every section board from a short description (v1
    parts, backlight strings, new part positions) and checks it against the v1
    copper, not net names: each switch contact must reach its ATmega pin, each
    annunciator cathode its TLC5927 output, each backlight string must be
    chained as described. APU rebuilt with it: same nets and values, only the
    part descriptions reworded.
    GPWS: 4 Korry, 6 annunciators, 4 strings of two and D139 on its own with a
    new 470 ohm (D140 and R75, its v1 partners, belong to EXT LT). J1 2x7 and
    J2 on the back along the top edge. ERC 0, DRC 0, nothing unconnected, no
    schematic-pa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
    [Section_APU.kicad_pcb, Section_GPWS.kicad_pcb, Section_GPWS.kicad_sch]
2026-09-27 Add the AIR COND section board
    4 Korry (APU BLEED, PACK 1, PACK 2, EXT PWR), 8 annunciators, 6 backlight
    strings of two and D142 on its own. D142's v1 resistor R76 is on this
    board, so it stays in place and becomes 470 ohm; its v1 partner D141 goes
    to SIGNS. R57 belongs to D73's string and moves to ELEC. The builder now
    handles a v1 resistor kept with a new value. J1 2x8 and J2 on the back,
    top edge, left end. ERC 0, DRC 0, nothing unconnected, no schematic-parity
    issues; every switch, annunciator and string checked on the v1 copper.
    [Section_AIRCOND.kicad_pcb, Section_AIRCOND.kicad_sch]
2026-09-27 Add the EXT LT section board
    8 toggles, each contact checked on the v1 copper to its ATmega pin (contact
    1 and contact 3 on the four ON-OFF-ON ones), 15 backlight strings of two
    and D140 on its own with a new 470 ohm on the back: its v1 partners D139
    and R75 were under GPWS. The builder learned toggles (pin numbers on the
    silkscreen, value field off it) and resistor labels spaced by their length.
    ERC 0, DRC 0, nothing unconnected, no schematic-parity issues.
    [Section_EXTLT.kicad_pcb, Section_EXTLT.kicad_sch]
2026-09-27 Add the ADIRS section board and a rotary symbol without the MP pin
    3 ADR rotaries, the GND CTL Korry with its annunciator, 9 backlight strings
    and the ADIRS OLED socket J3, kept where it was. The copper puts IR 3 on
    the middle rotary and IR 2 on the right one, as on the A320 and in the
    .mfmc; the v1 footprint labels had them swapped, the silkscreen now follows
    the copper. The OLED socket is checked on the copper to PCA9548A channel 2.
    Library: OVHD:Rotary_1x8 is KiCad's SW_Rotary_1x8_MP without the MP pin,
    which the v1 footprint does not have; the rotary footprint's silk ring now
    clears its own pads. ERC 0, DRC 0, nothing unconnected, no parity issues.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
    [Section_ADIRS.kicad_pcb, Section_ADIRS.kicad_sch]
2026-09-27 Add the FUEL section board
    7 Korry, 14 annunciators, 7 backlight strings. Three strings had their v1
    resistor across the seam on the ELEC side (R66, R64, R61); each gets a new
    150 ohm on the back beside its LEDs, and the builder checks on the copper
    that the v1 resistor really was on the other board. The ELEC seam is inset
    1 mm here, as D102 and D104 sit 2 mm from it. Korry labels wrap to fit.
    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
    [Section_FUEL.kicad_pcb, Section_FUEL.kicad_sch]
2026-09-27 Add the ELEC section board
    3 Korry (OXY CREW SUPPLY, BATT 1, BATT 2), 5 annunciators, 5 backlight
    strings; D72/D73 had its resistor R57 across the seam on AIR COND and gets
    a new 150 ohm on the back. The BATT 1 and BATT 2 OLED sockets stay in
    place, checked on the copper to PCA9548A channels 0 and 1. ERC 0, DRC 0,
    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
    [Section_ELEC.kicad_pcb, Section_ELEC.kicad_sch]
2026-09-27 Add the SIGNS section board, the last of the eight
    3 ANTI ICE Korry, 6 annunciators, SEAT BELTS, NO SMOKING and EMER EXIT LT
    toggles, 10 backlight strings and D141 + D149 as a new pair on R79: their
    v1 partners were on AIR COND and APU. NO SMOKING is read on contact 1 like
    the other on-off toggles; the builder checks on the copper that v1 had it
    on contact 3, as the document says. ERC 0, DRC 0, nothing unconnected, no
    schematic-parity issues.
    [Section_SIGNS.kicad_pcb, Section_SIGNS.kicad_sch]
2026-09-27 Single-LED backlight strings on 330 ohm, not 470
    A pair of backlight LEDs on 150 ohm runs at 17 mA (Stefano's figure). The
    470 ohm came from an estimated 11 mA per string, which was wrong. For the
    same 17 mA a single LED needs V / (2 I) + 75 ohm = 330 ohm. Changed on APU
    (R3), GPWS (R5), AIR COND (R7, the v1 R76) and EXT LT (R16); the document's
    backlight currents now use 17 mA, ~1.1 A in all. The four boards rebuilt
    and rerouted: ERC 0, DRC 0, nothing unconnected, no parity issues.
    [Section_AIRCOND.kicad_pcb, Section_AIRCOND.kicad_sch, Section_APU.kicad_pcb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]
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2026-09-28 Mainboard 3D models: USB-B, crystals, PTC fuses and IRLIZ44N
    The four footprints whose KiCad model does not exist now point at working
    ones, as fixed on the FCU: the SameSky UJ2-BH-1-TH USB-B and the Bourns
    MF-RHT200, copied into Libraries/3dmodels from the FCU mainboard and PSU;
    the WE 12SMX model for the 7 x 5 mm crystals; the TO-220 lying flat for the
    TO-220F, which has the same outline and pitch. Render only, copper untouched:
    DRC still 0.
    [OVHD_Mainboard.kicad_pcb]
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2026-09-29 Take the R-EXT capacitors off the mainboard: they were the fault
    On the v1 board each TLC5927 has 100 nF from R-EXT to GND, which the
    datasheet's application circuit does not have. With 1 kOhm on R-EXT a
    chip dropped all its outputs to under 1 mA as soon as two or three were
    on together, and kept them there until a power cycle. Supply, R-EXT, OE
    and temperature read the same before and after, and the fault showed
    with both firmwares and both Connector command formats. With C17 removed,
    U6 held all 16 outputs on while U7, still with its capacitor, failed in
    the same test.
    C511-C514 go from the v2 schematic and PCB, with the R-EXT stubs that led
    to them. ERC, DRC and schematic parity stay at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
    [OVHD_Mainboard.kicad_pcb, annunciators.kicad_sch]
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2026-09-29 SF_OVHD 1.2.0: power the TLC5927 up from D46, add the two dimmers
    On the v2 mainboard the four TLC5927 get their supply through a switch
    on D46, off until the firmware turns it on. When the custom device
    starts, it pulls CLK, LE and SDI of both chains low, holds D46 low for
    300 ms, drives it high, and 20 ms later writes both chains again with
    what the Connector last set. Message 5 repeats the sequence on demand.
    The steps run from the custom device's update(), every 10 ms, so the
    loop is never blocked.
    The 300 ms are generous because +5V_TLC has no bleed resistor and the
    datasheet gives no reset threshold.
    The module config gains BL_PWM on D44 and ANN_PWM on D45, and the
    package's board.js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
    [SF_OVHD.cpp, TLCSupply.cpp]
2026-09-29 Bleed +5V_TLC with 4.7 kOhm, so the TLC5927 reset is sure
    When D46 switches the chips off, their supply had only its 10.4 uF and
    the chips' own current to fall by. R527, 4.7 kOhm to GND beside C505,
    gives it a 49 ms time constant: after the firmware's 300 ms about 10 mV
    are left. It costs about 1 mA while the chips are on.
    ERC, DRC and schematic parity stay at zero. The renders, the part counts
    and the firmware comments follow.
    [OVHD_Mainboard.kicad_pcb, annunciators.kicad_sch]
